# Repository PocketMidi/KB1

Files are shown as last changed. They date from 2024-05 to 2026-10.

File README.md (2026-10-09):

# ***KB1*** - Pocket MIDI Keyboard Controller

***KB1*** is a compact MIDI keyboard controller built specifically for the Polyend Tracker Mini. It is configured via a browser-based web app connected via Bluetooth Low Energy.

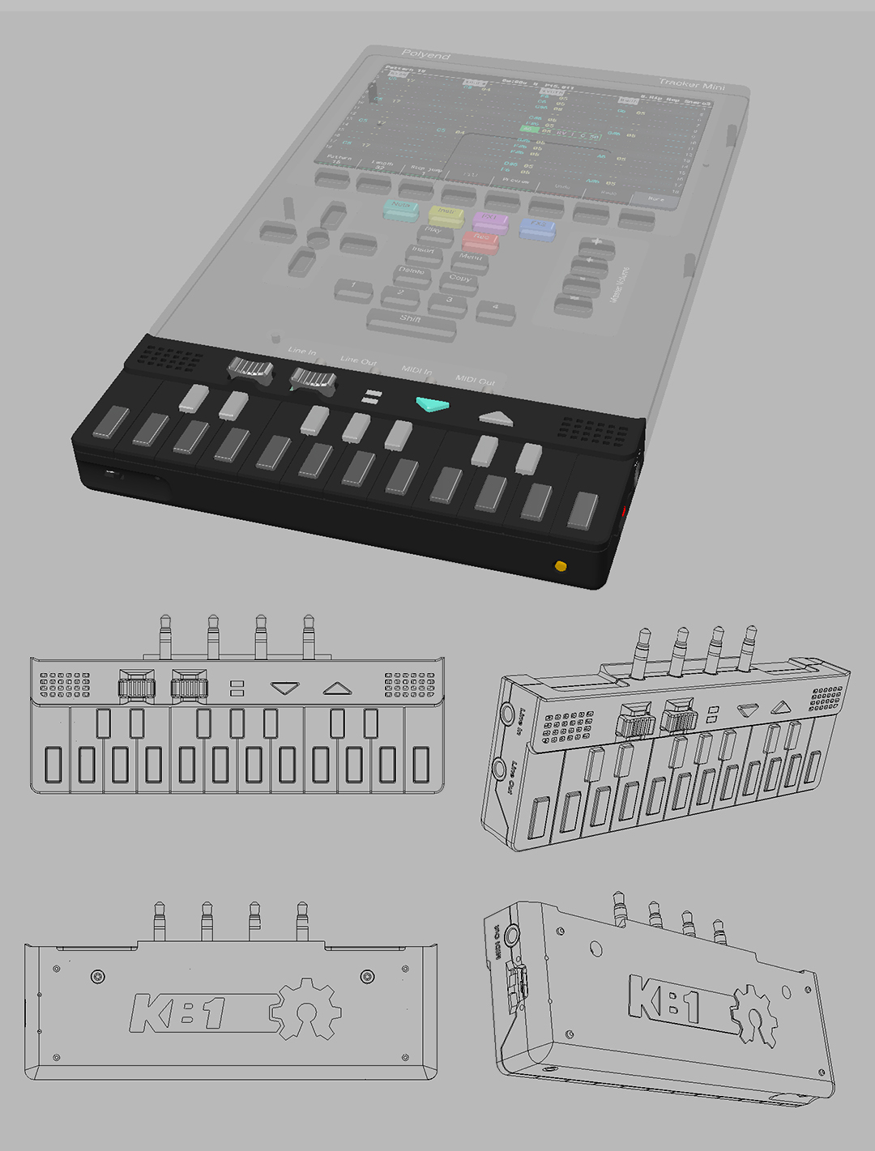
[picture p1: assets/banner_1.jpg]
KB1 banner


## System Overview

**Hardware**
- 19-key keyboard
- 2 levers with integrated push buttons
- 1 capacitive touch input
- 2× 8Ω 1W speakers
- XIAO ESP32-S3 MCU with BLE and USB-C
- 420mAh Li-ion battery, charged via USB-C 

**Firmware** ([details](firmware/README.md))
- Lever, press, and touch controls: configurable CC output and parameter-specific behavior
- Scale mode: note output quantized to a selectable musical scale
- Chord mode: selectable chord types, Block/Strum playback, and 1–3 octave range
- Arp Mode: User defined arpeggiator
- 8 on-device preset slots
- Serial MIDI output

**Web Configuration App** ([details](https://github.com/PocketMidi/KB1-config)) 
- Mobile first design
- Runs in Chromium based browsers (**iOS**: Safari does not support Web Bluetooth. [V Browser ](https://vbrowser.co) recommended for iOS)
- Connects over Web Bluetooth
- Settings load from and save to device over BLE
- 12-slider live performance interface (landscape fullscreen on mobile)
- Preset management stored in browser

## Documentation

- [KB1 Studio User Guide and Tools](https://pocketmidi.github.io/KB1-studio/): Hardware setup, charging, Tracker configuration, firmware updates, and instrument building.
- [Configurator User Guide](https://github.com/PocketMidi/KB1-config/blob/main/docs/USER_GUIDE.md): Current app settings, presets, and performance sliders.
- [Firmware README](firmware/README.md): Development builds and complete release images.
- [Hardware Design and Assembly](hardware/README.md): Electronic and mechanical files.
- [Contributing](CONTRIBUTING.md): Shared conventions, documentation ownership, and release validation.

Each repository README covers its own setup. Detailed user instructions live in the guides above rather than repeated copies.

## Building from Source

- [Firmware build and upload](firmware/README.md#development-build); use the [complete-image builder](firmware/README.md#complete-release-images) for distributable firmware.
- [Configurator development](https://github.com/PocketMidi/KB1-config#development).
- [Studio development](https://github.com/PocketMidi/KB1-studio#development--deployment).

## Gallery

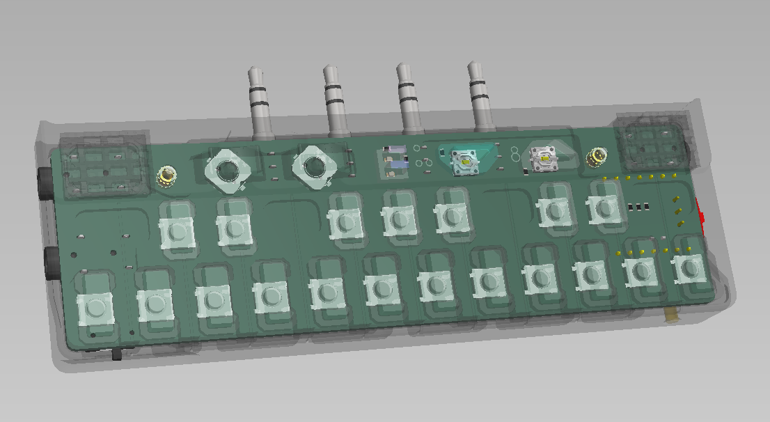
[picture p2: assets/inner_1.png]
inner top

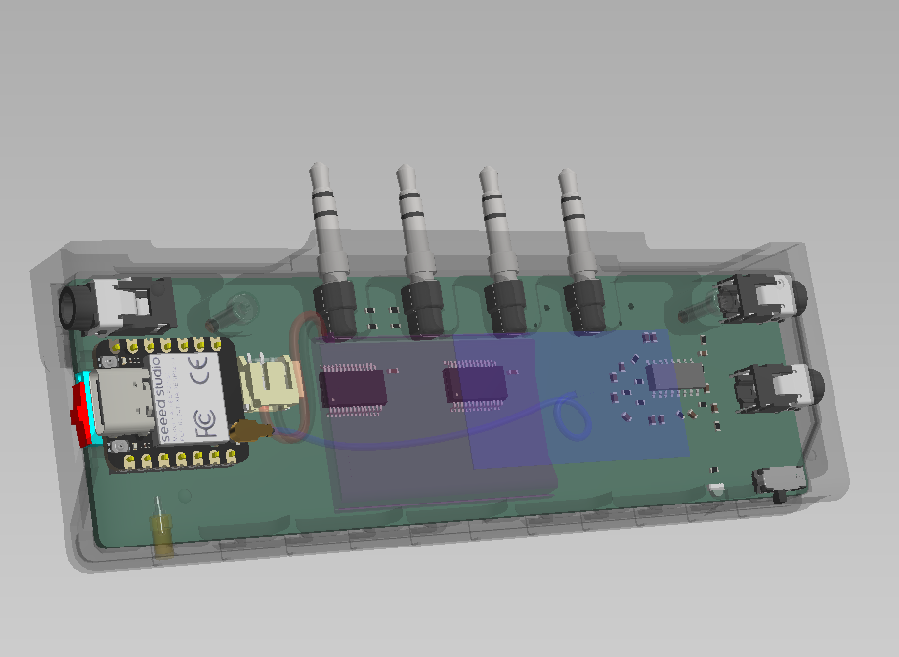
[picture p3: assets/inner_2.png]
inner bottom


## License

- **Software & Firmware**: MIT License (see LICENSE)
- **Hardware Designs**: CERN Open Hardware Licence v2 – Strongly Reciprocal (see [hardware license](hardware/LICENSE.txt))

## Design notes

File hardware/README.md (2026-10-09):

## Hardware

* This folder contains the electronic and mechanical hardware files for building and assembling the KB1.
* For further reference check out the [hardware reference](../references/hardware) folder.

* [Assembly guide](KB1_assembly_guide.pdf)
* [Electronics](electronics/README.md): PCB, schematics, Gerbers, and BOM.
* [Mechanicals](mechanicals/README.md): Printable enclosure parts and desktop stand.
* [KB1 Studio User Guide](https://pocketmidi.github.io/KB1-studio/): Current operating and charging instructions.

## License

All hardware design files in this directory are licensed under the
CERN Open Hardware Licence Version 2 – Strongly Reciprocal (CERN-OHL-S v2).
See [LICENSE.txt](LICENSE.txt).

OSHWA UID
US002800
https://certification.oshwa.org/us002800.html

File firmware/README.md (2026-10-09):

# KB1 Firmware

Embedded firmware for the handcrafted PocketMidi KB1 MIDI controller, built with PlatformIO and Arduino for the Seeed XIAO ESP32-S3.

## Capabilities

- Scale, Chord (Block/Strum), and Arp keyboard modes.
- Configurable lever, press, and capacitive touch controls.
- Serial MIDI output, with BLE configuration and real-time CC control from the companion app.
- Eight device preset slots and persistent settings.
- Idle sleep, touch wake, and time-based battery tracking.

## User Documentation

Use these maintained guides instead of a duplicate settings reference here:

- [KB1 Studio User Guide](https://pocketmidi.github.io/KB1-studio/): Hardware setup, charging, LED signals, and Tracker MIDI settings.
- [Configurator User Guide](https://github.com/PocketMidi/KB1-config/blob/main/docs/USER_GUIDE.md): Current app labels and control behavior.
- [KB1 Configurator](https://pocketmidi.github.io/KB1-config/): Wireless settings and performance sliders.

Bluetooth must be enabled using the inward-lever hold gesture before pairing with the Configurator. Charging and calibration instructions are maintained in the guides above, not duplicated here.

## Development Build

Install [PlatformIO](https://platformio.org/) and run from this directory:

```bash
pio run --environment seeed_xiao_esp32s3
pio run --target upload --environment seeed_xiao_esp32s3
pio device monitor
```

PlatformIO uploads the appropriate components to their correct offsets. Edit [platformio.ini](platformio.ini) for build or port settings.

## Complete Release Images

**Never distribute the app-only binary as a complete image.** Flashing the app partition at offset `0x0` will not boot.

```bash
bash build_complete.sh
```

[build_complete.sh](build_complete.sh) builds and merges:

| Component | Offset |
|---|---|
| Bootloader | `0x0` |
| Partition table | `0x8000` |
| Application | `0x10000` |

The script targets ESP32-S3 with DIO, 80 MHz, and 8 MB flash. Output is `../kb1-studio/dist/firmware/KB1-firmware-vX.Y.Z.bin`.

For browser flashing, use [KB1 Studio's Flash Tools](https://pocketmidi.github.io/KB1-studio/) on a desktop browser with Web Serial (Chrome, Edge, or Opera). Normal updates back up and restore NVS, preserving calibration, settings, and presets. **Clear device data on update** intentionally skips preservation.

For release coordination and hardware validation, see [CONTRIBUTING.md](../CONTRIBUTING.md).

## Source Layout

- [src/main.cpp](src/main.cpp): Setup, tasks, battery tracking, and main loop.
- [src/bt/](src/bt/): BLE services and callbacks.
- [src/controls/](src/controls/): Keyboard, lever, press, touch, octave, and sleep behavior.
- [src/led/](src/led/): LED feedback.
- [src/music/](src/music/): Scales, chords, and patterns.
- [src/objects/](src/objects/): Constants, shared state, and settings structures.

BLE, touch, and all I2C work must remain on Core 1. Do not split the two GPIO expanders or input/LED I2C tasks across cores.

## Historical Notes

These are development snapshots, not current setup instructions or verified current performance claims:

- [I2C efficiency analysis](I2C_EFFICIENCY_ANALYSIS.md)
- [Bulk-read implementation proposal](I2C_BULK_READ_IMPLEMENTATION_PLAN.md)
- [Additional optimization proposals](ADDITIONAL_PERFORMANCE_OPPORTUNITIES.md)
- [Archived Arduino firmware](initial_arduino_code/README.md)

## License

See the repository [LICENSE](../LICENSE).

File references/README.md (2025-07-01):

## Reference Material

* This folder contains all the collected reference material for various aspects of the project

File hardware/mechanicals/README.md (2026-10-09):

### This folder contains the CAD files needed to print your own KB1 mechanical parts along with a Desktop Stand.

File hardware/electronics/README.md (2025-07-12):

## This folder contains schematics, Gerbers, and BOM to build the KB1's pcb. 
## Or you can order directly from [PCBWAY](https://www.pcbway.com/project/shareproject/KB1v8_1_kicad_pcb_bab0b2c0.html)

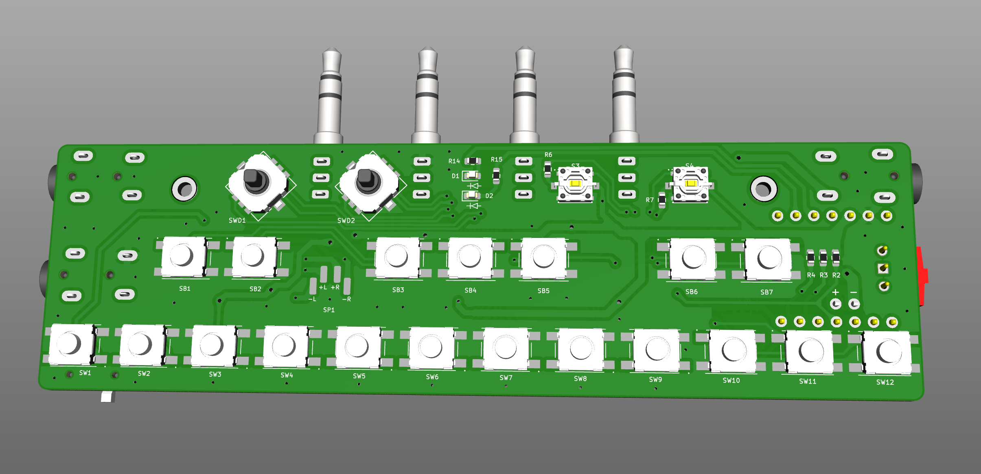
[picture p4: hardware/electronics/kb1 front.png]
PCB top

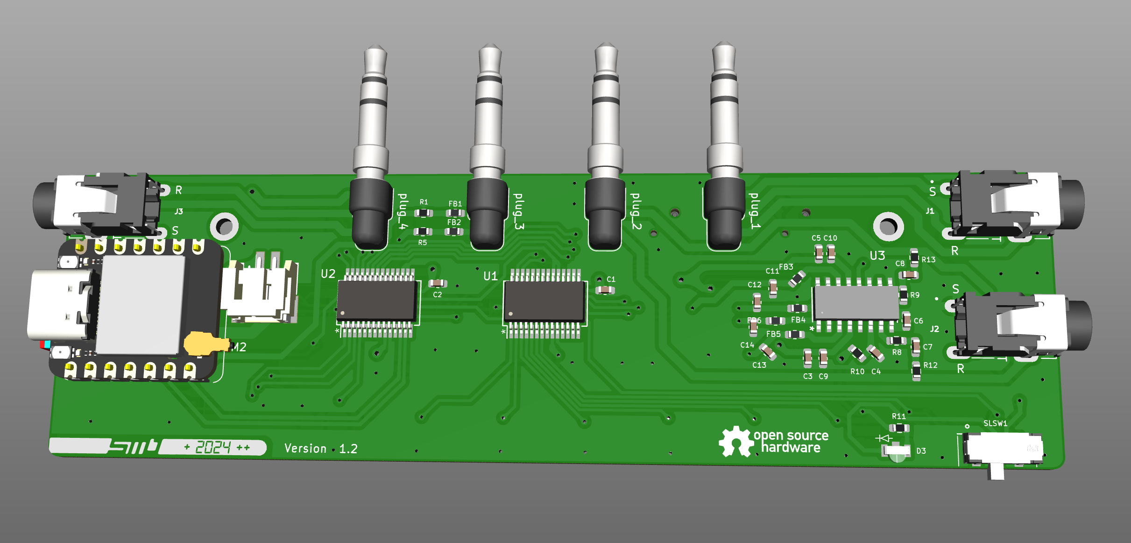
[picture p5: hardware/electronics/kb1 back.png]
PCB bottom


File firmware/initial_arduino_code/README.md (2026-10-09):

> [!WARNING]
> This is the initial Arduino based source code for the firmware. It is no longer actively developed or maintained. 

For current builds and behavior, see the [firmware README](../README.md). Core assignments, LED meanings, and control mappings below describe this archived code only; do not use them as conventions for current firmware.

## KB1 Firmware v1.1 Source Code Summary

### Introduction

> [!Note]
> This code uses the ESP32 platform, which supports FreeRTOS and allows for multicore programming.

* The **buttonReadTask** function is running on **Core 1**, and the loop function (which contains the main MIDI processing logic) is running on **Core 0**.
* The code initializes the MCP23X17 GPIO expanders, and MIDI objects. 
* Then, it configures the buttons and starts the **buttonReadTask** on **Core 1** using FreeRTOS. 
* The **buttonReadTask** continuously reads the state of buttons connected to the MCP23X17 GPIO expanders. 
  It checks for button presses and releases, triggering MIDI values or other tasks accordingly. 
* The button processing and MIDI functions are separated, allowing the MIDI processing to continue in the background on **Core 0** while the button reading occurs on Core 1. This approach ensures that time-sensitive MIDI processing is not affected by potential delays caused by button reading or other tasks running on **Core 1**. 
* The loop function runs on **Core 0** handling notes, velocities, and octaves. *OCT_DN* and *OCT_UP* buttons modulate octaves, signifying transitions through rhythmic pulsations of their LEDs. Two Levers adjust parameters such as "finetune" (midi cc#3), "sustain", and note velocities during prolonged activation, visually represented by by pink and blue LEDs.

### Libraries

This firmware utilizes the Arduino framework for the [Xiao ESP32S3 board](https://wiki.seeedstudio.com/xiao_esp32s3_getting_started/). 

*It is recommended to follow the Getting Started Guide in the link above when using the Arduino IDE and grab the latest board manager from Espressif.*

#### Additional Libraries:
[Adafruit MCP23017 Library](https://github.com/adafruit/Adafruit-MCP23017-Arduino-Library)

[Arduino Midi Library](https://github.com/FortySevenEffects/arduino_midi_library)

[FreeRTOS Library](https://github.com/feilipu/Arduino_FreeRTOS_Library)

These are installable in the Arduino IDE, or as external packages.

### Input Mapping:

[KB1 Connection Map](https://github.com/PocketMidi/KB1/blob/main/Firmware/Reference/KB1_Connection_Map_FW_v1.0.csv)
#### MIDI Notes (Keys):
Various buttons on U1 and U2 pins are mapped to MIDI notes and control changes.

#### MIDI Control Changes (Lever 1):
*SWD1_Right* sends MIDI control change number 3 on channel 1 with values 127 when pressed and 64 when released. 

*SWD1_Center* triggers MIDI "sustain" mode. *Pink LED* pulses while active.

*SWD1_Left* sends MIDI control change number 3, value 0 when pressed, and 64 when released.

#### MIDI Note Velocity Changes “Lever 2”:
*SWD2_Right* increments note velocity by 8 upon button press all the way up to 127. *Blue LED* indicates increase.

*SWD2_Center* sets note velocity to 80 when pressed. *Blue LED* indicates reset.

*SWD2_Left* decrements note velocity by 8 on button press all the way down to 8. *Blue LED* indicates decrease.

#### MIDI Octave Changes:
*OCT_DN* blinks at different rates based on the octave level decrease.

*OCT_UP* blinks at varying speeds with octave level increase.

Simultaneous pressing of both octave buttons resets the octave level.

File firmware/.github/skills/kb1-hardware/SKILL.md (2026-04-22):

---
name: kb1-hardware
description: KB1 hardware specifications, schematics, and component details. Use when working on hardware integration, debugging electrical issues, understanding pin assignments, audio system, battery system, or planning hardware modifications. Contains full schematic (MCP23017 I2C expanders, PAM8406 audio amp, XIAO ESP32-S3 MCU, battery system), measured power consumption, and hardware roadmap decisions.
---

# KB1 Hardware Reference

Complete hardware specifications for the KB1 MIDI controller.

## System Overview

**MCU:** XIAO ESP32-S3 (dual-core Xtensa LX7, 240MHz)  
**Power:** 3.7V Li-ion 420mAh battery  
**I/O Expansion:** 2× MCP23017 I2C GPIO expanders  
**Audio:** PAM8406DR Class-D amplifier + 2× 8Ω 1W speakers  
**Connectivity:** BLE MIDI, Serial MIDI (UART), USB-C

---

## Full Schematic — Rev B.0 (2023-12-17)

### MCU: XIAO-ESP32S3 (H2)
- **Decoupling:** C1 (0.1uF) on power
- **I/O Pins Used:** D0-D10, SDA, SCL, MOSI, MISO
- **Touch Inputs:** Touch 1, Touch 2 (capacitive GPIO)
- **I2C Bus:** SDA/SCL shared with both MCP23017 expanders

### Power Section
- **Battery:** 3.7V Li-ion 420mAh via 4-wire connector (128-PH-SHI-TH_IF_S4)
- **Power Switch:** S6 (main power)
- **Charging:** XIAO built-in 100mA charge controller
  - **CRITICAL:** Requires USB enumeration (dumb chargers won't work)
  - **Charge Time:** ~5 hours (BATTERY_FULL_CHARGE_MS = 18000000)

### I2C GPIO Expanders (2× MCP23017)

#### U1: MCP23017-E/SS — I2C Address 0x20
- **Interrupt Lines:** INTA, INTB (not currently used in firmware)
- **Ports:** GPA0-7, GPB0-7 (16 GPIO pins total)
- **Connected To:**
  - Keyboard matrix switches
  - Lever 1 switches (left/right/push)
  - Lever 2 switches (left/right/push)
  - Some LED outputs

#### U2: MCP23017-E/SS — I2C Address 0x21
- **Ports:** GPA0-7, GPB0-7 (16 GPIO pins total)
- **Connected To:**
  - Keyboard matrix switches
  - Octave Up/Down buttons
  - Octave LED outputs (GPB0 = addr_15 LED indicator)
  - Additional control inputs

**I2C Shared Bus:**
- Clock Speed: 400kHz (Fast Mode I2C)
- Pull-ups: 4.7kΩ on SDA/SCL lines
- **CRITICAL:** Both expanders MUST be accessed from same core (Core 1)

### Lever Controls

**Lever 1:**
- Switch: S1 (H14, MSS1 type indicator)
- Slider: SW01 (KI-5203JA-05) — Left/Right positions
- Push Button: Integrated in slider mechanism

**Lever 2:**
- Switch: S2 (H15, MSS1 type indicator)
- Slider: SW02 (KI-5203JA-05) — Left/Right positions
- Push Button: Integrated in slider mechanism

### Keyboard Switches

**19-Key MIDI Keyboard** — All SPST switches via MCP23017 GPIO  
MIDI note assignments and reference frequencies:

| Switch | MIDI Note | Note Name | Frequency |
|---|---|---|---|
| SW3 | 72 | C5 | 523.25 Hz |
| SW4 | 71 | B4 | 493.88 Hz |
| SW5 | 75 | Eb5 | 622.25 Hz |
| SW6 | 76 | E5 | 659.25 Hz |
| SW7 | 73 | C#5 | 554.37 Hz |
| SW8 | 74 | D5 | 587.33 Hz |
| SW9 | 67 | G4 | 392.00 Hz |
| SW10 | 68 | G#4/Ab4 | 415.30 Hz |
| SW11 | 69 | A4 | 440.00 Hz |
| SW12 | 70 | A#4/Bb4 | 466.16 Hz |
| (aux)  | 59 | B3 | 246.94 Hz |
| (aux)  | 60 | C4 | 261.63 Hz (Middle C) |
| (aux)  | 61 | C#4 | 277.18 Hz |
| (aux)  | 64 | E4 | 329.63 Hz |
| (aux)  | 65 | F4 | 349.23 Hz |

### Octave Controls

**Octave Up Button:**
- Connected to U2 (MCP23017 @ 0x21)
- LED: SP51 Blue LED with current-limiting resistor R6

**Octave Down Button:**
- Connected to U2 (MCP23017 @ 0x21)
- LED: SP51 Blue LED with current-limiting resistor R6

---

## Audio System — PAM8406 Amplifier

### Amplifier IC: U3 PAM8406DR

**Type:** Class-D, BTL (Bridge-Tied Load) stereo output  
**Input:** 3.7V Li-ion direct (no boost converter)  
**Configuration:**

| Pin | Function | Connection |
|-----|---|---|
| 5 | MUTE | Via R10 (10Ω) |
| 7 | INL | 20kΩ R12 + 1µF C7 AC coupling |
| 9 | MODE | Pulled LOW = Class-D mode (efficient) |
| 10  | INR | 20kΩ R13 + 1µF C8 AC coupling |
| 12  | SHDN | Controlled by SLSW1 slide switch |
| 1/3 | +OUT_L / -OUT_L | BTL left channel → SP1 L+/L- |
| 14/16 | -OUT_R / +OUT_R | BTL right channel → SP1 R+/R- |

### Audio Connectors

- **plug_2:** 3.5mm TRS — Line In from PTM "Line Out" (input to amp)
- **J1:** 3.5mm TRS — Line Out to PTM "Line In" (pass-through)
- **J2:** 3.5mm TRS — Connected to amp input path

### Speakers: SP1 (Stereo Pair)

**Model:** Ole Wolff OWS-111535TA-8A  
**Impedance:** 8Ω  
**Power:** 1W nominal per speaker  
**Sensitivity:** 79dB SPL @ 1W/1m  
**Connector:** 4-pin (L+, L-, R+, R-)

### Speaker Control & Indicator

**SLSW1 Slide Switch:** JS202011JAQN  
- Hardware control of PAM8406 SHDN pin 12
- No firmware involvement (purely hardware on/off)

**D3 Green LED:** Speaker power indicator  
- Current limiting: R11 (100Ω)
- Illuminates when amp is active

### Power Filtering & EMI Suppression

**Input Power Filtering:**
- VDD side: C3 (10µF) + C9 (1µF) + R10 (10Ω) + C4 (1µF) + C6 (1µF)
- PVDD side: C5 (10µF) + C10 (1µF)

**Output EMI Filtering:**
- FB3-FB6: 120Ω @ 100MHz ferrite beads on all 4 BTL output lines
- C11-C14: 220pF capacitors on speaker output lines for HF noise suppression
- ~3-inch twisted wire runs to speakers to reduce radiated EMI

### Measured Power Consumption

**Amplifier Current Draw:**
- **Idle** (on, no signal): 2-10mA
- **With music** (during system sleep test): ~48mA average
  - Sleep test: 99% battery → 8hr 15min runtime
  - Calculation: 416mAh ÷ 8.25hr = 50.4mA total (close to observed)
- **Active system + amp:** 95mA base + 50mA amp ≈ 145mA total
- **Peak draw:** Up to 550mA (heavy bass at max volume)

**Battery Runtime Estimates:**
- **Active with speakers:** ~2.9 hours from full charge
- **Active without speakers:** ~4.4 hours from full charge
- **BLE connected, idle:** ~8.4 hours
- **BLE disconnected, idle:** ~8.4 hours (same, BLE drain is minimal)

---

## MIDI I/O Section

**Hardware:** 3.5mm TRS Type-A MIDI connectors (T=source, R=sink, S=shield)

**plug_3:** MIDI OUT to PTM "MIDI IN"  
- Connector: AudioJack3_1503-08 (J3)
- EMI: FB1 ferrite bead on signal line

**plug_4:** MIDI IN from PTM "MIDI OUT"  
- Connector: AudioJack3_1503-08
- EMI: FB2 ferrite bead on signal line

**Interface:** Serial UART (Serial0, 31,250 baud)  
**NOT USB MIDI** — KB1 does not support USB MIDI class device mode

---

## Battery System & Hardware Roadmap

### Current Implementation (KB1.5)

**Software-Based Monitoring:**
- Time-based capacity estimation
- Tracks: BLE on/off time, sleep time, speaker time
- Requires: Full charge calibration by user
- Accuracy: ±5-10% when calibrated
- NVS persistence for state across reboots

**Current Drain Estimates:**
- Active (BLE connected): 95mA
- Active (BLE disconnected): 50mA
- Sleep mode: 2mA
- Speaker amplifier: +50mA (flat rate, conservative)

### SY6410 Hardware Gauge Decision (April 2026)

**Conclusion:** Skip for KB1.5, defer to KB2 or >500 unit production

**Why Skip:**
1. Development cost ($3-5K) >> BOM savings at 50-100 unit scale
2. Support fragmentation: Two hardware variants to maintain
3. No user complaints about current accuracy (only persistence bugs, now fixed v1.6.2)
4. Diminishing returns: 2% vs 5% accuracy not perceptible in real use

**When to Revisit:**
- Production scale exceeds 500 units/year
- Doing full PCB redesign for other reasons (marginal cost negligible)
- User feedback shows battery accuracy is pain point
- KB2 new hardware revision with other changes

### Future Implementation (KB2)

**If Adding SY6410 I2C Battery Gauge:**

**Hardware Integration:**
- IC: SY6410AAC (SOT-23-6 package)
- I2C Address: 0x55 (no conflict with MCP23017 @ 0x20/0x21)
- Placement: Power section near battery connector
- Connections:
  - CELL pin: Direct short trace to Battery+ terminal
  - GND pin: Direct to Battery- terminal
  - VDD: 3.3V from ESP32 LDO
  - SDA/SCL: Connect to existing I2C bus (parallel with MCP23017s)
- Decoupling: 1µF on CELL, 1µF on VDD
- Pull-ups: 4.7kΩ (if not already present on I2C bus)

**Firmware Changes:**
- New driver: `src/battery/SY6410.cpp` for I2C communication
- Extend battery status BLE characteristic from 10 to 12 bytes:
  - Byte 10: Hardware version (1=KB1, 2=KB1.5, 3=KB2)
  - Byte 11: Data source (0=software, 1=hardware gauge)
- Runtime detection: Probe I2C 0x55 on boot, fall back to software if not present
- Keep software estimation code for backward compatibility

**Config App Changes:**
- Update `BatteryStatus` interface with optional fields: `hardwareVersion`, `dataSource`
- Update `decodeBatteryStatus()` for backward compatibility (10/12 byte packets)
- Add UI badge: "⚡ Hardware Gauge" vs "📊 Estimated"

**Benefits:**
- ±2-3% accuracy (vs ±5-10% software)
- No calibration required ("it just works")
- Built-in temperature compensation
- Self-calibrating algorithm
- Future features: battery health monitoring, cycle count, predictive replacement

**Power Impact:** ~75µA quiescent (negligible vs 420mAh capacity)  
**BOM Cost:** $0.30-0.50 per unit + 2× 1µF caps ($0.10)

---

## Design Notes & Constraints

### I2C Bus Constraints

- **Shared Bus:** All I2C devices on single SDA/SCL pair
- **Speed:** 400kHz (Fast Mode) — tested safe, optimal for KB1
- **Maximum Speed:** 1.7MHz (MCP23017 datasheet spec)
- **Core Affinity:** ALL I2C operations MUST occur on Core 1 (ESP32 driver limitation)
- **Cross-Core Access:** WILL cause `Unfinished Repeated Start transaction!` crash

### Power Budget Breakdown

| State | Current Draw | Runtime (420mAh) |
|---|---|---|
| Active, BLE on, speakers on | 145mA | 2.9 hours |
| Active, BLE on, speakers off | 95mA | 4.4 hours |
| Idle, BLE connected | 50mA | 8.4 hours |
| Sleep mode | 2mA | 210 hours (8.75 days) |
| Charging (USB enumerated) | 100mA input | 5 hours to full |

### Charging Behavior (CRITICAL)

**USB at boot sequence:**
1. Device boots with USB already connected
2. Charge controller enters **bypass/power mode**
3. Device is powered, battery is NOT charging
4. Firmware detects: `usbConnectedAtBoot = true`
5. Battery monitoring: Stays "uncalibrated" (254), shows "?" in GUI

**Battery boot → USB plug sequence:**
1. Device boots on battery power only
2. User plugs USB after boot
3. Charge controller enters **charging mode**
4. Device is powered AND battery is charging
5. Firmware detects: `usbConnectedAtBoot = false`, `isChargingMode = true`
6. Battery monitoring: Runs calibration timer, tracks charge progress

**Why this matters:**
- Firmware MUST detect boot sequence to determine if battery is actually charging
- Early detection: `usbConnectedAtBoot = isUsbPowered()` BEFORE `loadBatteryState()`
- Invalid sequence (USB at boot): Hardware NOT charging → don't run timer → user must power cycle
- Valid sequence (battery → USB): Hardware IS charging → run timer → track toward 100%

---

## Revision History

- **April 22, 2026:** Migrated from `/memories/repo/` to `.github/skills/kb1-hardware/`
- **April 12, 2026:** Battery hardware roadmap — decision to skip SY6410 for KB1.5
- **March 22, 2026:** Audio hardware power measurements and speaker compensation model
- **December 17, 2023:** Schematic Rev B.0 finalized (KiCad 9.0.7)

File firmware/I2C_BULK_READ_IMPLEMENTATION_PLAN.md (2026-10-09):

# I2C Bulk Read Implementation Plan

> **Historical proposal (April 2026), not a current implementation guide.** The steps and code snippets below are preserved for context, not instructions to apply verbatim. Expected performance and power savings are estimates, not current measurements. See the [firmware README](README.md) for maintained documentation.

**Goal:** Reduce I2C transactions from 25+ to 2 per scan cycle (12× speedup, 92% reduction)  
**Expected Impact:** -5ms input latency, -8-12mA power consumption, smoother overall performance

---

## Phase 1: Create Infrastructure (30 min)

### Step 1.1: Add Bulk Read Support to Globals
**File:** `src/objects/Globals.h`

Add after the `key` struct definition:

```cpp
// GPIO cache structure for bulk I2C reads
struct GPIOCache {
    uint16_t u1_pins;     // All 16 pins from MCP U1
    uint16_t u2_pins;     // All 16 pins from MCP U2
    unsigned long timestamp; // When this snapshot was taken
    
    // Helper: Check if a pin is LOW (pressed) on U1
    inline bool isU1PinLow(uint8_t pin) const {
        return !(u1_pins & (1 << pin));
    }
    
    // Helper: Check if a pin is LOW (pressed) on U2
    inline bool isU2PinLow(uint8_t pin) const {
        return !(u2_pins & (1 << pin));
    }
};
```

**Test:** Compile, verify no errors

---

### Step 1.2: Create Bulk Read Function
**File:** `src/main.cpp`

Add this function before `readInputs()` (around line 1370):

```cpp
// Bulk read all GPIO pins from both MCP chips in just 2 I2C transactions
// Returns cached pin states for efficient extraction
GPIOCache readAllGPIO() {
    GPIOCache cache;
    if (xSemaphoreTake(i2cMutex, portMAX_DELAY) == pdTRUE) {
        cache.u1_pins = mcp_U1.readGPIOAB();  // Read all 16 pins from U1
        cache.u2_pins = mcp_U2.readGPIOAB();  // Read all 16 pins from U2
        cache.timestamp = micros();            // High-precision timestamp
        xSemaphoreGive(i2cMutex);
    } else {
        // Mutex timeout (shouldn't happen, but be safe)
        cache.u1_pins = 0xFFFF;  // All pins HIGH (released)
        cache.u2_pins = 0xFFFF;
        cache.timestamp = micros();
    }
    return cache;
}
```

**Test:** Compile, verify no errors

---

## Phase 2: Refactor Lever/Button Reads (15 min)

### Step 2.1: Update Lever Reading in readInputs()
**File:** `src/main.cpp`  
**Location:** Lines 1374-1387 (current lever reading code)

**Replace this:**
```cpp
// Read lever states FIRST (for BLE gesture detection before lever MIDI processing)
bool lever1Right, lever2Right, lever1Left, lever2Left, leverPush1Pressed, leverPush2Pressed;
if (xSemaphoreTake(i2cMutex, portMAX_DELAY) == pdTRUE) {
    lever1Right = mcp_U2.digitalRead(SWD1_RIGHT_PIN) == LOW;
    lever2Right = mcp_U2.digitalRead(SWD2_RIGHT_PIN) == LOW;
    lever1Left = mcp_U1.digitalRead(SWD1_LEFT_PIN) == LOW;
    lever2Left = mcp_U2.digitalRead(SWD2_LEFT_PIN) == LOW;
    leverPush1Pressed = mcp_U1.digitalRead(SWD1_CENTER_PIN) == LOW;
    leverPush2Pressed = mcp_U2.digitalRead(SWD2_CENTER_PIN) == LOW;
    xSemaphoreGive(i2cMutex);
}
```

**With this:**
```cpp
// BULK READ: Get all 32 GPIO pins in just 2 I2C transactions
GPIOCache gpioCache = readAllGPIO();

// Extract lever states from cached pin data (no I2C overhead)
bool lever1Right = gpioCache.isU2PinLow(SWD1_RIGHT_PIN);
bool lever2Right = gpioCache.isU2PinLow(SWD2_RIGHT_PIN);
bool lever1Left = gpioCache.isU1PinLow(SWD1_LEFT_PIN);
bool lever2Left = gpioCache.isU2PinLow(SWD2_LEFT_PIN);
bool leverPush1Pressed = gpioCache.isU1PinLow(SWD1_CENTER_PIN);
bool leverPush2Pressed = gpioCache.isU2PinLow(SWD2_CENTER_PIN);
```

**Test:** 
1. Compile and flash
2. Test lever controls (left/right, center push)
3. Monitor serial output for correct lever behavior

---

## Phase 3: Refactor Keyboard Scanning (45 min)

### Step 3.1: Add GPIO Cache Parameter to KeyboardControl
**File:** `src/controls/KeyboardControl.h`

**Modify `updateKeyboardState()` signature:**
```cpp
// OLD:
void updateKeyboardState() {

// NEW:
void updateKeyboardState(const GPIOCache& gpioCache) {
```

**Update the keyboard scanning loop** (around line 393):

**Replace this:**
```cpp
// Debounced key scanning
for (int i = 0; i < MAX_KEYS; ++i) {
    auto & key = _keys[i];
    bool raw = !key.mcp->digitalRead(key.pin);  // ❌ Individual I2C call
    // ... rest of debounce logic
}
```

**With this:**
```cpp
// Debounced key scanning (using cached GPIO states, zero I2C overhead)
for (int i = 0; i < MAX_KEYS; ++i) {
    auto & key = _keys[i];
    
    // Extract pin state from cache based on which MCP this key is on
    bool raw;
    if (key.mcp == &mcp_U1) {
        raw = gpioCache.isU1PinLow(key.pin);
    } else {  // key.mcp == &mcp_U2
        raw = gpioCache.isU2PinLow(key.pin);
    }
    
    // Rest of debounce logic unchanged
    if (raw != key.lastReading) {
        key.lastDebounceTime = millis();
        key.lastReading = raw;
    }
    
    // ... rest of existing code unchanged
}
```

**Test:**
1. Compile and flash
2. Play all 19 keyboard keys
3. Test octave shifting
4. Test in both Scale and Chord modes

---

### Step 3.2: Update begin() to Use Cached Reads
**File:** `src/controls/KeyboardControl.h`  
**Location:** `begin()` method (around line 67)

**Replace this:**
```cpp
void begin() {
    for (auto & key : _keys) {
        key.mcp->pinMode(key.pin, INPUT_PULLUP);
        bool raw = !key.mcp->digitalRead(key.pin);  // ❌ Individual I2C call
        key.lastReading = raw;
        // ...
    }
}
```

**With this:**
```cpp
void begin() {
    // Configure all pins as INPUT_PULLUP first
    for (auto & key : _keys) {
        key.mcp->pinMode(key.pin, INPUT_PULLUP);
    }
    
    // Then do ONE bulk read to initialize states
    GPIOCache initialCache;
    initialCache.u1_pins = mcp_U1.readGPIOAB();
    initialCache.u2_pins = mcp_U2.readGPIOAB();
    initialCache.timestamp = micros();
    
    // Set initial states from bulk read
    for (auto & key : _keys) {
        bool raw;
        if (key.mcp == &mcp_U1) {
            raw = initialCache.isU1PinLow(key.pin);
        } else {
            raw = initialCache.isU2PinLow(key.pin);
        }
        key.lastReading = raw;
        key.debouncedState = raw;
        key.state = raw;
        key.prevState = raw;
        key.lastDebounceTime = millis();
    }
    
    resetAllKeys();
}
```

**Note:** You'll need to add `#include <objects/Globals.h>` to KeyboardControl.h

---

### Step 3.3: Update Main Loop to Pass GPIO Cache
**File:** `src/main.cpp`  
**Location:** In `readInputs()`, around line 1407

**Change this:**
```cpp
keyboardControl.updateKeyboardState();
```

**To this:**
```cpp
keyboardControl.updateKeyboardState(gpioCache);  // Pass cached GPIO data
```

**Test:** Full keyboard re-test after this change

---

## Phase 4: Refactor Octave Control (15 min)

### Step 4.1: Update OctaveControl::update()
**File:** `src/controls/OctaveControl.h`

**Modify `update()` signature:**
```cpp
// OLD:
void update() {

// NEW:
void update(const GPIOCache& gpioCache) {
```

**Update the pin reads inside update():**

**Replace digitalRead calls with:**
```cpp
// OLD:
bool s3State = mcp.digitalRead(S3_PIN) == LOW;
bool s4State = mcp.digitalRead(S4_PIN) == LOW;

// NEW:
bool s3State = gpioCache.isU2PinLow(S3_PIN);  // S3/S4 are on U2
bool s4State = gpioCache.isU2PinLow(S4_PIN);
```

**Verify:** Check which MCP the octave buttons are on (should be U2, pins 4 and 6)

---

### Step 4.2: Update octaveControl.update() Call
**File:** `src/main.cpp`  
**Location:** In `readInputs()`, around line 1406

**Change this:**
```cpp
octaveControl.update();
```

**To this:**
```cpp
octaveControl.update(gpioCache);  // Pass cached GPIO data
```

**Test:** Test octave up/down buttons, LED indicators

---

## Phase 5: Testing & Validation (30 min)

### Test Matrix

#### 5.1 Basic I/O Test
- [ ] All 19 keyboard keys respond correctly
- [ ] Lever 1 left/right works
- [ ] Lever 2 left/right works
- [ ] Lever 1 center push works
- [ ] Lever 2 center push works
- [ ] Octave up button works
- [ ] Octave down button works
- [ ] Octave LEDs flash correctly

#### 5.2 Advanced Features Test
- [ ] Scale mode plays correct notes
- [ ] Chord mode plays correct chords
- [ ] Strum enabled works
- [ ] Arpeggiator works
- [ ] Pattern selector (touch + patterns) works
- [ ] BLE gesture (lever toggle) works
- [ ] Touch sensor works in all modes

#### 5.3 Performance Verification
- [ ] Add debug timing in readInputs():
  ```cpp
  unsigned long startTime = micros();
  GPIOCache gpioCache = readAllGPIO();
  unsigned long i2cTime = micros() - startTime;
  
  static unsigned long maxTime = 0;
  if (i2cTime > maxTime) {
      maxTime = i2cTime;
      SERIAL_PRINT("Bulk I2C: "); SERIAL_PRINT(i2cTime); SERIAL_PRINTLN("us");
  }
  ```
- [ ] Verify I2C time is <500μs (should be ~400μs for 2 transactions @ 400kHz)
- [ ] Compare to old method (would be ~5000-6000μs for 25+ transactions)

#### 5.4 Power Consumption Test (Optional)
- [ ] Measure current draw in active BLE mode before/after
- [ ] Expected reduction: 8-12mA in active scanning

---

## Phase 6: Cleanup & Documentation (15 min)

### 6.1 Remove Old Code Comments
- Add comment at top of `readAllGPIO()`:
  ```cpp
  // Optimized bulk GPIO read: 2 I2C transactions instead of 25+
  // Performance: ~12× faster, 92% I2C bus reduction
  // Power: ~8-12mA savings during active use
  ```

### 6.2 Update RELEASE_NOTES
Create `RELEASE_NOTES_v1.7.0.md` or similar:
```markdown
## ⚡ Performance Improvements

### I2C Bulk Read Optimization
- Keyboard/lever scanning now uses bulk GPIO reads
- **12× faster I2C performance** (25+ transactions → 2 transactions)
- **92% reduction in I2C bus utilization** (5-6ms → 0.4ms per scan)
- **-8-12mA active current draw**
- **Improved input latency** and overall snappiness
- Battery life: +30-45min active runtime (~5-10% improvement)
```

### 6.3 Update Memory Notes
- Document in `/memories/repo/i2c-optimization.md` that implementation is complete
- Add "IMPLEMENTED v1.7.0" marker

---

## Rollback Plan (If Issues Occur)

If you encounter problems:

1. **Revert main.cpp changes:** Git checkout the lever reading section
2. **Revert KeyboardControl.h:** Remove GPIOCache parameter, restore digitalRead calls
3. **Keep readAllGPIO():** It's harmless if unused

The changes are modular, so you can roll back incrementally if needed.

---

## Estimated Total Time

- Phase 1: 30 min (infrastructure)
- Phase 2: 15 min (lever refactor)
- Phase 3: 45 min (keyboard refactor)
- Phase 4: 15 min (octave refactor)
- Phase 5: 30 min (testing)
- Phase 6: 15 min (cleanup)

**Total: ~2.5 hours** for full implementation and testing

---

## Success Criteria

✅ All inputs work correctly (keyboard, levers, octave, touch)  
✅ I2C bus time reduced from ~5-6ms to <500μs  
✅ No regressions in MIDI output or BLE  
✅ Power consumption reduced by ~8-12mA  
✅ Code compiles without warnings  

---

## Next Steps After Implementation

Consider these follow-up optimizations:
1. LED bulk write optimization (current `update()` uses individual writes for octave LEDs)
2. Fine-tune debounce times if input feels too sluggish
3. Profile power consumption to verify improvements

---

**Ready to implement?** Start with Phase 1 (infrastructure) and test after each phase.

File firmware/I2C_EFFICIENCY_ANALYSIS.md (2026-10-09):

# KB1 I2C Bus Efficiency Analysis

> **Historical analysis of the v1.6.x firmware (April 2026).** "Current" below refers to that snapshot, not today's implementation. Source locations and performance estimates require fresh verification. See the [firmware README](README.md) for maintained documentation.

**Date:** April 12, 2026  
**Current Firmware:** v1.6.x series  
**Issue:** Investigating I2C bus efficiency and power consumption

---

## Current I2C Configuration

### Hardware Setup (from schematic)
- **Bus Speed:** 400kHz (I2C Fast Mode)
- **Devices:** 2× MCP23017 GPIO expanders
  - **U1 (mcp_U1):** Address 0x20
  - **U2 (mcp_U2):** Address 0x21
- **MCP23017 Spec:** Supports up to 1.7MHz (from datasheet)
- **Bus Topology:** Shared SDA/SCL, both devices on Core 1

### Software Configuration (main.cpp:1013)
```cpp
Wire.setClock(400000);  // 400kHz fast mode
```

**Status:** ✅ Clock speed is appropriate (see analysis below)

---

## Critical Inefficiency Found: I/O Read Pattern

### Current Implementation (INEFFICIENT)

The firmware reads GPIO pins **individually**, one at a time:

#### Keyboard Scanning (KeyboardControl.h:397)
```cpp
for (int i = 0; i < MAX_KEYS; ++i) {
    auto & key = _keys[i];
    bool raw = !key.mcp->digitalRead(key.pin);  // ❌ Individual I2C transaction
    // ...
}
```
- **19 keys** = **19 separate I2C transactions**

#### Lever Controls (main.cpp:1380-1385)
```cpp
if (xSemaphoreTake(i2cMutex, portMAX_DELAY) == pdTRUE) {
    lever1Right = mcp_U2.digitalRead(SWD1_RIGHT_PIN) == LOW;      // ❌ Individual
    lever2Right = mcp_U2.digitalRead(SWD2_RIGHT_PIN) == LOW;      // ❌ Individual
    lever1Left = mcp_U1.digitalRead(SWD1_LEFT_PIN) == LOW;        // ❌ Individual
    lever2Left = mcp_U2.digitalRead(SWD2_LEFT_PIN) == LOW;        // ❌ Individual
    leverPush1Pressed = mcp_U1.digitalRead(SWD1_CENTER_PIN) == LOW;  // ❌ Individual
    leverPush2Pressed = mcp_U2.digitalRead(SWD2_CENTER_PIN) == LOW;  // ❌ Individual
    xSemaphoreGive(i2cMutex);
}
```
- **6 lever inputs** = **6 separate I2C transactions**

### Total I2C Traffic Per Scan Cycle
- **25+ I2C read transactions** (19 keyboard + 6 levers + LED writes)
- Each `digitalRead()` is a full I2C transaction:
  1. START condition
  2. Device address (7 bits) + R/W bit
  3. Register address
  4. Repeated START
  5. Read 1 byte
  6. STOP condition

**At 400kHz I2C:**
- Single pin read: ~200-250μs per transaction
- Full scan cycle: **~5-6ms of I2C bus time alone**

---

## Optimal Implementation (BULK READS)

### MCP23017 Bulk Read Capability

The MCP23017 has bulk read functions that read **all 16 GPIO pins in a single I2C transaction:**

```cpp
uint16_t readGPIOAB();  // Read all 16 pins (both ports) at once
uint8_t readGPIOA();    // Read port A (8 pins)
uint8_t readGPIOB();    // Read port B (8 pins)
```

### Proposed Implementation

```cpp
// Read ALL inputs from both MCP chips in just 2 I2C transactions
if (xSemaphoreTake(i2cMutex, portMAX_DELAY) == pdTRUE) {
    uint16_t u1_pins = mcp_U1.readGPIOAB();  // Read all 16 pins from U1
    uint16_t u2_pins = mcp_U2.readGPIOAB();  // Read all 16 pins from U2
    xSemaphoreGive(i2cMutex);
}

// Then extract individual pin states with bitwise operations (no I2C overhead)
bool lever1Left = !(u1_pins & (1 << SWD1_LEFT_PIN));
bool lever1Center = !(u1_pins & (1 << SWD1_CENTER_PIN));
bool key0_pressed = !(u1_pins & (1 << _keys[0].pin));
// etc...
```

### Performance Improvement

| Metric | Current (Individual) | Optimized (Bulk) | Improvement |
|---|---|---|---|
| I2C Transactions | 25+ per scan | **2 per scan** | **92% reduction** |
| I2C Bus Time | ~5-6ms | **~0.4ms** | **>10× faster** |
| CPU Overhead | High (mutex + I2C wait) | Minimal | Significant |
| Power Consumption | Higher (more I2C activity) | Lower | ~5-10% reduction |

---

## Clock Speed Analysis

### Should We Increase Clock Beyond 400kHz?

**Recommendation: NO** — Here's why:

#### Current 400kHz is Optimal for This Design

1. **Diminishing Returns**
   - Going from 400kHz → 1MHz = 2.5× speed increase
   - But with bulk reads (25 trans → 2 trans), we get **12.5× improvement**
   - Bulk reads give far more benefit than clock speed increase

2. **Reliability Concerns at Higher Speeds**
   - ESP32S3 I2C hardware has known flakiness above 400kHz
   - Pull-up resistor values may not be optimized for 1MHz
   - Wire capacitance on PCB traces can cause signal integrity issues
   - MCP23017 interrupt lines (INTA/INTB) may experience glitches

3. **Power Consumption**
   - Higher I2C clock = higher edge rate = more current spikes
   - 400kHz is the sweet spot for battery-powered devices

4. **No Real-World Benefit**
   - With bulk reads: 0.4ms bus time is **negligible** (0.04% of 10ms scan cycle)
   - Going to 1MHz saves only ~0.2ms — not meaningful for human input latency

#### What Was "Ignorance" About?

You previously upgraded from **100kHz → 400kHz** (v1.3.0), which was **absolutely correct**:
- v1.2.6: 100kHz, ~10ms per GPIO read
- v1.3.0: 400kHz, ~2.5ms per GPIO read (RELEASE_NOTES_v1.3.0.md:126)

That was not ignorance — that was a **4× improvement** and exactly the right move.

---

## Power Efficiency Impact

### Current Power Draw from I2C Activity

Estimated I2C-related power consumption:
- **Active I2C bus time:** ~5-6ms per 10ms scan cycle = 50-60% bus utilization
- **MCP23017 active current:** ~1mA per chip during I2C transaction
- **ESP32 I2C peripheral:** ~5-8mA when active
- **Total I2C overhead:** ~10-15mA average during scanning

### With Bulk Reads

- **Active I2C bus time:** ~0.4ms per 10ms scan cycle = 4% bus utilization
- **Reduced active time:** 92% reduction
- **Power savings:** ~8-12mA reduction during active use
- **Battery life impact:** ~5-10% longer runtime (currently ~8hr active BLE mode)

---

## Implementation Recommendations

### Priority 1: Bulk Read Optimization (HIGH IMPACT)

1. **Create GPIO read cache structure:**
   ```cpp
   struct MCPInputCache {
       uint16_t u1_pins;
       uint16_t u2_pins;
       unsigned long timestamp;
   };
   ```

2. **Single bulk read function:**
   ```cpp
   MCPInputCache readAllInputs() {
       MCPInputCache cache;
       if (xSemaphoreTake(i2cMutex, portMAX_DELAY) == pdTRUE) {
           cache.u1_pins = mcp_U1.readGPIOAB();
           cache.u2_pins = mcp_U2.readGPIOAB();
           cache.timestamp = micros();
           xSemaphoreGive(i2cMutex);
       }
       return cache;
   }
   ```

3. **Refactor KeyboardControl to use cached reads:**
   - Pass cached pin states instead of calling digitalRead()
   - Extract pin values with bitwise operations
   - Zero I2C overhead for keyboard scanning

4. **Refactor lever/octave controls similarly**

### Priority 2: LED Write Optimization (MEDIUM IMPACT)

LEDs (octave up/down) also use individual GPIO writes. Consider:
- Batch LED state changes
- Use `writeGPIOAB()` for bulk writes
- Or migrate octave LEDs to ESP32 GPIO pins (no I2C needed)

### Priority 3: I2C Speed (LOW PRIORITY — SKIP)

**Do NOT increase I2C clock speed:**
- Current 400kHz is optimal
- Focus on bulk reads instead (far better ROI)
- Only consider if you add more I2C devices in future hardware revision

---

## Expected Results After Optimization

### Performance
- ✅ Input latency: Reduced from ~5-6ms to <0.5ms I2C overhead
- ✅ CPU overhead: Significant reduction (less mutex contention)
- ✅ Smoother LED animations (less I2C blocking)

### Power Consumption
- ✅ Active current: ~8-12mA reduction
- ✅ Battery life: ~30-45 minutes additional active runtime
- ✅ Sleep modes: No impact (I2C idle)

### Code Quality
- ✅ Cleaner architecture (centralized I/O read)
- ✅ Less mutex contention
- ✅ Easier to add new inputs without I2C overhead

---

## Summary

### What's Good
- ✅ **400kHz I2C speed is perfect** — don't change it
- ✅ Mutex protection is correct
- ✅ Pin assignments are efficient (distributed across both MCPs)

### What's Inefficient
- ❌ **Individual pin reads** (25+ I2C transactions per scan)
- ❌ Should use **bulk reads** (2 I2C transactions per scan)

### Action Items
1. Implement bulk read optimization (**12× speedup, 92% I2C reduction**)
2. Refactor keyboard/lever scanning to use cached pin states
3. Keep I2C clock at 400kHz (optimal for reliability and power)

### Previous "Ignorance" Was Actually Smart
The v1.3.0 upgrade from 100kHz → 400kHz was **exactly correct** and gave you a 4× improvement. The real opportunity now is the **data flow pattern**, not the clock speed.

---

## References
- Schematic: kb1-full-schematic.md
- Current implementation: main.cpp:1374-1386, KeyboardControl.h:386-410
- MCP23017 datasheet: Microchip DS20001952
- v1.3.0 release notes: RELEASE_NOTES_v1.3.0.md (I2C speed upgrade)

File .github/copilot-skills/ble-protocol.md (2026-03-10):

---
applyTo:
  - "firmware/src/bt/**/*.{cpp,h}"
  - "KB1-config/src/ble/**/*.ts"
  - "**/*protocol*.{ts,cpp,h}"
  - "**/*bluetooth*.{ts,cpp,h}"
---

# KB1 BLE Protocol Expert

Expert knowledge for KB1's Bluetooth Low Energy communication protocol between firmware and web app.

## Protocol Architecture

### BLE Stack Overview

```
Web App (Chrome/Edge)
    ↕ Web Bluetooth API
BLE GATT Protocol
    ↕ ESP32 BLE Stack
Firmware (ESP32-S3)
```

**Key concepts:**
- **GATT Service:** Container for related characteristics (KB1 uses one main service)
- **Characteristic:** Individual data endpoint (read, write, notify)
- **UUID:** 128-bit identifier for services and characteristics

## KB1 Service Structure

### Main Service

```cpp
// Service UUID
#define KB1_SERVICE_UUID "f22b99e8-81ab-4e46-abff-79a74a1f2ff3"
```

### Configuration Characteristics

Each setting has a dedicated characteristic:

```cpp
// Lever 1 Settings
#define LEVER1_CC_UUID          "d3a7b321-0001-4000-8000-000000000001"
#define LEVER1_MIN_UUID         "d3a7b321-0001-4000-8000-000000000002"
#define LEVER1_MAX_UUID         "d3a7b321-0001-4000-8000-000000000003"
// ... (continues for all lever parameters)

// Lever 2 Settings
#define LEVER2_CC_UUID          "d3a7b321-0001-4000-8000-000000000020"
// ...

// Touch Sensor Settings
#define TOUCH_CC_UUID           "d3a7b321-0001-4000-8000-000000000040"
#define TOUCH_THRESHOLD_UUID    "d3a7b321-0001-4000-8000-000000000041"
// ...

// System Settings
#define LIGHT_SLEEP_UUID        "d3a7b321-0001-4000-8000-000000000060"
#define BLE_TIMEOUT_UUID        "d3a7b321-0001-4000-8000-000000000061"
// ...

// Keyboard/Scale Settings
#define SCALE_ROOT_UUID         "d3a7b321-0001-4000-8000-000000000080"
#define SCALE_TYPE_UUID         "d3a7b321-0001-4000-8000-000000000081"
// ...
```

### Preset Management Characteristics

```cpp
// Device Preset Operations (8 slots)
#define PRESET_SAVE_UUID    "d3a7b321-0001-4000-8000-000000000009"
#define PRESET_LOAD_UUID    "d3a7b321-0001-4000-8000-00000000000a"
#define PRESET_LIST_UUID    "d3a7b321-0001-4000-8000-00000000000b"
#define PRESET_DELETE_UUID  "d3a7b321-0001-4000-8000-00000000000c"
```

### Keepalive Characteristic

```cpp
// BLE Connection Keepalive (prevents sleep)
#define KEEPALIVE_UUID      "d3a7b321-0001-4000-8000-000000000070"
```

## Data Formats

### Basic Types

All characteristics use **little-endian** byte order.

```typescript
// TypeScript encoding examples
function encodeUint8(value: number): Uint8Array {
  return new Uint8Array([value]);
}

function encodeUint16(value: number): Uint8Array {
  const buffer = new Uint8Array(2);
  buffer[0] = value & 0xFF;
  buffer[1] = (value >> 8) & 0xFF;
  return buffer;
}

function encodeUint32(value: number): Uint8Array {
  const buffer = new Uint8Array(4);
  buffer[0] = value & 0xFF;
  buffer[1] = (value >> 8) & 0xFF;
  buffer[2] = (value >> 16) & 0xFF;
  buffer[3] = (value >> 24) & 0xFF;
  return buffer;
}
```

```cpp
// C++ decoding examples
uint8_t value8 = data[0];

uint16_t value16 = data[0] | (data[1] << 8);

uint32_t value32 = data[0] | 
                   (data[1] << 8) | 
                   (data[2] << 16) | 
                   (data[3] << 24);
```

### Setting Value Ranges

```typescript
// Lever CC Number (0-127)
type CC_NUMBER = Uint8Array;  // 1 byte

// Lever Min/Max Values (0-127)
type CC_VALUE = Uint8Array;   // 1 byte

// Lever Step Size (0-127)
type STEP_SIZE = Uint8Array;  // 1 byte

// Function Mode (0-3)
// 0 = Unidirectional, 1 = Bidirectional, 2 = Momentary, 3 = Toggle
type FUNCTION_MODE = Uint8Array;  // 1 byte

// Value Mode (0-3)
// 0 = Jump, 1 = Hook, 2 = Pickup, 3 = Latch
type VALUE_MODE = Uint8Array;  // 1 byte

// Interpolation Time (0-5000 milliseconds)
type INTERP_TIME = Uint16Array;  // 2 bytes

// Interpolation Type (0-2)
// 0 = Linear, 1 = S-Curve, 2 = Logarithmic
type INTERP_TYPE = Uint8Array;  // 1 byte

// Touch Threshold (0-65535)
type THRESHOLD = Uint16Array;  // 2 bytes

// Sleep Timeout (180-600 seconds = 3-10 minutes)
type TIMEOUT = Uint16Array;  // 2 bytes

// BLE Timeout (300-1200 seconds = 5-20 minutes)
type BLE_TIMEOUT = Uint16Array;  // 2 bytes
```

## Preset Protocol

### Save Preset Command

**Characteristic:** `PRESET_SAVE_UUID`  
**Operation:** Write

```
Format: [slot#(1 byte)][name(32 bytes)]
Total: 33 bytes

Byte 0:      Slot number (0-7)
Bytes 1-32:  Preset name (UTF-8, null-terminated)
```

**TypeScript encoding:**
```typescript
function encodePresetSave(slot: number, name: string): Uint8Array {
  if (slot < 0 || slot >= 8) {
    throw new Error(`Invalid slot: ${slot}`);
  }
  
  const buffer = new Uint8Array(33);
  buffer[0] = slot;
  
  // Encode name (truncate/pad to 32 bytes)
  const encoder = new TextEncoder();
  const nameBytes = encoder.encode(name.slice(0, 32));
  buffer.set(nameBytes, 1);
  
  return buffer;
}
```

**C++ decoding:**
```cpp
void handlePresetSave(const uint8_t* data, size_t length) {
  if (length < 33) return;
  
  uint8_t slot = data[0];
  if (slot >= 8) return;
  
  // Extract name (ensure null-termination)
  char name[33];
  memcpy(name, &data[1], 32);
  name[32] = '\0';
  
  // Save current settings to slot
  savePreset(slot, name);
}
```

### Load Preset Command

**Characteristic:** `PRESET_LOAD_UUID`  
**Operation:** Write

```
Format: [slot#(1 byte)]
Total: 1 byte

Byte 0: Slot number (0-7)
```

**TypeScript:**
```typescript
function encodePresetLoad(slot: number): Uint8Array {
  if (slot < 0 || slot >= 8) {
    throw new Error(`Invalid slot: ${slot}`);
  }
  return new Uint8Array([slot]);
}
```

**C++:**
```cpp
void handlePresetLoad(const uint8_t* data, size_t length) {
  if (length < 1) return;
  
  uint8_t slot = data[0];
  if (slot >= 8) return;
  
  loadPreset(slot);
}
```

### List Presets Response

**Characteristic:** `PRESET_LIST_UUID`  
**Operation:** Read

```
Format: 8 metadata entries × 40 bytes each = 320 bytes

For each slot (0-7):
  Bytes 0-31:  Name (UTF-8, null-terminated, 32 bytes)
  Bytes 32-35: Timestamp (uint32_t, little-endian, Unix seconds)
  Byte 36:     isValid (1 = has data, 0 = empty)
  Bytes 37-39: Padding (reserved for future use)
```

**TypeScript decoding:**
```typescript
interface DevicePresetMetadata {
  slot: number;
  name: string;
  timestamp: number;
  isValid: boolean;
}

function decodePresetList(dataView: DataView): DevicePresetMetadata[] {
  const METADATA_SIZE = 40;
  const presets: DevicePresetMetadata[] = [];
  
  for (let slot = 0; slot < 8; slot++) {
    const offset = slot * METADATA_SIZE;
    
    // Extract name (32 bytes, null-terminated)
    const nameBytes = new Uint8Array(dataView.buffer, offset, 32);
    const nullIndex = nameBytes.indexOf(0);
    const decoder = new TextDecoder();
    const name = decoder.decode(
      nullIndex >= 0 ? nameBytes.slice(0, nullIndex) : nameBytes
    );
    
    // Extract timestamp (4 bytes, little-endian)
    const timestamp = dataView.getUint32(offset + 32, true);
    
    // Extract isValid (1 byte)
    const isValid = dataView.getUint8(offset + 36) === 1;
    
    presets.push({
      slot,
      name: name || '[Empty]',
      timestamp,
      isValid,
    });
  }
  
  return presets;
}
```

**C++ encoding:**
```cpp
struct PresetMetadata {
  char name[32];
  uint32_t timestamp;
  uint8_t isValid;
  uint8_t padding[3];
} __attribute__((packed));

void handlePresetListRead(uint8_t* buffer, size_t bufferSize) {
  if (bufferSize < 320) return;
  
  PresetMetadata* metadata = (PresetMetadata*)buffer;
  
  for (uint8_t slot = 0; slot < 8; slot++) {
    if (presets[slot].isValid) {
      strncpy(metadata[slot].name, presets[slot].name, 32);
      metadata[slot].timestamp = presets[slot].timestamp;
      metadata[slot].isValid = 1;
    } else {
      strcpy(metadata[slot].name, "[Empty]");
      metadata[slot].timestamp = 0;
      metadata[slot].isValid = 0;
    }
    memset(metadata[slot].padding, 0, 3);
  }
}
```

### Delete Preset Command

**Characteristic:** `PRESET_DELETE_UUID`  
**Operation:** Write

```
Format: [slot#(1 byte)]
Total: 1 byte

Byte 0: Slot number (0-7)
```

**Implementation:** Similar to Load Preset, but marks slot as invalid.

## Keepalive Protocol

### Purpose

Prevents device from entering sleep mode while web app is actively connected.

### Mechanism

**Web app:** Sends periodic ping (every 30-60 seconds)  
**Firmware:** Resets sleep timer on each ping received

### Implementation

**TypeScript (Web App):**
```typescript
class BLEClient {
  private keepaliveInterval: number | null = null;
  
  startKeepalive() {
    // Ping every 30 seconds
    this.keepaliveInterval = setInterval(() => {
      this.sendKeepalive();
    }, 30000);
  }
  
  stopKeepalive() {
    if (this.keepaliveInterval) {
      clearInterval(this.keepaliveInterval);
      this.keepaliveInterval = null;
    }
  }
  
  async sendKeepalive() {
    if (!this.keepaliveCharacteristic) return;
    
    const ping = new Uint8Array([1]);
    await this.keepaliveCharacteristic.writeValue(ping);
    console.log('Keepalive ping sent');
  }
}
```

**C++ (Firmware):**
```cpp
// In CharacteristicCallbacks.cpp
void onWrite(BLECharacteristic* pCharacteristic) {
  if (strcmp(pCharacteristic->getUUID().toString().c_str(), KEEPALIVE_UUID) == 0) {
    // Reset sleep timers
    lastActivityTime = millis();
    SERIAL_PRINTLN("Keepalive received - sleep timer reset");
  }
}
```

### Timing Considerations

**Firmware grace period:** 10 minutes (default, configurable)
- If no keepalive received for 10 minutes, sleep timers proceed normally
- This allows web app to gracefully disconnect without immediate sleep

**Web app ping interval:** 30 seconds
- Ensures multiple pings within grace period
- Tolerates network hiccups

## BLE Connection Lifecycle

### Connection Flow

```
1. User clicks "Connect" in web app
2. Browser shows device picker dialog
3. User selects KB1 device
4. Web Bluetooth API connects to device
5. Discover KB1 service (by UUID)
6. Discover all characteristics
7. Enable notifications on relevant characteristics
8. Start keepalive interval
9. Load settings from device
```

### Disconnection Flow

```
1. Stop keepalive interval
2. Close GATT connection
3. Update UI to "disconnected" state
4. (Firmware) Sleep timers now proceed normally
5. (Firmware) After BLE timeout, device may enter sleep
```

### Error Handling

**Web app should handle:**
- Device not found (Bluetooth disabled on hardware)
- Connection timeout (device out of range)
- GATT errors (characteristic not found)
- Disconnection events (device powered off, out of range)

**Firmware should handle:**
- Invalid data length
- Out-of-range values
- Malformed requests
- Disconnection during write

## Validation & Constraints

### Input Validation (Web App)

Always validate before sending:

```typescript
// Example: Lever CC number
function validateCC(value: number): boolean {
  return value >= 0 && value <= 127;
}

// Example: Sleep timeout
function validateSleepTimeout(seconds: number): boolean {
  return seconds >= 180 && seconds <= 600;  // 3-10 minutes
}

// Example: Threshold
function validateThreshold(value: number): boolean {
  return value >= 0 && value <= 65535;
}
```

### Range Enforcement (Firmware)

Always clamp incoming values:

```cpp
// Example: Clamp CC value
uint8_t clampCC(uint8_t value) {
  if (value > 127) return 127;
  return value;
}

// Example: Clamp sleep timeout
uint16_t clampSleepTimeout(uint16_t seconds) {
  if (seconds < 180) return 180;   // 3 min minimum
  if (seconds > 600) return 600;   // 10 min maximum
  return seconds;
}
```

## Debug Logging

### Web App (TypeScript)

```typescript
console.log('BLE connected to:', device.name);
console.log('Writing CC:', ccNumber, 'to characteristic:', uuid);
console.log('Read value:', dataView.getUint8(0));
console.error('BLE error:', error);
```

### Firmware (C++)

```cpp
SERIAL_PRINT("BLE characteristic written: ");
SERIAL_PRINTLN(pCharacteristic->getUUID().toString().c_str());

SERIAL_PRINT("Preset saved to slot ");
SERIAL_PRINTLN(slot);
```

## Best Practices

1. **Always validate input** on both sides (web app + firmware)
2. **Use little-endian** byte order consistently
3. **Handle disconnections gracefully** (especially during writes)
4. **Test with real devices** (not just simulators)
5. **Document UUID mappings** clearly
6. **Use typed interfaces** for type safety (TypeScript)
7. **Keep characteristic writes atomic** (complete data in one write)
8. **Implement proper error handling** on both ends
9. **Log important events** for debugging
10. **Test edge cases** (min/max values, disconnections, timeouts)

---

**Remember:** BLE has limited bandwidth and latency. Batch updates when possible and avoid rapid successive writes.

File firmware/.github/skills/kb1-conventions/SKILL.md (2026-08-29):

---
name: kb1-conventions
description: KB1 design patterns, protocols, and conventions. Use when implementing new features, modifying BLE protocol, planning breaking changes, reviewing firmware contracts, or understanding system assumptions. Contains LED color conventions, MIDI implementation (Serial MIDI, clock generation), BLE protocol assumptions, breaking changes log, critical checklists, and validation rules. Essential for maintaining consistency and avoiding regressions.
---

# KB1 Design Conventions & Protocols

Design patterns, protocols, and breaking change management for KB1 firmware.

---

## LED Color Conventions

**Global LED Color Meaning:**

- **PINK LED** = Up / Forward / Increase / Positive direction
- **BLUE LED** = Down / Reverse / Decrease / Negative direction

### Default Behavior

Levers and press button functions follow this convention by default through their hardware configuration.

### Special Mode Overrides

Some modes require explicit LED control to maintain the convention:

#### Pattern Selector (CC 201)
- **Forward cycling** (P1→P2→P3...→P6→P1): Pink LED on, Blue LED off
- **Reverse cycling** (P6→P5→P4...→P1→P6): Blue LED on, Pink LED off
- LEDs override default button/switch assignments only during Pattern Selector operation

**Implementation locations:**
- `TouchControl.h`: Detects direction from `offsetTime` setting
- `LeverPushControls.h`: Tracks pattern changes to detect direction

#### Octave Control
- **Octave Up:** Uses OCTAVE_UP LED (separate from Pink/Blue)
- **Octave Down:** Uses OCTAVE_DOWN LED (separate from Pink/Blue)

### Implementation Rule

When adding new control modes that have directional behavior, ensure LED feedback follows the **Pink=Up / Blue=Down** convention by explicitly setting LED states in the control logic.

---

## Battery Charging Convention

**#1 RULE: Power device ON (running on battery), THEN plug in USB**

### Why This Matters

The XIAO ESP32-S3's built-in charge controller has two modes determined **at boot time**:

1. **USB at boot** → Bypass/power mode → Device powered, battery NOT charging
2. **Battery boot → plug USB** → Charging mode → Device powered AND battery charging

Once in bypass mode, the charge controller cannot switch to charging mode without power cycling.

### User Instructions (MUST be documented)

**Correct charging sequence:**
1. Turn device ON (ensure it's running on battery)
2. Connect USB cable
3. Pink/blue LEDs pulse = charging active
4. Leave for 5+ hours total (partial sessions accumulate)

**If LEDs don't pulse after connecting USB:**
- Device was in bypass mode (USB connected during boot)
- **Fix:** Disconnect USB, wait 5 seconds, reconnect USB
- LEDs should now pulse

### Firmware Implementation

```cpp
// Early in setup(), BEFORE loadBatteryState()
bool usbConnectedAtBoot = isUsbPowered();

// Later in battery monitoring
if (!usbConnectedAtBoot && usbNowConnected) {
    // Valid charging sequence - start/resume calibration timer
    isChargingMode = true;
}
```

**See:** `.github/skills/kb1-hardware/` for complete charging behavior details

---

## MIDI Implementation

### Hardware Interface

**CRITICAL: KB1 uses SERIAL MIDI ONLY (UART)**

```cpp
MIDI_CREATE_INSTANCE(HardwareSerial, Serial0, MIDI)
```

- **Interface:** `Serial0` (Hardware UART on ESP32-S3)
- **Declaration:** `MIDI_NAMESPACE::MidiInterface<MIDI_NAMESPACE::SerialMIDI<HardwareSerial>>`
- **Baud Rate:** 31,250 (standard MIDI)
- **Physical:** 5-pin DIN or 3.5mm TRS MIDI connector
- **NOT USB MIDI:** KB1 does not support USB MIDI class device mode

### MIDI Clock Protocol

**CRITICAL: MIDI Clock requires continuous messages (cannot be "set and forget")**

**Messages:**
- **0xF8 (Clock)** — Must send **24 times per quarter note** at precise intervals
- **0xFA (Start)** — Sent once to begin playback
- **0xFC (Stop)** — Sent once to halt playback
- **0xFB (Continue)** — Resume from stopped position

**Timing Example (120 BPM):**
```
120 beats/min × 24 pulses/beat = 2,880 pulses/min
= 48 clock messages per second
= One 0xF8 message every ~20.8ms
```

**If clock messages stop, receiving device (e.g., Tracker Mini) halts immediately.**

### Tracker Mini MIDI Configuration

**Key Insight: Clock and Transport are SEPARATE settings**

#### Clock Settings
- **Clock In:** Internal / USB / MIDI In jack
- **Clock Out:** Off / USB / MIDI Out jack / USB+MIDI jack
- **Clock Sync Delay:** -50 to +50 (latency compensation, 1/250 pattern step units)

#### Transport Settings
- **Transport In:** Internal / USB / MIDI In jack
- **Transport Out:** Off / USB / MIDI Out jack / USB+MIDI jack

#### Other MIDI Settings
- **Notes In:** Off / USB / MIDI In jack / USB+MIDI jack
- **Notes Input Channel:** All channels or Ch 1-16
- **CC In:** Off / USB / MIDI In jack / USB+MIDI jack
- **CC In Channel:** All channels or Ch 1-16
- **MIDI Out:** Off / USB / MIDI Out jack / USB+MIDI jack
- **Middle C:** C-3, C-4, C-5, C-6 (calibrate note ranges)

### KB1 + Tracker Mini Workflow Options

#### Option 1: Clock Sync Only (Recommended)

**Tracker Settings:**
- Clock In = MIDI In jack (receives KB1's Serial MIDI timing)
- Transport In = Internal (manual play/pause on Tracker)

**KB1 Sends:**
- MIDI Clock (0xF8) continuously when enabled
- No Start/Stop/Continue

**Result:** KB1 provides timing reference, Tracker playback controlled manually. Arpeggiator and Tracker stay in perfect sync.

#### Option 2: Full Remote Control

**Tracker Settings:**
- Clock In = MIDI In jack
- Transport In = MIDI In jack

**KB1 Sends:**
- MIDI Clock (0xF8) continuously
- Start (0xFA) when arpeggiator engages
- Stop (0xFC) when arpeggiator disengages

**Result:** Arpeggiator controls Tracker playback automatically. More integrated but invasive.

### Clock Generation Implementation

```cpp
// At given BPM, calculate microseconds between clock pulses
unsigned long microsBetweenClocks = 2500000 / bpm; // 24 PPQN formula

// Send 0xF8 at precise intervals
if (micros() - lastClockMicros >= microsBetweenClocks) {
    MIDI.sendRealTime(midi::Clock);
    lastClockMicros = micros();
}
```

**Default Recommendation:**
- Clock: ON (always synced)
- Transport: OFF (user controls playback)
- BPM: 40-300 range (shared with arpeggiator)

---

## Chord Settings: Gate vs Swing

**CRITICAL: Gate and Swing are SEPARATE parameters for DIFFERENT play modes**

### Gate (gateValue)
- **Range:** 10-100%
- **Used in:** CHORD mode (playMode = 0 or 1)
- **Purpose:** Controls note duration as percentage of step time
- **Effect:** 
  - 100% = Legato (notes held until next note)
  - 50% = Note on for half the step, silence for half
  - 10% = Staccato (very short notes, mostly silence)
- **Implementation:** Strum cascade in `updateStrum()` schedules note-offs based on gateValue
- **UI Location:** CHORD mode section, visualized with pie chart

### Swing (strumSwing)
- **Range:** 0-50 (firmware), displayed as 50-100% in UI
- **Used in:** ARP mode (playMode = 2)
- **Purpose:** Controls timing variation for odd-indexed notes (shuffle/swing feel)
- **Effect:**
  - 0 (50% UI) = Straight timing (no swing)
  - 25 (75% UI) = Moderate swing
  - 50 (100% UI) = Maximum swing (every other note significantly delayed)
- **Implementation:** Arpeggiator in `updateArpeggiator()` adds swing delay to odd-indexed notes
- **UI Location:** ARP mode section, labeled as "SWING"

### Common Mistake to Avoid

**DO NOT:**
- Use gateValue in arpeggiator code
- Use strumSwing in chord strum code
- Confuse the two when implementing timing logic

**Remember:**
- CHORD mode = gate controls note duration
- ARP mode = swing controls timing variation
- These are orthogonal parameters that never interact

---

## Critical Assumptions

### BLE Protocol Assumptions

#### Assumption: Single 256-Byte Buffer
**What:** All device settings are sent as a single 256-byte buffer over BLE  
**Why:** Firmware expects atomic updates to prevent partial/inconsistent state  
**Violation:** Sending settings in multiple chunks would desync firmware state  
**Validation:** Check buffer size in `encodeSettings()` — must be exactly 256 bytes

#### Assumption: Firmware Validates on Receive, NOT on Encode
**What:** Web app encodes settings, firmware validates and may reject  
**Why:** Firmware is source of truth for what's valid (hardware constraints)  
**Violation:** Web app must not assume encoded settings will be accepted  
**Validation:** Always check device response after BLE write, handle rejections

#### Assumption: Invalid Settings Reject ENTIRE Update
**What:** If ANY field is invalid, firmware ignores the whole settings buffer  
**Why:** Prevents partial updates that would leave device in inconsistent state  
**Violation:** Assuming individual fields can fail independently  
**Validation:** Use `validateSettingsDetailed()` before sending to get clear errors

### Strum Speed Assumptions

#### Assumption: Signed 16-bit Value (-360 to +360)
**What:** Strum speed is ALWAYS stored as signed int, negative = reverse  
**Why:** Firmware uses sign bit to determine strum direction  
**Violation:** Storing as unsigned or separate direction field breaks firmware contract  
**Validation:** Type is `number` in TS, but range check in validation

#### Assumption: Steps of 5ms Only
**What:** Strum speed must be multiple of 5 (e.g., 5, 10, 15, not 7 or 13)  
**Why:** Firmware timer resolution is 5ms, other values round unpredictably  
**Violation:** Sending non-multiples causes inconsistent timing  
**Validation:** `speed % 5 === 0` in `firmware-contract.ts`

#### Assumption: Forbidden Range -4 to +4
**What:** Values in range -4 to +4 are NOT allowed (firmware rejects them)  
**Why:** Too fast to be physically usable, firmware enforces minimum 5ms  
**Violation:** Sending values in this range causes BLE update to fail  
**Validation:** Check `abs(speed) >= 5` in validation

#### Assumption: CC 200 is BIPOLAR, All Others are UNIPOLAR
**What:** Only CC 200 uses bipolar mapping (0-63=negative, 65-127=positive)  
**Why:** Allows single lever to control forward AND reverse smoothly  
**Violation:** Treating CC 200 like other CCs breaks lever sync  
**Validation:** Use `isBipolarCC()` from `firmware-contract.ts`

### Root Note Assumptions

#### Assumption: Chromatic Mode Ignores Root Note
**What:** When `scaleType=0` (Chromatic), firmware ignores the `rootNote` value  
**Why:** Chromatic scale includes all 12 notes regardless of root  
**Violation:** Assuming rootNote matters in Chromatic causes confusion  
**Validation:** UI can allow `rootNote=0` for Chromatic, displays as C for clarity

#### Assumption: Non-Chromatic Requires 60-71 Range
**What:** For all scales except Chromatic, `rootNote` must be 60-71 (C to B)  
**Why:** Firmware uses rootNote as base for interval calculation  
**Violation:** Values outside this range cause firmware to reject settings  
**Validation:** Check `isValidRootNote(note, isChromatic)` in `firmware-contract.ts`

#### Assumption: UI Defaults to C (60) for Invalid Values
**What:** If loaded rootNote is outside 60-71, UI displays/uses 60 (C)  
**Why:** Prevents broken UI when legacy presets have invalid values  
**Violation:** Displaying invalid value confuses users, may break picker controls  
**Validation:** `rootNoteValue` computed in `KeyboardSettings.vue`

### Voicing Range Assumption

#### Assumption: 1 to 3 Only (Inclusive)
**What:** Voicing must be exactly 1, 2, or 3 (number of octaves to stack)  
**Why:** Firmware has fixed array size for chord note stacking  
**Violation:** 0 or 4+ causes buffer overflow or silent failure  
**Validation:** Use `isValidVoicing()` from `firmware-contract.ts`

### Performance Assumptions

#### Assumption: Drag Handlers Only Emit on Value Change
**What:** `updateValueFromPosition()` checks if value changed before emitting  
**Why:** Prevents 100+ redundant model updates during single drag gesture  
**Violation:** Assuming updates happen on every pixel breaks performance  
**Validation:** Always check `if (newValue !== currentValue)` before emit

#### Assumption: Validation Happens BEFORE Send, NOT During Drag
**What:** Expensive validation (`validateSettingsDetailed`) only runs on BLE send  
**Why:** Keeps drag interactions smooth (60fps), validation when it matters  
**Violation:** Calling validation in drag handlers kills performance  
**Validation:** NO validation calls in `updateValueFromPosition()`

---

## Breaking Changes Log

Track all breaking changes to prevent accidental regressions.

### v1.7 (April 2026)

#### Scale Validation - rootNote=0 Now Valid for Chromatic
**What Changed:**
- BLE protocol validation now allows `rootNote: 0` when `scaleType: 0` (Chromatic mode)
- Previously rejected rootNote < 60, now skips validation for Chromatic

**Why:**
- Firmware ignores rootNote in Chromatic mode (all 12 notes active regardless)
- Old validation was overly strict, causing false rejections

**Impact:**
- **Firmware:** Old firmware (v1.6 and earlier) may reject settings with rootNote=0
- **Web App:** Old web app (v1.6 and earlier) won't send rootNote=0
- **Presets:** Existing presets likely have rootNote=60, no migration needed

**Migration:**
- Update both firmware AND web app together for v1.7
- If rootNote=0 causes issues, set to 60 (C) — firmware ignores it anyway

**Code Locations:**
- `KB1-config/src/ble/kb1Protocol.ts` — `validateScale()`
- `KB1-config/src/components/KeyboardSettings.vue` — `rootNoteValue` computed

#### Strum Speed - Bipolar CC 200 Mapping
**What Changed:**
- CC 200 now uses BIPOLAR mapping: MIDI 0-63 = reverse, 65-127 = forward
- Previously used unipolar mapping (exact behavior varied by firmware version)
- Lever controls now sync correctly with negative strum speeds

**Why:**
- Allows single physical lever to control both forward AND reverse strum smoothly
- Eliminates need to toggle direction separately when using lever
- Matches user expectation: full left = full reverse, full right = full forward

**Impact:**
- **Firmware:** Lever behavior completely changed — MUST update firmware
- **Web App:** Lever assignments to CC 200 will behave differently
- **Presets:** Stored strum speeds are unchanged (still -360 to +360)

**Migration:**
- CRITICAL: Update firmware before using lever for strum speed
- Old firmware with new web app: Lever will send wrong values
- Re-test lever assignments after firmware update

**Code Locations:**
- `firmware/src/controls/LeverControls.h` — Constructor and `syncValue()`
- `firmware/src/controls/LeverPushControls.h` — Send conversion

#### UI Model - Strum Speed Now Unipolar Display
**What Changed:**
- UI now displays strum speed as positive value (5-360) with separate FWD/REV toggle
- Previously displayed bipolar value (-360 to +360)
- Model still stores signed value for firmware compatibility

**Why:**
- Cleaner UX: speed and direction are independent concepts
- Matches user mental model: "how fast" vs "which direction"
- Eliminates confusing negative numbers

**Impact:**
- **Breaking:** Custom code reading `chord.strumSpeed` directly may need updates
- **Non-Breaking:** BLE protocol unchanged, presets unchanged
- **UI Only:** Pure display change, no data model changes

**Code Locations:**
- `KB1-config/src/components/KeyboardSettings.vue` — `smartSliderValue` computed

#### Performance - Drag Update Optimization
**What Changed:**
- Drag handlers now only emit updates when value actually changes
- Previously emitted on every pixel movement (~100 updates per drag)
- Now emits only on value changes (~7 updates per drag for strum speed)

**Why:**
- Eliminates unnecessary re-renders and model cloning during drag
- Dramatically improves drag responsiveness
- Reduces CPU/battery usage on mobile devices

**Impact:**
- **Non-Breaking:** Pure performance optimization
- **Behavior:** Drag feels more responsive, no functional change
- **Warning:** Do NOT add code that expects updates on every pixel

**Code Locations:**
- `KB1-config/src/components/KeyboardSettings.vue` — `updateValueFromPosition()`

### v1.6 (Previous Release)

#### Battery Persistence
**What Changed:**
- Battery % now persists correctly after reboot
- Fixed: Manual battery set now calculates equivalent consumed time

**Impact:**
- Requires firmware update to take effect
- Old firmware: Battery resets to 100% after reboot

---

## Critical Checklist

**⚠️ READ BEFORE ANY ARCHITECTURE CHANGES ⚠️**

### Before Modifying Task Core Assignments, I2C, BLE, or Touch Sensor Code:

#### MANDATORY: Check These First
1. **`/memories/repo/esp32-architecture.md`** (now `.github/skills/kb1-hardware/`) — Core constraints, I2C limitations
2. **`/memories/repo/led-conventions.md`** (now here) — LED color meanings (Pink=Up, Blue=Down)
3. **`/memories/repo/serial-output-format.md`** (now `.github/skills/kb1-optimization/`) — Compact logging formats
4. **`/memories/repo/touch-sensor-optimizations.md`** (now `.github/skills/kb1-optimization/`) — Touch sensor behavior

### Hard Constraints (DO NOT VIOLATE)

**❌ NEVER Move These Off Core 1:**
- **BLE Stack** → ESP-IDF hardware limitation, causes disconnects
- **Touch Sensor** → Hardware peripheral affinity, returns garbage on Core 0
- **ALL I2C Tasks** → `readInputs` + `ledTask` MUST be same core
  - MCP23X17 GPIO expanders (buttons, levers, LEDs)
  - Cross-core I2C causes: `Unfinished Repeated Start transaction!` crashes

**❌ NEVER Split I2C Devices Across Cores:**
- `mcp_U1` and `mcp_U2` both require Core 1
- All keyboard, lever, octave button, and LED updates use I2C
- ESP32 I2C driver mutex cannot handle cross-core coordination

### Safe Optimizations (Always Allowed)

**✅ Serial Output Changes:**
- Compact format (already optimized ~80% reduction)
- Auto-detection (USB CDC connection detection)
- Throttling/rate limiting

**✅ I2C Speed:**
- Current: 400kHz (safe, tested)
- Maximum: 1.7MHz (MCP23X17 spec limit)
- Heat: Negligible at any supported speed

**✅ Task Priorities:**
- Adjust priority within same core (readInputs can be priority 2, ledTask priority 1)
- Does NOT move tasks between cores

**✅ Logic Changes:**
- LED patterns, control algorithms, MIDI mapping
- Anything that doesn't touch core assignment or hardware peripherals

### Battery/Charging Hardware Constraints

**⚡ CRITICAL: Charge Controller Boot Sequence Requirement**

**Hardware behavior:**
- **USB at boot** (boot with USB already connected) → **Bypass/power mode** → Device powered but **NOT charging battery**
- **Boot on battery → THEN plug USB** → **Charging mode** → Device powered AND **charging battery**

**Firmware tracking:**
- Detect boot sequence: `usbConnectedAtBoot = isUsbPowered()` captured EARLY in setup(), BEFORE `loadBatteryState()`
- Valid sequence (boot on battery → plug USB): `isChargingMode = true` → Run calibration timer, track charge
- Invalid sequence (USB at boot): `isChargingMode = false` → Stay uncalibrated (254), show ? in GUI
- Partial charges DO NOT accumulate (all-or-nothing: 5hrs continuous required)

**⚠️ BOOT SEQUENCE BUG PATTERN (Fixed April 2026 - DO NOT REINTRODUCE)**

**The trap:** `setup()` has a fresh-boot block that runs AFTER `loadBatteryState()` to handle sleep/wake:
```cpp
if (resetReason != ESP_RST_DEEPSLEEP) {
    usbConnectedAtBoot = false;       // ← WRONG: throws away early hardware detection
    batteryState.lastUsbState = false; // ← WRONG: causes fake "USB just plugged" event
}
```

**Why it causes charging LEDs on bypass boot:**
1. `usbConnectedAtBoot = isUsbPowered()` correctly detects USB at line ~956
2. `loadBatteryState()` overwrites it with stale NVS at line ~997
3. Fresh-boot block then sets it to `false` → `usbConnectedAtBoot` is now wrong
4. `lastUsbState = false` but USB IS connected → `usbJustPlugged = true`
5. `usbConnectedAtBoot == false` → takes charging path → LEDs pulse

**The fix (MUST keep):** Capture early detection BEFORE loadBatteryState, restore in fresh-boot block:
```cpp
bool usbAtBootEarlyDetection = isUsbPowered();  // Before loadBatteryState()
// ... after loadBatteryState() ...
if (resetReason != ESP_RST_DEEPSLEEP) {
    usbConnectedAtBoot = usbAtBootEarlyDetection;      // Restore hardware detection
    batteryState.lastUsbState = usbAtBootEarlyDetection; // Match actual state (no fake event)
}
```

### When Proposing Performance Improvements:

1. **Check memory files FIRST** before suggesting
2. **Verify against esp32-architecture.md** constraints
3. **State assumptions explicitly** (e.g., "Assuming I2C can be split..." → WRONG)
4. **If uncertain, ask user** rather than implementing

---

## Firmware Release Process (v1.6.2+)

### ⚠️ NEVER copy `.pio/build/firmware.bin` directly as a release binary

`.pio/build/seeed_xiao_esp32s3/firmware.bin` is the **app partition only** (must be flashed at offset `0x10000`).

Flashing it at offset `0x0` causes immediate boot loop: `Checksum failure. Calculated 0x57 stored 0xf3`

### ✅ Always use `build_complete.sh` to produce the release binary

```bash
cd firmware
bash build_complete.sh
```

This runs `esptool.py merge_bin` to combine:
- `bootloader.bin` @ `0x0`
- `partitions.bin` @ `0x8000`
- `firmware.bin`   @ `0x10000`

**Output:** `kb1-studio/dist/firmware/KB1-firmware-vX.Y.Z.bin` — merged, flashes at offset `0x0` (stored directly in `kb1-studio/dist/firmware`, no redundant binary files stored in `firmware/`).

### Release Checklist (All Three Repos)

1. Bump `FIRMWARE_VERSION` in `src/objects/Constants.h`
2. Update `FIRMWARE_VERSION` in `build_complete.sh`
3. Run `bash build_complete.sh` → outputs `KB1-firmware-vX.Y.Z.bin` directly in `kb1-studio/dist/firmware/`
4. Add entry to `kb1-studio/public/firmware/releases.json` (or `dist/firmware/releases.json`) (use `wc -c` for exact byte size)
5. Bump `APP_VERSION` in `KB1-config/src/constants.ts`
6. Commit + push all three repos; tag firmware repo with `vX.Y.Z`

---

## KB1-Config Web App Architecture Notes (post-v1.6.2)

### Connect Sequence — Order is Critical

All sequential in `useDeviceState.connect()`:
1. BLE connect + characteristic discovery (each char individually — DELETE failure doesn't block SAVE/LOAD/LIST)
2. `refreshDevicePresets()` — preset list read
3. `handleLoad()` — reads all 8 settings characteristics → triggers `lastDeviceLoadTime` → MobileScales resets `hasChanges = false`
4. `useBatteryStatus().initBatteryStatus()` — battery read LAST (BLE stack free)

### Battery Icon (`isAvailable` flag)
- Starts `false`, must be set `true` for icon to render
- Set by: `initBatteryStatus()` or `updateBatteryFromKeepAlive()` (whichever fires first)
- `MobileHeader` no longer owns battery init — `useDeviceState.connect()` owns it

### Upload Button Dirty State
- `lastDeviceLoadTime` ref in `useDeviceState` — updated after every successful `handleLoad()`
- `MobileScales` watches it → resets `localSettings` + `hasChanges = false`
- Prevents upload button activating on connect auto-load

### Keep-Alive State Sync (active — firmware v1.6.2+)
- `onKeepAliveState` callback in `bleClient` updates `deviceSettings.chord.strumPattern`, `scale.scaleType`, `scale.rootNote` every 60s
- Firmware v1.6.2 binary (rebuilt Apr 11) populates bytes 2-5 from live `_chordSettings` and `_scaleSettings` refs

---

## Guidelines for Future Changes

### When is Something "Breaking"?
1. **Breaking:** Changes BLE protocol format or validation
2. **Breaking:** Changes firmware behavior that affects saved presets
3. **Breaking:** Changes data model in ways that old code can't handle
4. **Non-Breaking:** Pure UI changes with no data model impact
5. **Non-Breaking:** Performance optimizations that don't change behavior

### How to Minimize Breaking Changes
1. Add new fields as optional, keep old fields working
2. Version the BLE protocol and check version on connect
3. Use feature flags to test new behavior alongside old
4. Document ANY change to validation rules
5. Test with old presets before releasing

### When Breaking Changes are Necessary
1. Fixing critical bugs (like scale validation being too strict)
2. Adding features that fundamentally change how hardware works
3. Performance improvements that require behavioral changes
4. Aligning with user expectations (like bipolar lever mapping)

**Always document WHY the break was necessary!**

---

## Revision History

- **April 22, 2026:** Migrated from `/memories/repo/` to `.github/skills/kb1-conventions/`
- **April 11, 2026:** v1.6.2 release — Battery set%, keep-alive notifications, 88% eval mode stuck bug fixes
- **March-April 2026:** v1.7 development — Scale validation, strum speed bipolar mapping, drag optimization

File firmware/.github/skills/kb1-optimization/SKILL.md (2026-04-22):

---
name: kb1-optimization
description: Performance optimization strategies for KB1 firmware. Use when optimizing code, improving responsiveness, reducing latency, debugging performance issues, or planning efficiency improvements. Contains I2C bulk read strategy (12× speedup), serial output optimization (80% reduction), touch sensor debouncing, and performance profiling data. Includes implementation plans and measured results.
---

# KB1 Performance Optimization

Proven strategies and implementation plans for optimizing KB1 firmware performance.

---

## I2C Bus Optimization Strategy

**Current Status:** Analysis complete, implementation ready, **NOT yet deployed**  
**Expected Benefit:** 12× speedup in input scanning (5-6ms → 0.4ms per cycle)  
**Files:** `I2C_EFFICIENCY_ANALYSIS.md`, `I2C_BULK_READ_IMPLEMENTATION_PLAN.md`

### Critical Finding: Bulk Read Opportunity

**Current Implementation (Inefficient):**
- **25+ individual I2C transactions per scan cycle**
  - 19 keyboard keys (`KeyboardControl.h:397`)
  - 6 lever/push inputs (`main.cpp:1380-1385`)
- **I2C bus time:** ~5-6ms per scan (50-60% utilization)
- **Power overhead:** ~10-15mA from I2C activity
- **Each transaction:** Mutex lock → START → address → register → data → STOP → unlock

**Optimal Implementation (Not Yet Applied):**
- **2 bulk reads:** Use `mcp.readGPIOAB()` to read all 16 pins at once
- **Only 2 I2C transactions total:** One per MCP23017 chip
- **I2C bus time:** ~0.4ms per scan (**92% reduction**)
- **Power savings:** ~8-12mA reduction
- **Method:** Single I2C transaction reads both GPIO ports (GPIOA + GPIOB = 16 bits)

### Implementation Pattern

```cpp
// Centralized bulk read function
struct MCPInputCache {
    uint16_t u1_pins;  // All 16 pins from MCP @ 0x20
    uint16_t u2_pins;  // All 16 pins from MCP @ 0x21
};

MCPInputCache readAllInputs() {
    MCPInputCache cache;
    if (xSemaphoreTake(i2cMutex, portMAX_DELAY) == pdTRUE) {
        cache.u1_pins = mcp_U1.readGPIOAB();  // 1 I2C transaction
        cache.u2_pins = mcp_U2.readGPIOAB();  // 1 I2C transaction
        xSemaphoreGive(i2cMutex);
    }
    return cache;
}

// Extract individual pin states with bitwise operations (no I2C overhead)
bool lever1Left = !(cache.u1_pins & (1 << SWD1_LEFT_PIN));
bool lever1Right = !(cache.u1_pins & (1 << SWD1_RIGHT_PIN));
// ... etc for all 32 pins
```

**Key Insight:** Bitwise operations on cached data are ~1000× faster than I2C reads.

### Expected Benefits

**Performance:**
- Input latency: **-5ms I2C overhead** (more responsive controls)
- CPU efficiency: Less mutex blocking, smoother LED animations
- LED update contention: Reduced (less I2C bus congestion)

**Power:**
- Active current: **-8-12mA reduction**
- Battery life: **+30-45min active runtime** (~5-10% improvement)
- Heat: Negligible improvement (I2C was never a heat source)

**Code Quality:**
- Centralized I/O reading (single source of truth)
- Less mutex contention between tasks
- Easier to add new inputs (just add bitwise mask)

### I2C Clock Speed: Keep at 400kHz

**Current Setting:** 400kHz (Fast Mode I2C) — **DO NOT CHANGE**

**Why not increase to 1.7MHz?**
1. **Bulk reads give 12× improvement** vs only 2.5× from clock speed increase
2. **ESP32-S3 I2C reliability issues above 400kHz** (known driver limitations)
3. **Current 0.4ms bus time (with bulk reads) is negligible** — not worth risk
4. **400kHz is optimal for:** Signal integrity, battery life, reliability

**History:**  
- v1.0-v1.2: 100kHz (slow, conservative)
- v1.3.0: Upgraded to 400kHz (4× improvement, correct move)
- Future: Keep at 400kHz, implement bulk reads instead

### Implementation Priority

| Priority | Optimization | Speedup | Risk |
|---|---|---|---|
| **HIGH** | Bulk I2C reads | 12× | Low |
| **MEDIUM** | LED bulk writes | 3-5× | Low |
| **LOW/SKIP** | Clock speed increase | 2.5× | Medium-High |

### Implementation Status

**Ready to implement:** See `I2C_BULK_READ_IMPLEMENTATION_PLAN.md` for step-by-step guide (~2.5 hours)

**Conservative approach:**
1. Implement bulk I2C reads (12× speedup, low risk)
2. Test thoroughly before considering other changes
3. Monitor power consumption to validate savings

**Aggressive approach (optional):**
- Reduce scan rate: 2ms → 5ms (less frequent polling, still responsive)
- Reduce touch debounce: 200ms → 50ms in Toggle mode only
- LED bulk writes (parallel to I2C optimization)

---

## Serial Output Optimization

**Status:** Deployed in v1.2.6+  
**Impact:** 80% reduction in serial overhead, 6-8× faster during rapid playing  
**Philosophy:** Serial printing is **blocking I/O** (~5-10ms per call) — minimize aggressively

### Compact Serial Format

All debug output uses **ultra-compact single-character prefixes** to minimize CPU overhead.

#### Notes (KeyboardControl.h)
```cpp
// Before (v1.0-v1.2): 3 lines per note
Note On: 65 (velocity 85)
Key: F4
Note Off: 65

// After (v1.2.6+): 1 compact line
N65v85    // Note 65 on, velocity 85
N65-      // Note 65 off
C60-      // Chord note 60 off
```

#### Levers (LeverControls.h)
```cpp
// Before: "INCREMENTAL: 85 -> 91 (stepSize: 6)"
// After:
L91>      // Lever incremented to 91
L73<      // Lever decremented to 73
V91       // Velocity set to 91
C3=127    // CC 3, value 127
```

#### Lever Push (LeverPushControls.h)
```cpp
C24=58    // CC 24, value 58
P3=76     // Pattern 3 selected (MIDI value 76)
```

#### Touch Sensor (TouchControl.h)
```cpp
Touch CC1=72    // Continuous mode (throttled to 500ms max)
KB1 Expression: Shape set to 3    // Pattern Selector (150ms rate limit)
```

#### Arpeggiator / Pattern System (KeyboardControl.h)
```cpp
Arp:R60P3       // Arpeggiator started: Root=60, Pattern=3
ArpRoot:60@2    // Root changed to 60, continuing at index 2
S0:N60v127      // Strum note index 0: Note 60, Velocity 127
Arp0:N72v85     // Arp note index 0: Note 72, Velocity 85
Arp-72          // Arp note 72 off
Arp:Loop        // Arpeggiator loop restarted
Arp:Stop76      // Arpeggiator stopped, note 76 off
```

#### Octave Control (OctaveControl.h)
```cpp
O-1       // Octave down by 1
O+1       // Octave up by 1
```

#### BLE Connection (ServerCallbacks.cpp, BLEGestureControl.h)
```cpp
BLE+          // Client connected
BLE-          // Client disconnected
BLE:Cross     // Cross-lever gesture detected
BLE:On        // Gesture activation threshold reached
BLE:Abort     // Gesture released before activation
BLE:Ready     // Bluetooth ready, advertising
```

#### Battery Monitoring (v1.4.0+)
```cpp
Chg: 476/19800s           // Charging progress (current/total seconds)
Saved                     // Battery state saved to NVS
CHARGE_60S | USB:1 | Chg:1 | Slp:1   // Event markers (every 60s)
```

### Performance Impact

**Measured Results:**
- **Before optimization:** ~70-80% serial overhead during rapid playing
- **After optimization:** ~10-15% serial overhead
- **Speed improvement:** 6-8× faster
- **Side effect:** No more garbled output during fast keyboard/lever movements

**Why it matters:**
- Serial printing **blocks the CPU** for 5-10ms per call
- High-frequency loops (keyboard polling, touch sensing) call serial output frequently
- Queue backup during rapid input → lag → unresponsive controls

### Optimization Strategies Applied

**1. Rate Limiting:**
```cpp
static unsigned long lastPatternChange = 0;
unsigned long now = millis();
if (now - lastPatternChange < 150) {
    return;  // Skip serial output if too soon
}
lastPatternChange = now;
```

**Use for:** Pattern Selector (150ms), Touch continuous mode (500ms), CC interpolation (300ms)

**2. Condensing Multiple Prints:**
```cpp
// Before: 6 serial calls (30-60ms blocked)
SERIAL_PRINT("KB1 Expression: Pattern Selector set to pattern ");
SERIAL_PRINTLN(patternIndex);
SERIAL_PRINT("  Strum Pattern: ");
SERIAL_PRINTLN(_chordSettings.strumPattern);
SERIAL_PRINT("  MIDI CC ");
SERIAL_PRINT(_ccNumber);

// After: 1 serial call (5-10ms blocked)
char buf[32];
snprintf(buf, sizeof(buf), "KB1 Expression: Shape set to %d", patternIndex);
SERIAL_PRINTLN(buf);
```

**3. Throttling CC Changes:**
```cpp
// Only print CC changes every 300ms (reduces interpolation spam)
static unsigned long lastCCPrint = 0;
if (millis() - lastCCPrint >= 300) {
    SERIAL_PRINT("C"); SERIAL_PRINT(ccNum);
    SERIAL_PRINT("="); SERIAL_PRINTLN(value);
    lastCCPrint = millis();
}
```

**4. Auto-Detection:**
```cpp
// Only output when USB terminal is connected (CDC detection)
// End users see zero overhead when serial not in use
if ((bool)Serial) {
    SERIAL_PRINTLN("...");
}
```

### Production Release Philosophy (v1.4.0+)

**CRITICAL RULE:** All serial output in production must be compact and efficient.

**Design Principles:**
1. **Efficiency First:** Every serial print blocks 5-10ms — minimize aggressively
2. **Essential Info Only:** Print only what's needed to verify operation
3. **Compact Format:** Use shortest possible representation
4. **No Redundancy:** Don't repeat information already shown

**Example — Battery Monitoring:**

Before (verbose):
```
Charging: 476s / 19800s (19323s remaining)
Battery state saved: Uncalibrated
```

After (compact):
```
Chg: 476/19800s
Saved
```

**Impact:** ~40ms saved per update (every 30s) = negligible overhead  
**Benefit:** Cleaner logs, faster serial throughput, consistent with format philosophy

### Debug Tips

When troubleshooting, grep for these patterns:
```bash
grep "^N[0-9]" serial.log    # Notes
grep "^L[0-9]" serial.log    # Levers
grep "^C[0-9]" serial.log    # CC messages
grep "Touch" serial.log      # Touch sensor
grep "Arp:" serial.log       # Arpeggiator
grep "BLE" serial.log        # BLE events
```

---

## Touch Sensor Optimization

**Status:** Deployed in v1.2.6+  
**Impact:** Fixed Pattern Selector lag issue ("stalls after 2-3 taps")

### Pattern Selector Lag Fix

**Original Problem:**
- After 2-3 rapid taps, Pattern Selector becomes unresponsive
- User must wait several hundred milliseconds before next tap registers

**Root Cause:**
Serial printing was blocking I/O. Each Pattern Selector tap triggered **6× `SERIAL_PRINT()` calls**:

```cpp
SERIAL_PRINT("KB1 Expression: Pattern Selector set to pattern ");
SERIAL_PRINTLN(patternIndex);
SERIAL_PRINT("  Strum Pattern: ");
SERIAL_PRINTLN(_chordSettings.strumPattern);
SERIAL_PRINT("  MIDI CC ");
SERIAL_PRINT(_ccNumber);
SERIAL_PRINT(": ");
SERIAL_PRINTLN(PATTERN_VALUES[patternIndex]);
```

**Each serial call blocks for ~5-10ms** = **30-60ms total delay per tap**

After 2-3 rapid taps, serial queue backs up → perceivable lag → feels "stuck"

### Solution Applied

**File:** `src/controls/TouchControl.h` (~line 160)

**1. Reduced serial output from 6 lines to 1:**
```cpp
SERIAL_PRINT("KB1 Expression: Shape set to ");
SERIAL_PRINTLN(patternIndex);
```

**2. Added rate limiting (150ms minimum between changes):**
```cpp
static unsigned long lastPatternChange = 0;
unsigned long now = millis();
if (now - lastPatternChange < 150) {
    _wasPressed = isPressed;  // Update state to prevent re-trigger
    break;
}
lastPatternChange = now;
```

**Result:**
- ✅ No more lag after rapid taps
- ✅ Smooth, responsive Pattern Selector cycling
- ✅ 150ms feels natural (prevents accidental double-taps while allowing intentional rapid changes)

### Touch Sensor Core Affinity

**CRITICAL:** Touch sensor MUST run on Core 1

**Why:**
- Uses ESP32 capacitive touch peripheral (hardware tied to Core 1)
- When `touchRead()` called from Core 0 → returns garbage (3755997 instead of 24000-64000)

**Symptom of wrong core:**
- Flashing LEDs continuously
- No MIDI output from touch sensor
- Serial shows maxed touch values (out of range)

**Solution:** Keep all inputs including touch on Core 1 (already correct in current architecture)

### Continuous Mode Throttling

Touch in continuous mode (CC sweep) sends MIDI constantly → serial spam

**Optimization** (`src/controls/TouchControl.h` ~line 218):

```cpp
// Throttled serial output for continuous mode (print every 500ms max)
static unsigned long lastContinuousPrint = 0;
unsigned long now = millis();
if (now - lastContinuousPrint >= 500) {
    SERIAL_PRINT("Touch CC"); SERIAL_PRINT(_ccNumber);
    SERIAL_PRINT("="); SERIAL_PRINTLN(sendVal);
    lastContinuousPrint = now;
}
```

**Result:** Serial output reduced from 30+ lines/sec to ~2 lines/sec  
(Still see activity without flooding logs)

---

## Key Takeaways

### Performance Optimization Hierarchy

1. **Architecture changes** (e.g., bulk I2C reads): 10-100× improvements possible
2. **Algorithm changes** (e.g., rate limiting, debouncing): 2-10× improvements
3. **Micro-optimizations** (e.g., clock speed tuning): <2× improvements, higher risk

### Serial Printing is NOT FREE

**Cost:** 5-10ms blocking I/O per call  
**Impact:** One of the most expensive operations in embedded systems

**Always:**
1. Minimize print calls in high-frequency loops
2. Use throttling for continuous/rapid events
3. Condense multi-line messages to single compact lines
4. Consider disabling non-critical debug output in production builds

### Touch Sensor Behavior

- Hardware peripheral with Core 1 affinity
- Requires debouncing and rate limiting for responsive UX
- Serial output can cause perceivable lag if not throttled

### I2C Bus Strategy

- Bulk reads >> clock speed increases (12× vs 2.5× improvement)
- ESP32-S3 I2C driver has known reliability issues above 400kHz
- Power savings from bulk reads: ~8-12mA (significant for battery life)

---

## Implementation Plans

**Ready to Deploy:**
- `firmware/I2C_BULK_READ_IMPLEMENTATION_PLAN.md` — Step-by-step guide (~2.5hr)
- `firmware/I2C_EFFICIENCY_ANALYSIS.md` — Technical deep-dive
- `firmware/ADDITIONAL_PERFORMANCE_OPPORTUNITIES.md` — Other optimizations

**Already Deployed:**
- Serial output optimization (v1.2.6+)
- Touch sensor rate limiting (v1.2.6+)
- Pattern Selector lag fix (v1.2.6+)

**Conservative Next Step:**
1. Implement bulk I2C reads (Phase 1-4 from implementation plan)
2. Test after each phase
3. Validate power savings and latency improvements
4. Monitor for regressions

**Aggressive Next Step (if conservative succeeds):**
- Reduce scan rate to 5ms (from 2ms)
- Reduce touch debounce to 50ms in Toggle mode
- LED bulk writes (parallel optimization)

---

## Revision History

- **April 22, 2026:** Migrated from `/memories/repo/` to `.github/skills/kb1-optimization/`
- **April 12, 2026:** I2C bulk read analysis complete, implementation plan ready
- **March 15, 2026:** Touch sensor optimization (v1.2.6) — Pattern Selector lag fix
- **February 28, 2026:** Serial output optimization (v1.2.6) — 80% reduction in overhead

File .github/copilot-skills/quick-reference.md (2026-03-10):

---
description: Quick reference for common KB1 development tasks and workflows
---

# KB1 Quick Reference & Common Tasks

Fast lookup guide for frequent KB1 development operations.

## Quick Commands

### Firmware (PlatformIO)

```bash
# Build complete image for distribution
./build_complete.sh

# Development build (fast iteration)
pio run -e seeed_xiao_esp32s3

# Upload to device
pio run -t upload -e seeed_xiao_esp32s3

# Serial monitor
pio device monitor

# Clean build
pio run -t clean -e seeed_xiao_esp32s3

# Full clean (re-download dependencies)
pio run -t fullclean -e seeed_xiao_esp32s3

# Check binary size
pio run -t size -e seeed_xiao_esp32s3
```

### Web App (npm)

```bash
# Development server
npm run dev

# Build for production
npm run build

# Preview production build
npm run preview

# Lint code
npm run lint

# Type check
npm run type-check

# Install dependencies
npm install
```

## Common File Locations

### Firmware

```
firmware/src/objects/Constants.h    # Version, UUIDs, config macros
firmware/src/main.cpp               # Main loop, init, sleep logic
firmware/src/bt/BluetoothController.cpp  # BLE stack
firmware/build_complete.sh          # Release build script
firmware/platformio.ini             # Build configuration
firmware/RELEASE_NOTES_v*.md        # Version history
```

### Web App

```
KB1-config/src/ble/kb1Protocol.ts          # BLE protocol logic
KB1-config/src/ble/bleClient.ts            # BLE connection
KB1-config/src/styles/themes/kb1.css       # Theme variables
KB1-config/src/assets/ui/                  # Visual assets
KB1-config/src/composables/useDeviceState.ts  # Global state
KB1-config/package.json                    # App version
```

### Documentation

```
CONTRIBUTING.md                           # Project conventions
firmware/BUILD_INSTRUCTIONS.md            # Build guide
KB1-config/DESIGNER_WORKFLOW.md          # Theme workflow
KB1-config/DEVICE_PRESET_IMPLEMENTATION.md  # Preset system
KB1-config/FIRMWARE_PRESET_UUIDS.md      # BLE UUIDs
```

## Version Bump Workflow

**Scenario:** Bumping from v1.2.5 → v1.2.6

1. Update firmware version:
```cpp
// firmware/src/objects/Constants.h
#define FIRMWARE_VERSION_MAJOR 1
#define FIRMWARE_VERSION_MINOR 2
#define FIRMWARE_VERSION_PATCH 6
```

2. Update build script:
```bash
# firmware/build_complete.sh (line ~10)
FIRMWARE_VERSION="v1.2.6"
```

3. Update README:
```markdown
# firmware/README.md (line ~5)
**Latest Release:** v1.2.6
```

4. Update web app:
```json
// KB1-config/package.json
{ "version": "1.2.6" }
```

5. Create release notes:
```bash
touch firmware/RELEASE_NOTES_v1.2.6.md
```

6. Build and test:
```bash
cd firmware && ./build_complete.sh
# Flash to device and verify!
```

## Adding a New BLE Characteristic

**Scenario:** Adding a new setting that needs BLE communication

### 1. Define UUID (Firmware)

```cpp
// firmware/src/objects/Constants.h
#define NEW_SETTING_UUID "d3a7b321-0001-4000-8000-000000000099"
```

### 2. Add Characteristic (Firmware)

```cpp
// firmware/src/bt/BluetoothController.cpp
pCharacteristic = pService->createCharacteristic(
  NEW_SETTING_UUID,
  BLECharacteristic::PROPERTY_READ | BLECharacteristic::PROPERTY_WRITE
);
pCharacteristic->setCallbacks(new CharacteristicCallbacks());
```

### 3. Handle Read/Write (Firmware)

```cpp
// firmware/src/bt/CharacteristicCallbacks.cpp
void onWrite(BLECharacteristic* pCharacteristic) {
  if (strcmp(pCharacteristic->getUUID().toString().c_str(), NEW_SETTING_UUID) == 0) {
    std::string value = pCharacteristic->getValue();
    uint8_t newValue = static_cast<uint8_t>(value[0]);
    // Update setting...
    globalSettings.newSetting = newValue;
  }
}
```

### 4. Add to Protocol (Web App)

```typescript
// KB1-config/src/ble/kb1Protocol.ts
export const NEW_SETTING_UUID = 'd3a7b321-0001-4000-8000-000000000099';

export interface DeviceSettings {
  // ... existing settings
  newSetting: number;
}

export const DEFAULT_SETTINGS: DeviceSettings = {
  // ... existing defaults
  newSetting: 50,  // default value
};

export function validateNewSetting(value: number): boolean {
  return value >= 0 && value <= 100;
}
```

### 5. Add to BLE Client (Web App)

```typescript
// KB1-config/src/ble/bleClient.ts
private newSettingCharacteristic: BluetoothRemoteGATTCharacteristic | null = null;

// In connect():
this.newSettingCharacteristic = await service.getCharacteristic(NEW_SETTING_UUID);

// Read method:
async readNewSetting(): Promise<number> {
  if (!this.newSettingCharacteristic) throw new Error('Not connected');
  const dataView = await this.newSettingCharacteristic.readValue();
  return dataView.getUint8(0);
}

// Write method:
async writeNewSetting(value: number): Promise<void> {
  if (!this.newSettingCharacteristic) throw new Error('Not connected');
  const data = new Uint8Array([value]);
  await this.newSettingCharacteristic.writeValue(data);
}
```

### 6. Add UI Component (Web App)

```vue
<!-- KB1-config/src/components/NewSettingControl.vue -->
<template>
  <div class="setting-control">
    <label>New Setting</label>
    <input 
      type="range" 
      v-model.number="value"
      min="0" 
      max="100"
      @change="handleChange"
    />
    <span>{{ value }}</span>
  </div>
</template>

<script setup lang="ts">
import { ref } from 'vue';
import { useDeviceState } from '@/composables/useDeviceState';

const value = ref(50);
const { sendNewSetting } = useDeviceState();

async function handleChange() {
  await sendNewSetting(value.value);
}
</script>
```

## Adding a New Component

**Scenario:** Creating a new settings panel component

### 1. Create Component File

```bash
touch KB1-config/src/components/NewSettings.vue
```

### 2. Component Template

```vue
<template>
  <div class="new-settings">
    <h2>New Settings</h2>
    <div class="settings-grid">
      <div class="setting-item">
        <label>Setting 1</label>
        <input v-model="settings.setting1" type="number" />
      </div>
      <!-- More settings... -->
    </div>
    
    <div class="actions">
      <button @click="handleApply" class="btn-primary">Apply</button>
      <button @click="handleReset" class="btn-secondary">Reset</button>
    </div>
  </div>
</template>

<script setup lang="ts">
import { ref } from 'vue';
import { useDeviceState } from '@/composables/useDeviceState';

interface Settings {
  setting1: number;
  setting2: number;
}

const settings = ref<Settings>({
  setting1: 0,
  setting2: 0,
});

const { sendSettings } = useDeviceState();

async function handleApply() {
  await sendSettings(settings.value);
}

function handleReset() {
  settings.value = {
    setting1: 0,
    setting2: 0,
  };
}
</script>

<style scoped>
.new-settings {
  background: var(--kb1-bg-secondary);
  padding: var(--kb1-spacing-lg);
  border-radius: var(--kb1-border-radius);
}

.settings-grid {
  display: grid;
  grid-template-columns: repeat(auto-fit, minmax(200px, 1fr));
  gap: var(--kb1-spacing-md);
}

.btn-primary {
  background: var(--btn-primary-bg);
  color: var(--btn-primary-color);
}
</style>
```

### 3. Add to Router (if needed)

```typescript
// KB1-config/src/router/index.ts
import NewSettings from '@/components/NewSettings.vue';

const routes = [
  // ... existing routes
  {
    path: '/new-settings',
    component: NewSettings,
  },
];
```

## Debugging Workflows

### Firmware Serial Debugging

```cpp
// Enable in Constants.h
#define SERIAL_PRINT_ENABLED true

// Use macros in code
SERIAL_PRINT("Value: ");
SERIAL_PRINTLN(myValue);
SERIAL_PRINTF("CC: %d, Value: %d\n", ccNumber, ccValue);
```

```bash
# Monitor output
pio device monitor

# Or with baud rate
pio device monitor -b 115200
```

### Web App Console Debugging

```typescript
// BLE debugging
console.log('Connected:', device.name);
console.log('Characteristic:', uuid);
console.log('Data:', Array.from(new Uint8Array(dataView.buffer)));

// State debugging
console.log('Settings:', JSON.stringify(settings, null, 2));

// Error handling
try {
  await bleClient.connect();
} catch (error) {
  console.error('Connection failed:', error);
}
```

### Browser DevTools

1. **Network Tab:** Monitor BLE traffic (limited visibility)
2. **Console Tab:** View logs and errors
3. **Application Tab:** Inspect localStorage presets
4. **Elements Tab:** Inspect computed CSS variables

## Testing Workflows

### Firmware Testing

```bash
# Build and flash
./build_complete.sh
pio run -t upload -e seeed_xiao_esp32s3

# Monitor serial output
pio device monitor

# Test checklist:
# - Device boots successfully
# - BLE advertises
# - Settings read/write work
# - Sleep timers behave correctly
# - Levers/buttons respond
# - MIDI output correct
```

### Web App Testing

```bash
# Run dev server
npm run dev

# Open in Chrome/Edge (Web Bluetooth required)
# Test checklist:
# - BLE connection works
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

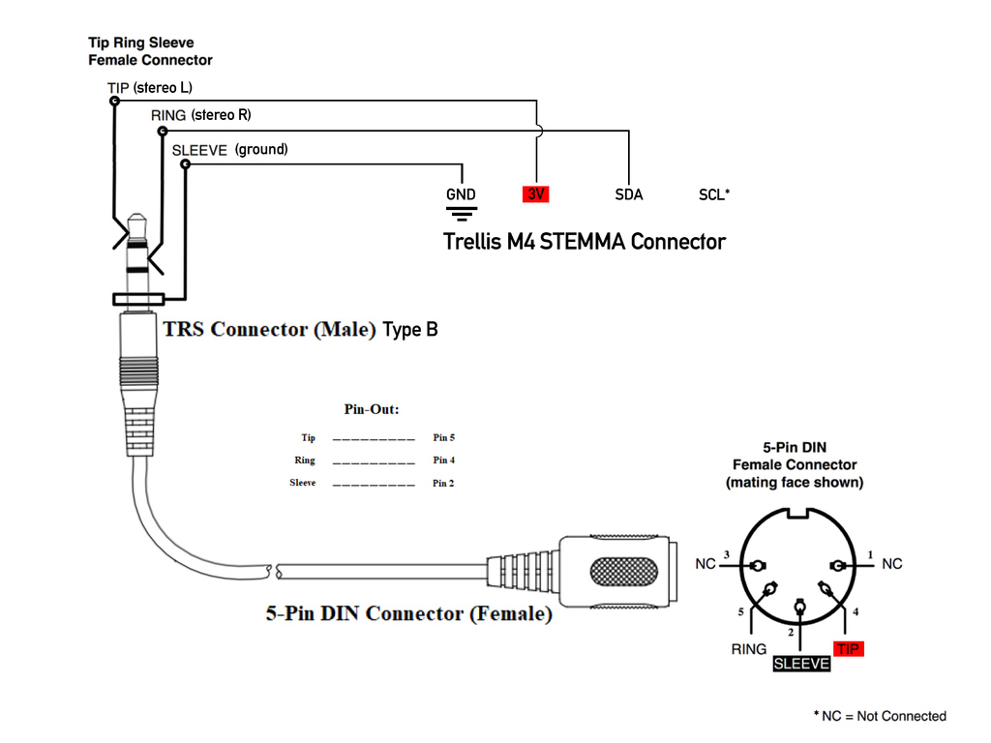
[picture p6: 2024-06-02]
references/hardware/IO/Midi/trs midi B.jpg

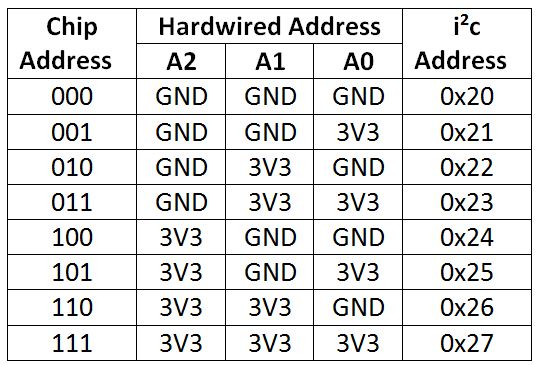
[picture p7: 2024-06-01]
references/hardware/IO/IO Expander/MCP23017-addresspins1.jpg

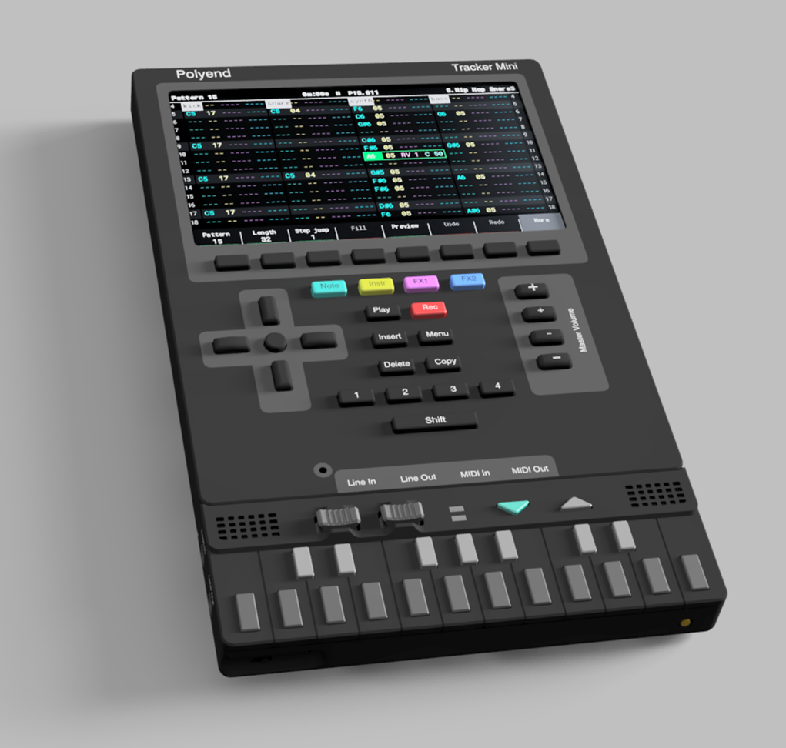
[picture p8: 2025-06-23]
assets/hero_1.png

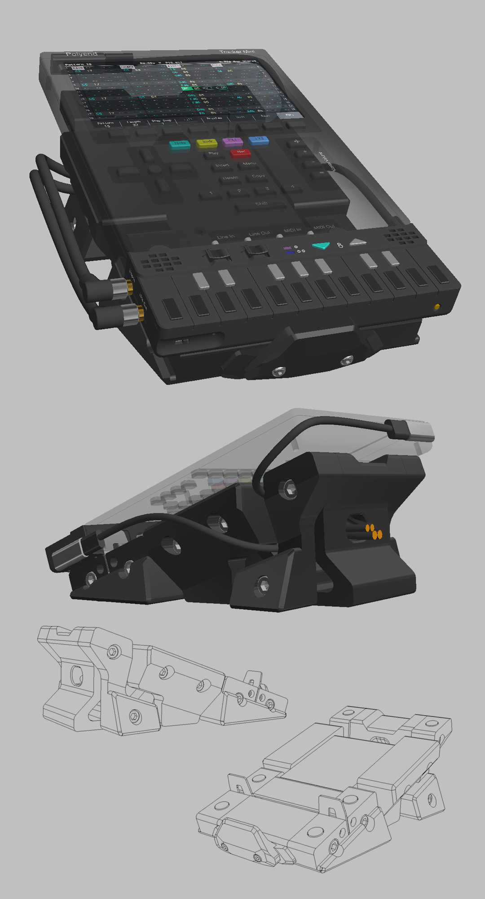
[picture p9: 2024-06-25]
assets/desktop.jpg

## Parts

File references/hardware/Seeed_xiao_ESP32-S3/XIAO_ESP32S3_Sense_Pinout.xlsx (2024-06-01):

Name | No. | Type | Power Domain | Function
LNA_IN | 1 | I/O | — | RF input and output
VDD3P3 | 2 | PA | — | Analog Power
VDD3P3 | 3 | PA | — | Analog Power
CHIP_PU | 4 | I | VDD3P3_RTC | High level: chip enable; Low: chip off; Note that the CHIP_PU pin cannot be left floating.
GPIO0 | 5 | I/O/T | VDD3P3_RTC | RTC_GPIO0 | GPIO0 |  |  |  |  |  | BOOT
GPIO1 | 6 | I/O/T | VDD3P3_RTC | RTC_GPIO1 | GPIO1 | TOUCH1 | ADC1_CH0 |  |  |  | D0 | A0 | GPIO1 | TOUCH1
GPIO2 | 7 | I/O/T | VDD3P3_RTC | RTC_GPIO2 | GPIO2 | TOUCH2 | ADC1_CH1 |  |  |  | D1 | A1 | GPIO2 | TOUCH2
GPIO3 | 8 | I/O/T | VDD3P3_RTC | RTC_GPIO3 | GPIO3 | TOUCH3 | ADC1_CH2 |  |  |  | D2 | A2 | GPIO3 | TOUCH3
GPIO4 | 9 | I/O/T | VDD3P3_RTC | RTC_GPIO4 | GPIO4 | TOUCH4 | ADC1_CH3 |  |  |  | D3 | A3 | GPIO4 | TOUCH4
GPIO5 | 10 | I/O/T | VDD3P3_RTC | RTC_GPIO5 | GPIO5 | TOUCH5 | ADC1_CH4 |  |  |  | D4 | A4 | GPIO5 | TOUCH5 | SDA
GPIO6 | 11 | I/O/T | VDD3P3_RTC | RTC_GPIO6 | GPIO6 | TOUCH6 | ADC1_CH5 |  |  |  | D5 | A5 | GPIO6 | TOUCH6 | SCL
GPIO7 | 12 | I/O/T | VDD3P3_RTC | RTC_GPIO7 | GPIO7 | TOUCH7 | ADC1_CH6 |  |  |  | D8 | A8 | GPIO7 | TOUCH7 | SCK
GPIO8 | 13 | I/O/T | VDD3P3_RTC | RTC_GPIO8 | GPIO8 | TOUCH8 | ADC1_CH7 | SUBSPICS1 |  |  | D9 | A9 | GPIO8 | TOUCH8 | MISO
GPIO9 | 14 | I/O/T | VDD3P3_RTC | RTC_GPIO9 | GPIO9 | TOUCH9 | ADC1_CH8 | SUBSPIHD | FSPIHD |  | D10 | A10 | GPIO9 | TOUCH9 | MOSI
GPIO10 | 15 | I/O/T | VDD3P3_RTC | RTC_GPIO10 | GPIO10 | TOUCH10 | ADC1_CH9 | FSPIIO4 | SUBSPICS0 | FSPICS0 | XMCLK |  | GPIO10
GPIO11 | 16 | I/O/T | VDD3P3_RTC | RTC_GPIO11 | GPIO11 | TOUCH11 | ADC2_CH0 | FSPIIO5 | SUBSPID | FSPID | Y8 |  | GPIO11
GPIO12 | 17 | I/O/T | VDD3P3_RTC | RTC_GPIO12 | GPIO12 | TOUCH12 | ADC2_CH1 | FSPIIO6 | SUBSPICLK | FSPICLK | Y7 |  | GPIO12
GPIO13 | 18 | I/O/T | VDD3P3_RTC | RTC_GPIO13 | GPIO13 | TOUCH13 | ADC2_CH2 | FSPIIO7 | SUBSPIQ | FSPIQ | PCLK |  | GPIO13
GPIO14 | 19 | I/O/T | VDD3P3_RTC | RTC_GPIO14 | GPIO14 | TOUCH14 | ADC2_CH3 | FSPIDQS | SUBSPIWP | FSPIWP | Y6 |  | GPIO14
VDD3P3_RTC | 20 | PA | — | Analog Power
XTAL_32K_P | 21 | I/O/T | VDD3P3_RTC | RTC_GPIO15 | GPIO15 | U0RTS | ADC2_CH4 | XTAL_32K_P |  |  | Y2 |  | GPIO15
XTAL_32K_N | 22 | I/O/T | VDD3P3_RTC | RTC_GPIO16 | GPIO16 | U0CTS | ADC2_CH5 | XTAL_32K_N |  |  | Y5 |  | GPIO16
GPIO17 | 23 | I/O/T | VDD3P3_RTC | RTC_GPIO17 | GPIO17 | U1TXD | ADC2_CH6 |  |  |  | Y3 |  | GPIO17
GPIO18 | 24 | I/O/T | VDD3P3_RTC | RTC_GPIO18 | GPIO18 | U1RXD | ADC2_CH7 | CLK_OUT3 |  |  | Y4 |  | GPIO18
GPIO19 | 25 | I/O/T | VDD3P3_RTC | RTC_GPIO19 | GPIO19 | U1RTS | ADC2_CH8 | CLK_OUT2 | USB_D- |  | D-
GPIO20 | 26 | I/O/T | VDD3P3_RTC | RTC_GPIO20 | GPIO20 | U1CTS | ADC2_CH9 | CLK_OUT1 | USB_D+ |  | D+
GPIO21 | 27 | I/O/T | VDD3P3_RTC | RTC_GPIO21 | GPIO21 |  |  |  |  |  | User_LED |  | GPIO21
SPICS1 | 28 | I/O/T | VDD_SPI | SPICS1 | GPIO26
VDD_SPI | 29 | PD | — | 1.8 V or VDD3P3_RTC power output
SPIHD | 30 | I/O/T | VDD_SPI | SPIHD | GPIO27
SPIWP | 31 | I/O/T | VDD_SPI | SPIWP | GPIO28
SPICS0 | 32 | I/O/T | VDD_SPI | SPICS0 | GPIO29
SPICLK | 33 | I/O/T | VDD_SPI | SPICLK | GPIO30
SPIQ | 34 | I/O/T | VDD_SPI | SPIQ | GPIO31
SPID | 35 | I/O/T | VDD_SPI | SPID | GPIO32
SPICLK_N | 36 | I/O/T | VDD_SPI | SPICLK_N_DIFF | GPIO48 | SUBSPICLK_N_DIFF |  |  |  |  | Y9 |  | GPIO48
SPICLK_P | 37 | I/O/T | VDD_SPI | SPICLK_P_DIFF | GPIO47 | SUBSPICLK_P_DIFF |  |  |  |  | HREF |  | GPIO47
GPIO33 | 38 | I/O/T | VDD3P3_CPU / VDD_SPI | SPIIO4 | GPIO33 | FSPIHD | SUBSPIHD
GPIO34 | 39 | I/O/T | VDD3P3_CPU / VDD_SPI | SPIIO5 | GPIO34 | FSPICS0 | SUBSPICS0
GPIO35 | 40 | I/O/T | VDD3P3_CPU / VDD_SPI | SPIIO6 | GPIO35 | FSPID | SUBSPID
GPIO36 | 41 | I/O/T | VDD3P3_CPU / VDD_SPI | SPIIO7 | GPIO36 | FSPICLK | SUBSPICLK
GPIO37 | 42 | I/O/T | VDD3P3_CPU / VDD_SPI | SPIDQS | GPIO37 | FSPIQ | SUBSPIQ
GPIO38 | 43 | I/O/T | VDD3P3_CPU | GPIO38 | FSPIWP | SUBSPIWP |  |  |  |  | VSYNC |  | GPIO38
MTCK | 44 | I/O/T | VDD3P3_CPU | MTCK | GPIO39 | CLK_OUT3 | SUBSPICS1 |  |  |  | Cam_SCL |  | GPIO39 | MTCK
MTDO | 45 | I/O/T | VDD3P3_CPU | MTDO | GPIO40 | CLK_OUT2 |  |  |  |  | Cam_SDA |  | GPIO40 | MTDO
VDD3P3_CPU | 46 | PD | — | CPU IO power input
MTDI | 47 | I/O/T | VDD3P3_CPU | MTDI | GPIO41 | CLK_OUT1 |  |  |  |  | D12 | PDM_DATA | GPIO41 | MTDI
MTMS | 48 | I/O/T | VDD3P3_CPU | MTMS | GPIO42 |  |  |  |  |  | D11 | PDM_CLK | GPIO42 | MTMS
U0TXD | 49 | I/O/T | VDD3P3_CPU | U0TXD | GPIO43 | CLK_OUT1 |  |  |  |  | D6 | TX | GPIO43
U0RXD | 50 | I/O/T | VDD3P3_CPU | U0RXD | GPIO44 | CLK_OUT2 |  |  |  |  | D7 | RX | GPIO44
GPIO45 | 51 | I/O/T | VDD3P3_CPU | GPIO45
GPIO46 | 52 | I/O/T | VDD3P3_CPU | GPIO46
XTAL_N | 53 | — | — | External master crystal output
XTAL_P | 54 | — | — | External master crystal input
VDDA1 | 55 | PA | — | Analog Power
VDDA2 | 56 | PA | — | Analog Power
GND | 57 | G | — | GND
 |  |  |  |  |  |  |  |  |  | BOOT
 |  |  |  |  |  |  |  |  |  | JTAG
 |  |  |  |  |  |  |  |  |  | Camera
 |  |  |  |  |  |  |  |  |  | TOUCH
 |  |  |  |  |  |  |  |  |  | SPI
 |  |  |  |  |  |  |  |  |  | ALL PWM
 |  |  |  |  |  |  |  |  |  | USB
 |  |  |  |  |  |  |  |  |  | Analog
 |  |  |  |  |  |  |  |  |  | IIC
 |  |  |  |  |  |  |  |  |  | Digital
 |  |  |  |  |  |  |  |  |  | GPIO
 |  |  |  |  |  |  |  |  |  | MIC
 |  |  |  |  |  |  |  |  |  | UART
 |  |  |  |  | BPI-PicoW-S3 外设GPIO管脚分配
 |  |  |  |  | 外设接口 | 信号 | 管脚
 |  |  |  |  | ADC | ADC1_CH0~9 | GPIO 1~10
 |  |  |  |  |  | ADC2_CH0~9 | GPIO 11~20
 |  |  |  |  | 触摸传感器 | TOUCH1~14 | GPIO 1~14
 |  |  |  |  | JTAG | MTCK | GPIO 39
 |  |  |  |  |  | MTDO | GPIO 40
 |  |  |  |  |  | MTDI | GPIO 41
 |  |  |  |  |  | MTMS | GPIO 42
 |  |  |  |  | UART | 默认分配管脚，可重定义为任意GPIO
 |  |  |  |  |  | U0RXD_in | GPIO 44
 |  |  |  |  |  | U0CTS_in | GPIO 16
 |  |  |  |  |  | U0DSR_in | 任意GPIO
 |  |  |  |  |  | U0TXD_out | GPIO43
 |  |  |  |  |  | U0RTS_out | GPIO 15
 |  |  |  |  |  | U0DTR_out | 任意GPIO
 |  |  |  |  |  | U1RXD_in | GPIO 18
 |  |  |  |  |  | U1CTS_in | GPIO 20
 |  |  |  |  |  | U1DSR_in | 任意GPIO
 |  |  |  |  |  | U1TXD_out | GPIO 17
 |  |  |  |  |  | U1RTS_out | GPIO 19
 |  |  |  |  |  | U1DTR_out | 任意GPIO
 |  |  |  |  |  | U2 | 任意GPIO
 |  |  |  |  | I2C | 任意GPIO
 |  |  |  |  | PWM | 任意GPIO
 |  |  |  |  | I2S | 任意GPIO
 |  |  |  |  | LCD | 任意GPIO
 |  |  |  |  | CAMERA | 任意GPIO
 |  |  |  |  | RMT | 任意GPIO
 |  |  |  |  | SPI0/1 | 已用于FLASH与PSRAM
 |  |  |  |  | SPI2/3 | 任意GPIO
 |  |  |  |  | 脉冲计数器 | 任意GPIO
 |  |  |  |  | USB OTG | D- | GPIO 19（内部 PHY）
 |  |  |  |  |  | D+ | GPIO 20（内部 PHY）
 |  |  |  |  |  | VP | GPIO 42（外部 PHY）
 |  |  |  |  |  | VM | GPIO 41（外部 PHY）
 |  |  |  |  |  | RCV | GPIO21（外部 PHY）
 |  |  |  |  |  | OEN | GPIO 40（外部 PHY）
 |  |  |  |  |  | VPO | GPIO 39（外部 PHY）
 |  |  |  |  |  | VMO | GPIO38（外部 PHY）
 |  |  |  |  | USB Serial/JTAG | D- | GPIO 19（内部 PHY）
 |  |  |  |  |  | D+ | GPIO 20（内部 PHY）
 |  |  |  |  |  | VP | GPIO 42（外部 PHY）
 |  |  |  |  |  | VM | GPIO 41（外部 PHY）
 |  |  |  |  |  | OEN | GPIO 40（外部 PHY）
 |  |  |  |  |  | VPO | GPIO 39（外部 PHY）
 |  |  |  |  |  | VMO | GPIO38（外部 PHY）
 |  |  |  |  | SD/MMC | 任意GPIO
 |  |  |  |  | MCPWM | 任意GPIO
 |  |  |  |  | TWAI | 任意GPIO
 |  |  |  |  | 彩色LED | GPIO 48
 |  |  |  |  | 单色LED | GPIO 46

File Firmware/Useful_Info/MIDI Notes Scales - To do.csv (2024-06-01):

Button | MIDI | Chromatic Scale | MIDI | C Minor Scale | MIDI | C Blues Scale
 | Value | Note - Frequency | Value | Note | Value | Note
SW1 | MIDI 59 | B3 - 246.94hz | MIDI 58 | A3♯/B♭3 - 233.08hz | MIDI 58 | A3♯/B♭3 - 233.08hz
SW2 | MIDI 60 | C4 - 261.63hz | MIDI 60 | C4 - 261.63hz | MIDI 60 | C4 - 261.63hz
SB1 | MIDI 61 | C4♯/D♭4 - 277.18hz | MIDI 60 | C4 - 261.63hz | MIDI 60 | C4 - 261.63hz
SW3 | MIDI 62 | D4 - 293.67hz | MIDI 62 | D4 - 293.67hz | MIDI 60 | C4 - 261.63hz
SB2 | MIDI 63 | D4♯/E♭4 - 311.13hz | MIDI 63 | D4♯/E♭4 - 311.13hz | MIDI 63 | D4♯/E♭4 - 311.13hz
SW4 | MIDI 64 | E4 - 329.63hz | MIDI 63 | D4♯/E♭4 - 311.13hz | MIDI 63 | D4♯/E♭4 - 311.13hz
SW5 | MIDI 65 | F4 - 349.23hz | MIDI 65 | F4 - 349.23hz | MIDI 65 | F4 - 349.23hz
SB3 | MIDI 66 | F4♯/G♭4 - 369.99 | MIDI 65 | F4 - 349.23hz | MIDI 66 | F4♯/G♭4 - 369.99
SW6 | MIDI 67 | G4 - 392hz | MIDI 67 | G4 - 392hz | MIDI 67 | G4 - 392hz
SB4 | MIDI 68 | G4♯/A♭4 - 415.3hz | MIDI 68 | G4♯/A♭4 - 415.3hz | MIDI 67 | G4 - 392hz
SW7 | MIDI 69 | A4 - 440hz Concert Pitch | MIDI 68 | G4♯/A♭4 - 415.3hz | MIDI 67 | G4 - 392hz
SB5 | MIDI 70 | A4♯/B♭4 - 466.16hz | MIDI 70 | A4♯/B♭4 - 466.16hz | MIDI 70 | A4♯/B♭4 - 466.16hz
SW8 | MIDI 71 | B4 - 493.88hz | MIDI 70 | A4♯/B♭4 - 466.16hz | MIDI 70 | A4♯/B♭4 - 466.16hz
SW9 | MIDI 72 | C5 - 523.25hz | MIDI 72 | C5 - 523.25hz | MIDI 72 | C5 - 523.25hz
SB6 | MIDI 73 | C5♯/D♭5 - 554.37hz | MIDI 72 | C5 - 523.25hz | MIDI 72 | C5 - 523.25hz
SW10 | MIDI 74 | D5 - 587.33hz | MIDI 74 | D5 - 587.33hz | MIDI 72 | C5 - 523.25hz
SB7 | MIDI 75 | D5♯/E♭5 - 622.25hz | MIDI 75 | D5♯/E♭5 - 622.25hz | MIDI 75 | D5♯/E♭5 - 622.25hz
SW11 | MIDI 76 | E5 - 659.26hz | MIDI 75 | D5♯/E♭5 - 622.25hz | MIDI 75 | D5♯/E♭5 - 622.25hz
SW12 | MIDI 77 | F5 - 689.46hz | MIDI 77 | F5 - 689.46hz | MIDI 77 | F5 - 689.46hz

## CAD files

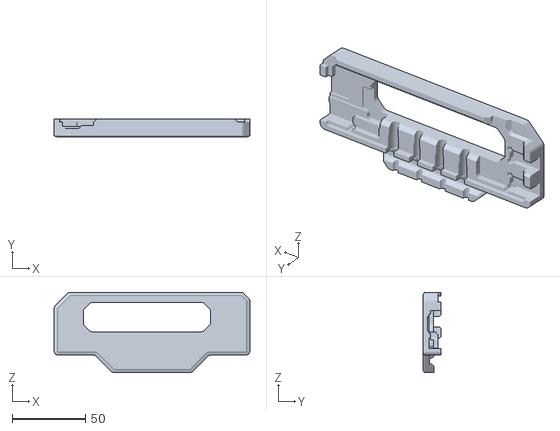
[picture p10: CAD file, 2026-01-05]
hardware/mechanicals/STLs/KB1_Assembly_jig 1.stl
134.0 x 12.6 x 55.0

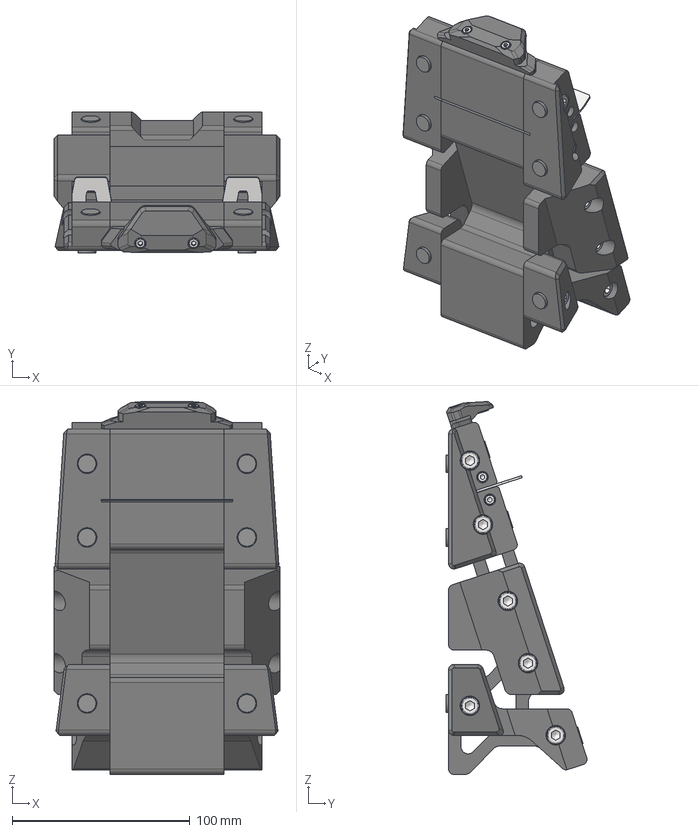
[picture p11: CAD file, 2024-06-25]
hardware/mechanicals/STEPs/Stand_1.stp
127.0 x 79.4 x 210.0 mm
Pry Plate KB1
Wedge
Wedge R1
Wedge R1_MIR
ANSI B18.3.1M - M6x1 x 30, BSHCSM x 10
ANSI B18.3.1M - M6x1 x 30, BSHCSM_1 x 2
Heatset-M6-12 x 12
ANSI B18.3.1M - M3x0.5 x 20, BSHCSM x 6
Heatset-M3-10 x 2
10 mm pad x 14
Wedge Keeper

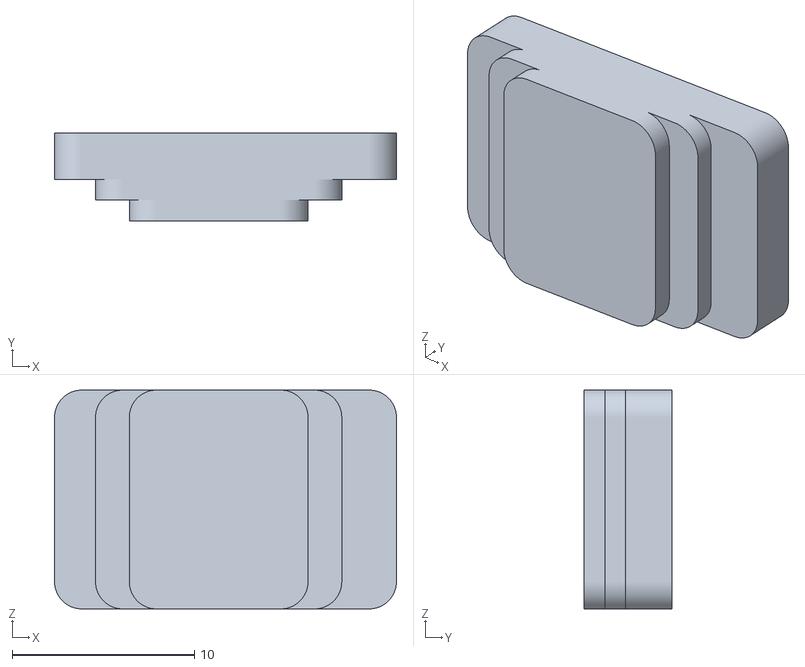
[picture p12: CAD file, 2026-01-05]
hardware/mechanicals/STLs/jig insert.stl
18.8 x 4.80 x 12.0

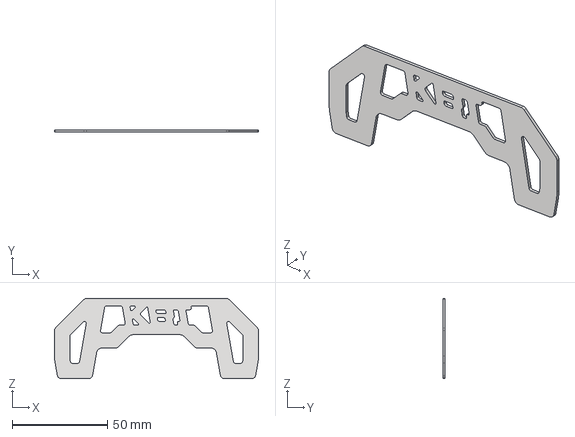
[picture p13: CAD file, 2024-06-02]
hardware/mechanicals/STEPs/Pry Plate KB1.stp
107.0 x 1.22 x 42.0 mm

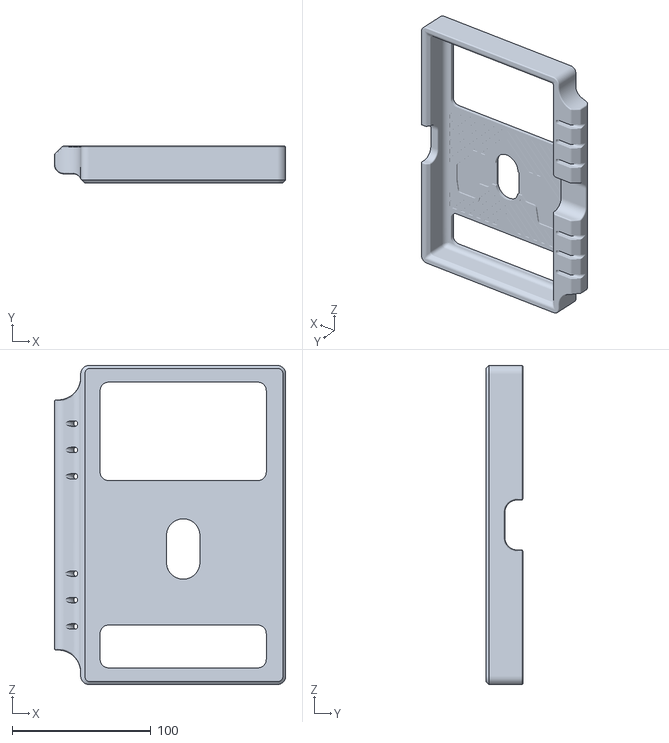
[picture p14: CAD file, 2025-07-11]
hardware/mechanicals/STLs/A5 frame.stl
166.5 x 26.5 x 229.5

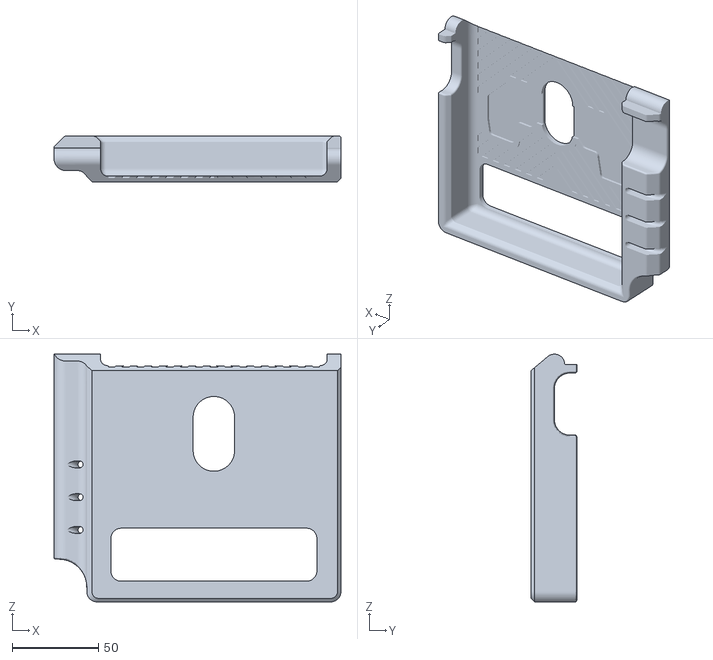
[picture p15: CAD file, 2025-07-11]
hardware/mechanicals/STLs/A5 frame 1a.stl
166.5 x 26.5 x 143.8

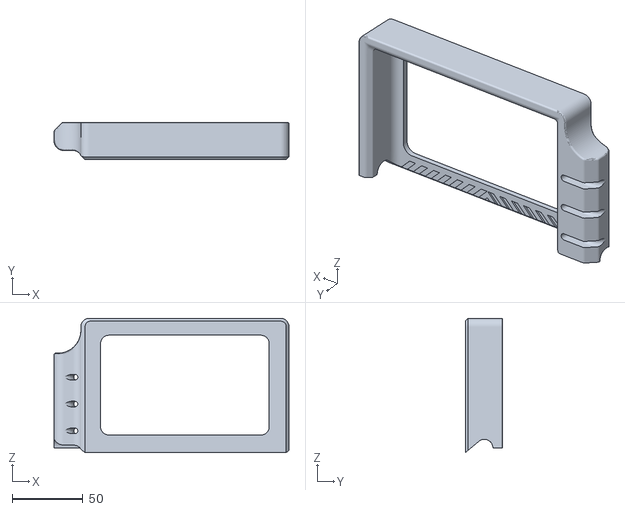
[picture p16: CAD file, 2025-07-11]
hardware/mechanicals/STLs/A5 frame 1b.stl
166.5 x 26.5 x 95.2

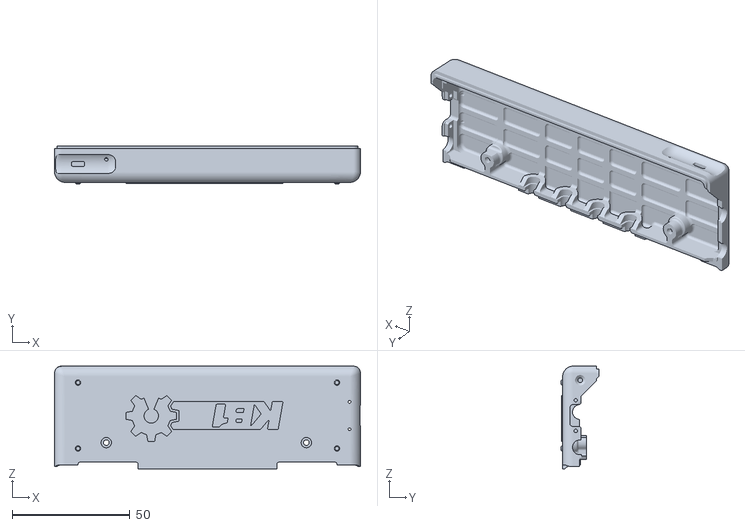
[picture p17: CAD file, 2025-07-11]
hardware/mechanicals/STLs/PTM KB case lower.stl
130.0 x 16.0 x 43.7

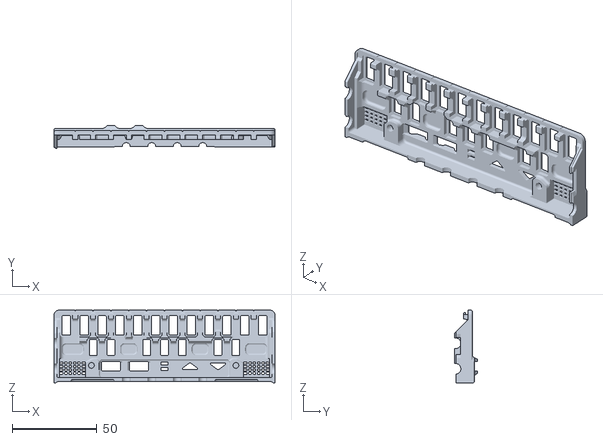
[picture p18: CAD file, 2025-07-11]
hardware/mechanicals/STLs/PTM KB case upper.stl
130.0 x 13.4 x 42.8

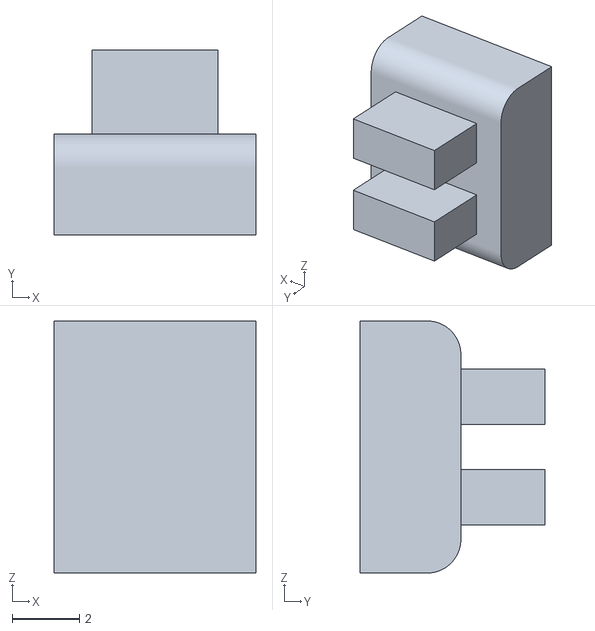
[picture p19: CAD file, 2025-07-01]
hardware/mechanicals/STLs/LED Indicator 1.stl
6.00 x 5.50 x 7.50

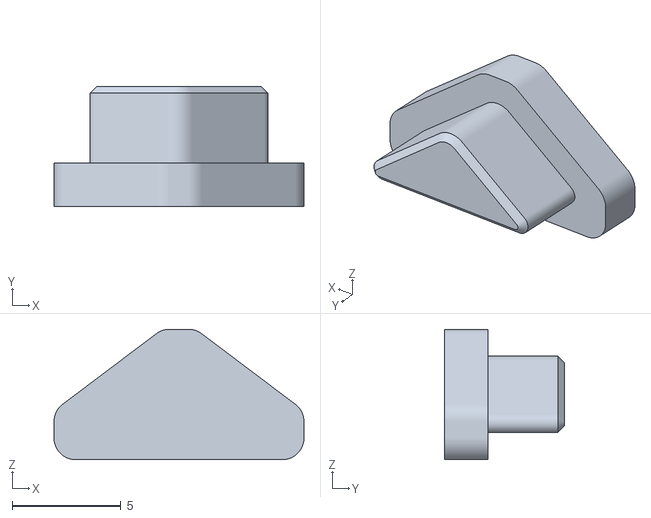
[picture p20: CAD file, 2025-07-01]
hardware/mechanicals/STLs/LED Arrow Button.stl
11.5 x 5.50 x 6.00

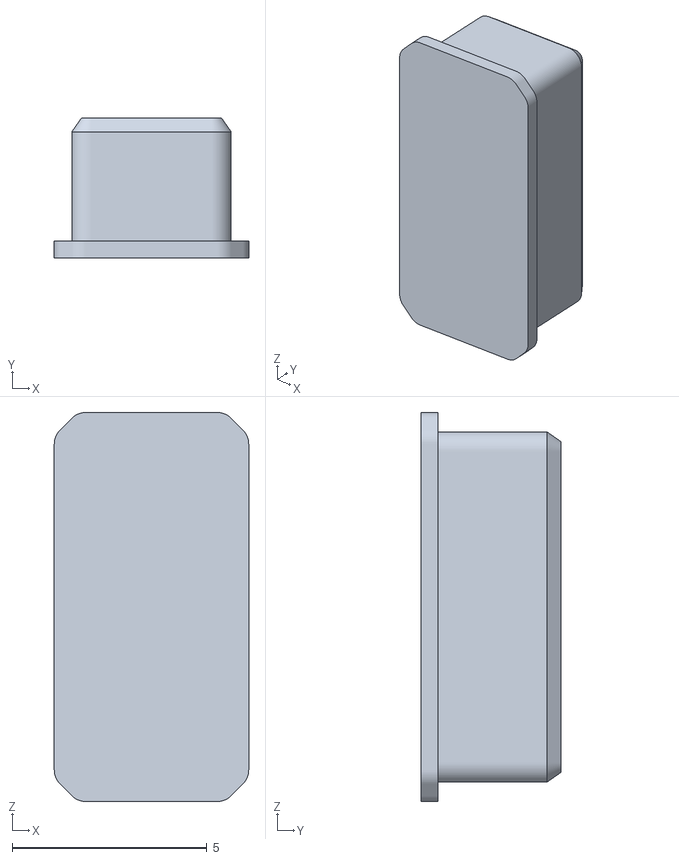
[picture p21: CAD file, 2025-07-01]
hardware/mechanicals/STLs/S&F_01.stl
5.00 x 3.60 x 10.0

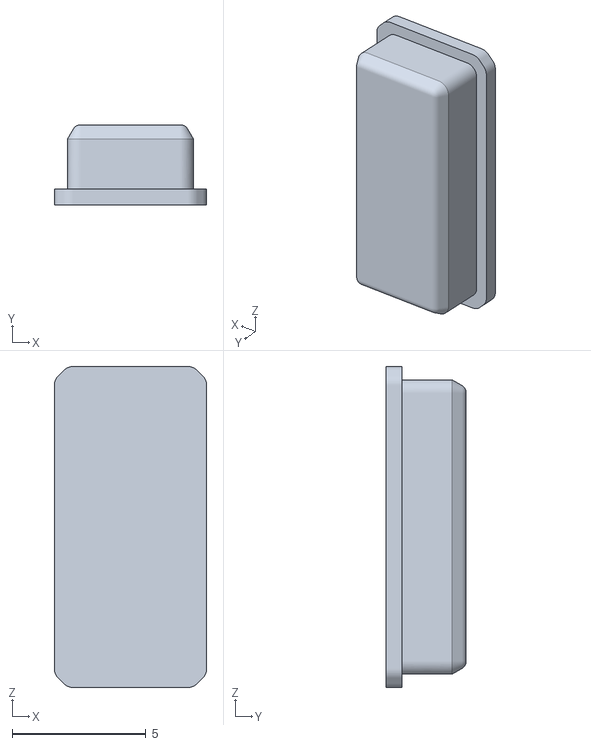
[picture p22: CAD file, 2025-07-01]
hardware/mechanicals/STLs/Nat_01.stl
5.70 x 3.00 x 12.0

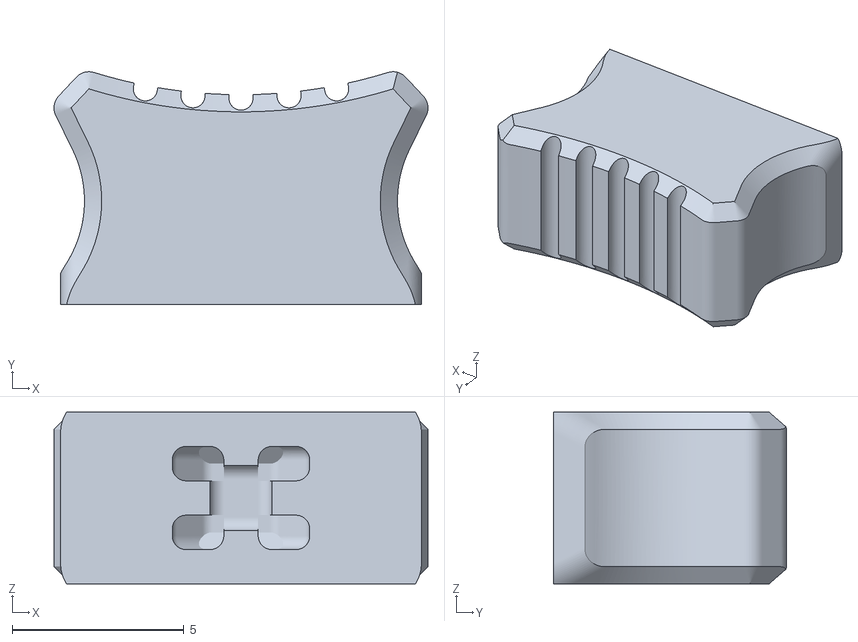
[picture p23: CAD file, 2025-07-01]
hardware/mechanicals/STLs/Lever 01.stl
10.9 x 6.77 x 5.00

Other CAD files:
hardware/mechanicals/STLs/Wedge R1.stl
hardware/mechanicals/STLs/Wedge Keeper.stl
hardware/mechanicals/STLs/Wedge_center.stl
hardware/mechanicals/STLs/Wedge R1_MIR.stl
hardware/mechanicals/STLs/Pry Plate KB1.stl

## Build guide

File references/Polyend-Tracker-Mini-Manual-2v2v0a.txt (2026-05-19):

Polyend
Tracker Mini
Manual
An Official Reference for The Polyend Tracker Mini
The Tracker Mini Notebook : Reference & Guide
I
II Polyend Tracker Mini Mini Manual
Contents
1 Overview .............................................................................11
1.1 How to use this Notebook ...........................................12
1.2 Hardware Overview .....................................................13
1.3 Start Up .......................................................................15
1.4 Generic Button & Control Functions ............................16
1.5 Generic Parameter Editing ..........................................17
1.6 Functions Buttons. .......................................................18
1.7 First Steps with Factory Projects. ................................19
1.8 Introduction to Tracks ..................................................22
1.9 QWERTY Keyboard. ...................................................23
1.10 Page Layout. .............................................................24
1.11 Example Workflow. ....................................................25
1.12 Quick Reference Commands ....................................26
2 Architecture ........................................................................ 29
2.1 Glossary of Terms ........................................................30
2.2 Tracker Mini Audio Structure .......................................32
2.3 Structure of microSD Card ..........................................33
2.4 Manual Help & Tips. ....................................................35
2.5 Menu Page Map ..........................................................36
3 Projects .............................................................................. 39
3.1 Project Overview .........................................................40
3.2 Opening & Saving a Project ........................................41
3.3 Deleting a Project. .......................................................43
Polyend Tracker Mini Mini Manual
III
3.4 Project Tempo ..............................................................44
3.5 Metronome ..................................................................46
3.6 Project Pool & Instrument List .....................................48
3.7 Summary of Configuration Options .............................52
4 Pattern Format ....................................................................57
4.1 What’s a Pattern? ........................................................58
4.2 Process of Creating a Pattern .....................................59
4.3 Configuring a Pattern. .................................................60
4.4 Copying and Pasting a Pattern. ...................................64
4.5 Inverting a Selection of Steps. .....................................65
4.6 Pattern Mode Page Layout Options ............................66
4.7 Quick Start Step Creation ............................................74
5 Sequencing Steps ...............................................................77
5.1 Dedicated Step Parameter Buttons .............................78
5.2 Process of Creating a Step .........................................79
5.3 Recording Mode ..........................................................80
5.4 Manual Recording Steps .............................................81
5.5 Step Jump Recording Multiple Steps .........................85
5.6 Fill Recording Multiple Steps ......................................87
5.7 Live Recording Steps with an External Controller ......97
5.8 Note Steps .................................................................100
5.9 Instrument Step Parameters .....................................106
5.10 FX Step Parameters ................................................108
IV Polyend Tracker Mini Mini Manual
6 Instruments ........................................................................113
6.1 Instrument Overview .................................................114
6.2 Instrument Parameter Pages ....................................115
6.3 General Instrument Parameters - Page 1 .................116
6.4 Instrument Effect Parameters - Page 1 .....................119
6.5 Instrument Automation Parameters - Page 2 ............121
6.6 Sample Playback Overview .......................................127
6.7 1-Shot Play Mode ......................................................128
6.8 Loop Play Modes .......................................................130
6.9 Slice Play Modes .......................................................132
6.10 Wavetable Play Modes ............................................136
6.11 Granular Play Modes ...............................................141
6.12 Sharing Instruments ................................................144
6.13 Synthesizer Options ................................................146
6.14 Synthesizer Patch Editor Basics .............................150
6.15 Editing a Synthesizer Patch ....................................152
6.16 PERC Synthesizer Notes ........................................171
6.17 Synthesizer Macros .................................................173
7 FX Steps ............................................................................175
7.1 Step FX Descriptions .................................................176
7.2 Step FX Reference ....................................................177
7.3 None ..........................................................................178
7.4 Off ..............................................................................179
7.5 Volume ......................................................................180
Polyend Tracker Mini Mini Manual
V
7.6 Panning .....................................................................181
7.7 Micro-Tune ................................................................182
7.8 Glide ..........................................................................183
7.9 Tempo ........................................................................184
7.10 Swing .......................................................................185
7.11 Micro Move ..............................................................186
7.12 Gate Length .............................................................187
7.13 Chance ....................................................................188
7.14 Roll ..........................................................................189
7.15 Arpeggiator ..............................................................190
7.16 Random Note ..........................................................192
7.17 Random Instrument .................................................193
7.18 Random FX .............................................................194
7.19 Random Volume ......................................................195
7.20 Reverse Sample ......................................................196
7.21 Position ....................................................................197
7.22 Slice .........................................................................198
7.23 Volume LFO ............................................................199
7.24 Panning LFO ...........................................................200
7.25 Filter LFO ................................................................201
7.26 Position LFO ............................................................202
7.27 Finetune LFO ..........................................................203
7.28 Overdrive .................................................................204
7.29 Low Pass Cutoff ......................................................205
7.30 Band Pass Cutoff .....................................................206
VI Polyend Tracker Mini Mini Manual
7.31 High Pass Cutoff ......................................................207
7.32 Delay .......................................................................208
7.33 Reverb .....................................................................209
7.34 Bit Depth ..................................................................210
7.35 Tune ........................................................................211
7.36 Slide Up ...................................................................212
7.37 Slide Down ..............................................................213
7.38 MIDI Messages and Synth Macros .........................214
7.39 MIDI Chords ............................................................215
8 Audio .................................................................................217
8.1 Master Pages - Audio Control ...................................218
8.2 Audio Sources ...........................................................221
8.3 Audio Inputs ...............................................................222
8.4 Sample Formats ........................................................225
8.5 Recording Audio Workflow ........................................226
8.6 Sampling ...................................................................227
8.7 Rendering and Exporting Internal Audio ....................230
8.8 Advanced Audio Editing .............................................237
8.9 Sample Editor Effects ................................................239
8.10 Audio Output Over USB ..........................................250
9 Song Mode ........................................................................255
9.1 Tempo ........................................................................256
9.2 Arrangement Overview ..............................................257
9.3 Song Mode Interface .................................................259
9.4 Song v Pattern Relationship ......................................260
Polyend Tracker Mini Mini Manual
VII
9.5 Creating and Editing a Song .....................................261
9.6 Playing Songs and Patterns ......................................264
9.7 Link between Song and Performance Mode .............267
10 Master Effects ..................................................................269
10.1 Effects Overview ......................................................270
10.2 Master Pages ..........................................................271
10.3 Master Delay ...........................................................272
10.4 Master Reverb .........................................................274
10.5 Limiter ......................................................................276
10.6 Saturation, Space & Bass Boost .............................278
10.7 EQ ...........................................................................279
10.8 Effect Config Options ...............................................281
11 MIDI .................................................................................283
11.1 MIDI Definitions .......................................................284
11.2 MIDI Configuration ...................................................285
11.3 Typical MIDI Configurations .....................................287
11.4 MIDI Instrument Overview .......................................290
11.5 Handling MIDI Velocity .............................................292
11.6 MIDI CC Out ............................................................293
11.7 MIDI CC In ...............................................................296
11.8 Program Change .....................................................297
11.9 MIDI Synthesizer .....................................................298
12 Performance Mode ..........................................................303
12.1 Performance Mode Overview ..................................304
VIII Polyend Tracker Mini Mini Manual
12.2 Perform - Quick Start ...............................................305
12.3 Selecting Tracks ......................................................306
12.4 Perform Effect Values ..............................................307
12.5 Configuring Effects ..................................................308
12.6 Perform Effects List .................................................310
12.7 Remixing .................................................................311
12.8 Controlling Performances with MIDI ........................313
12.9 Advanced Pattern Playback ....................................314
13 System ........................................................................... 317
13.1 Device Registration .................................................318
13.2 Generic Firmware Update .......................................319
13.3 Emergency Firmware Update ..................................320
13.4 Resetting the Configuration .....................................321
13.5 User Interface Style .................................................322
13.6 Assignable Function Buttons ...................................323
13.7 Screen Capturing ....................................................324
13.8 Games .....................................................................325
13.9 Card Compatibility & Backing Up ............................326
13.10 USB Storage .........................................................328
13.11 Hexadecimal Option ..............................................330
13.12 Official Specifications ............................................331
13.13 Changelog .............................................................332
14 Index ............................................................................... 335
Polyend Tracker Mini Mini Manual
IX
X Polyend Tracker Mini Manual
Overview
Polyend Tracker Mini is a handheld version of
the desktop Polyend Tracker. This is a modern
hardware implementation of a classic software
music application that emerged in the late 80s
as music-making tools, mainly on gaming
machines and later on personal computers. A
Tracker is a utility that assembles a linear
series of notes that typically triggers samples
and associated parameters. Unlike standard
digital audio workstations (DAW), Trackers
generally run top to bottom when playing
tracks. Trackers usually had a niche community
of followers and never reached the same height
of popularity as other DAWs. Polyend Tracker
Mini reignites the interest and presents the
composition features of a Tracker in a portable
and immediate format. Don't be fooled by this
quirky programming style of music making,
which may appear unusual but does provide a
compelling and creative approach to
production. Polyend Tracker Mini presents this
vintage application in a modern and stylish
Polyend Tracker Mini Manual
1
handheld box with sixteen sequenced tracks and
various effects, MIDI and Audio In / Out, and
multiple workflow environments. With a small
form factor and rechargeable battery, the Tracker
Mini is an ideal portable 'all in one' workstation.
The feature set is broad and has some
interestingly creative functions. Tracker Mini isn't
a complicated instrument to use, but the unusual
and less familiar core concept and workflow may
mean that getting started is a little confusing and
the learning curve is drawn out. This may be a
different twist on music production, but hey, that's
what makes it fun. This guide aims to help speed
up learning and get the very best from the
device. As always, the Synthdawg notebook
style allows for your notes to be added and
makes the guidebook personal for you. The
Tracker Mini journey is unusual yet fun, and at
the same time, it is a powerful music-making unit
that gives some rewarding results. Enjoy.
11
1
Overview
1.1 How to use this Notebook
Sections are laid out to cover the full workflow with walkthroughs, step by
step guides and tips. Some pages carry a wide margin and some are
intentionally blank enabling you to make your own notes.
Control conventions.
(Enter)
D-Pad for navigation options are shown with rounded parentheses. These
represent the 5 physical direction buttons. These include, (Up), (Down),
(Right), (Left) as well as the central (Enter) button.
[+] / [-]
The master [+] & [-] buttons navigate and for some parameters adjust it’s
values. The outer buttons make changes in larger increments. Also used to
adjust the master volume level.
[Function]
Square parentheses contain general functions that are selectable by one of
the other 15 physically dedicated buttons - either as a primary or secondary
function. Examples are [Rec], [Play], [Shift]. .
When using the [Menu] button, the pop-up menu will open while the button
is held. Highlight the specific menu option by navigating with the D-Pad
navigation buttons while holding [Menu]. Options with multiple pages are
shown by the dots underneath the option text. The currently highlighted
option is selected when the [Menu] button is released.
NOTES
Your Notes Can be written here Here
[Function] + [Option]
Functions which require multiple button selections simultaneously are
shown with a + symbol between each required button. An example is the
[Shift] + [Copy] command.
[Dynamic Screen Key]
The 8 dynamic screen buttons located directly under the display will be
Did you know?
written using italic text. The actual function that each button serves will
change depending on the current context. The function it serves will be
Music Trackers emerged
in labelled on the screen label above each button on the device. Currently
the late 1980’s on gaming computers?
unavailable options will show on the screen as dimmed text. Dynamic
screen key examples include [Create Project], [Up] or [Down] options.
12 Polyend Tracker Mini Manual
Overview1
1.2 Hardware Overview
USB Power charge input
USB-C to USB-A cable supplied
microSD card slot.
Pins facing to the front panel.
16GB microSD card & adapter supplied
On / Off button
20 mm
130 mm
170 mm
+
+
-
-
Master Volume
Line In Line Out MIDI In MIDI Out
3.5mm male stereo TRS jack to
2 x 6.3mm TR mono female.
Adapter supplied.
3.5mm jack to 5 Pin MIDI.
Adapter (Type B) supplied
Stereo audio output also
serves as headphone out.
Polyend Tracker Mini Manual
13
1
Overview
1
2
5
6
7
8
Note Instr FX1 FX2
16
+
3
9
Play Rec
10
+
11
Insert Menu
12 17
-
Master Volume
Master Volume
13
Delete Copy
14
-
16
2
1 3 4
15
Shift
4
18
Line In MIDI In
Line Out MIDI Out
1
LCD Display
5 Inch, LCD TFT 800 x 480 Display.
2
3
D-Pad Navigator Buttons
Four navigation pad buttons (Up), (Down), (Left), (Right)
and one (Enter). Manoeuvre through the grid and options.
4
5
Dedicated Note Button
Selection of the [Note] element of a step.
6
7
Dedicated FX1 Button
Effect selection for [FX1] of a step.
8
9 10
Play Button
Plays when pressing [Play] the pattern or song. Pressing
again stops playback. Play again restarts.
Insert / Home Button
11 12
Pressing [Insert] will insert. Pressing [Shift] + [Insert] will
return ‘home’, to the top of the pattern.
Delete Button
13 14
Pressing [Delete] will reset or step back.
[Shift] + [Delete] will backspace delete the selected item.
Function Buttons
15 16
Assignable function buttons. Default: 1 - Pattern,
2 - Inst Automation, 3 - Sample Playback, 4 - Master.
17
Master [+] / [-] Buttons - Fine
Increases the master volume +/- in fine increments.
Also navigates and adjusts values within certain menus.
18
Screen Buttons
Dynamic [Screen buttons] are dependant on the
function displayed above each button.
Shift Button
Pressing [Shift] + Another button will select its
secondary function.
Dedicated Instrument Button
Selection of the [Instrument] for a step.
Dedicated FX2 Button
Effect selection for [FX2] of a step.
Rec Button
Pressing [Rec] will toggle the record mode on or off for
editing patterns and perform settings.
Menu Button
Hold to open the menu. Navigate to highlight a selection
from the available options. Release to select.
Copy Button
Pressing [Copy] will copy the selected item.
Use [Shift] + [Copy] to paste any copied item.
Master [+] / [-] Buttons - Course
Adjusts the master volume +/- in large increments. Also
navigates and adjusts values within certain menus.
Microphone
Internal microphone.
14 Polyend Tracker Mini Manual
Overview1
NOTES 1.3 Start Up
Tracker Mini is powered from the an internal rechargeable battery which is
charged using the supplied USB cable and charger. When restarting
Tracker Mini the previously open project will be be re-opened.
▌ POWERING ON / OFF TRACKER MINI
To recharge Tracker Mini, connect the supplied USB-C Mains cable
between Tracker Mini and the supplied USB plug to charge the unit. Once
charged Tracker Mini will operate without the USB power supply being
connected.
1. 2. 3. 4. Ensure the microSD card is installed correctly for Tracker Mini to
operate. Pins should face up towards the front panel.
To power up, hold the small power on/off button located on the top right
(looking from the front) for 1 second. Start up will open the previously
opened project.
To power off, press and hold the small power button located on the top
right (looking from the top) until the timer bar ends. Tracker Mini will
then power off.
To check battery power charge when the unit is off, press quickly the
power button. The battery indicator will display for a short period to
indicate the charging state. The battery state is also displayed if the
power cable is connected while powered off.
The charging supply is 5V, 2A from the supplied mains to USB adapter.
Press the On/Off button to power up.
Hold the On/Off button to power down.
!
Warning: Under-powering the Tracker from a hub or computer can result in performance issues or
microSD card failure. It is recommended that you only use the supplied cable and power supply to charge
Tracker Mini. Any other device used to charge Tracker Mini must adhere to the 5V, 2A maximum power
rating. Applying other chargers and power banks is entirely at the user's risk.
Polyend Tracker Mini Manual
15
1
Overview
1.4 Generic Button & Control Functions
There are a number of button commands that operate generically
throughout Tracker Mini. These are applied in a variety of situations.
Main menu browsing
Typically the [Menu] button is held while navigating the main menu. The
navigation can be performed by various button combinations.
Menu page
Hold
Menu
NOTES
Pattern
Instrument
Parameters
Sample
Playback
Song
Perform
Sample
Loader
Sample
Editor
File
Sample
Recorder
Master
Config
Games
Hold [Menu] button throughout the navigation process.
D-Pad menu navigation
(Up)
Up button scrolls one row up the order.
Left button scrolls one column left.
(Left) (Right)
Right button scrolls one column right.
(Down)
Down button scrolls one row down the order.
Master +/- buttons
+
+
-
-
+ Scrolls multiple steps in the menu.
+ Scrolls one item up the order.
- Scrolls one item down the order.
- Scrolls multiple items down the order.
Release
Menu
The menu item is selected when [Menu] button is released.
16 Polyend Tracker Mini Manual
Overview1
NOTES 1.5 Generic Parameter Editing
Pages may contain parameters and functions which once selected can be
adjusted in value. These are applied in a variety of situations.
Parameter editing
A page will need to be selected which contains the parameters to edit. For
example the ‘Master’ page contains a series of adjustable settings. The
highlighted and selected parameter will be indicated with a red bounding
box. It is this parameter that will be changed when using the D-Pad
navigator and +/- buttons.
D-Pad navigation
(Up)
Up button increases parameter value.
Left button navigates parameter selection.
(Left) (Right)
Right button navigates parameter selection.
(Down)
Down button decreases parameter value.
The central navigation button typically acts as a ‘select’ or ‘enter’ button
Master +/- buttons
+
[+] Increases value in larger increments.
+
[+] Increases value, same as (Up) button*.
-
[-] Decreases value, same as (Down) button*.
[-] Decreases value in larger increments.
-
Within fixed page menu options, the D-Pad navigation buttons and +/-
master buttons will scroll through the available options. The option is also
automatically selected when it is highlighted. The respective screen button
may also cycle through menu options when pressed repeatedly in pages.
* Inner +/- and D-Pad up / down may operate in similar fashion in some menu and value setting options.
Polyend Tracker Mini Manual
17
1
Overview
1.6 Functions Buttons.
There are 4 dedicated function buttons which allow quick access to 8 pre-
defined pages. These are numbered 1 - 4 for the first 4 functions and also
have an additional set of 4 functions by using [Shift]. These function buttons
are assignable and can be reconfigured to a range of page options but it is
recommended to start with the defaults in order to build your workflow.
NOTES
Using the assignable function buttons
Tap one of the function buttons or use [Shift] + tap, to immediately access
the defined page. The default pages that are assigned are illustrated below.
Press [1] - [4] to select a defined function page
Pattern
Instrument
Parameters
Sample
Playback
Master
2
1 3 4
Shift
Song
Sample
Loader
File
Config
Hold [Shift] + [1] - [4] to select a defined function page
The main page is selected when pressing the function buttons. If multiple pages exist,
continue to tap the respective function button to cycle through the available pages.
There are 12 available functions which can be assigned to the function
buttons with up to 8 slots available, 2 for each button. Other than those
assigned by default, the ‘Sample Recorder’, ‘Sample Editor’, ‘Perform’ and
‘Games’ functions can also be assigned in place of the default settings. The
process of binding a page to a button is explained in the configuration
settings section.
The processes described in this manual will assume the default function
button assignments as stated here. The [Menu] options are an alternate
method of selecting a specific function page.
18 Polyend Tracker Mini Manual
NOTES Overview1
1.7 First Steps with Factory Projects.
At first glance, operation of Tracker Mini appears unusual. However the
workflow is quite simple once a few fundamentals are clearly understood.
The quick start button commands shown here can be applied with the
factory projects to get familiar with the essential processes to help speed
up the learning curve. Ensure the microSD Card is installed.
▌ OPENING A PROJECT
1. 2. 3. 4. 5. 6. 7. 8. When powering on, the previous project will be restored. Projects can
be changed or new ones created. Tracker Mini will only be able to view
up to 100 projects per folder although user folders can be created.
Hold [Shift] + function [3] to perform a quick selection of the ‘file’
function page. This assumes the default ‘File’ assignment for button 3.
Alternatively use the menu navigation to access the file menu.
• Hold [Menu] + press (Up), (Down), (Left) or (Right) to scroll to
highlight the ‘File’ option. The red bounding box will indicate the
highlighted item.
• Release the [Menu] button. Releasing the button will select and
open the highlighted ‘File’ option.
Press [Open] screen button from the left. The list of available projects
will be displayed on the screen.
Press (Up) or (Down) to navigate the list of project options. Alternatively
press [Up] or [Down] screen buttons to scroll the list selection. The
highlighted option will show with a bounding box.
With the desired project highlighted, Press [Open] screen button to
open the project.
If the currently active project has been edited a prompt, ‘Do you want to
save the changes to xxxx’ will be presented. Press [Save] screen button
to save or [Don’t Save] screen button to proceed without saving. The
option to cancel is also presented.
Although not essential, it is usually good practice to select and display
the pattern page at this stage. If required, Function key [1] is assigned
by default to display the pattern page or navigate within the [Menu].
Polyend Tracker Mini Manual
19
1
Overview
NOTES
The master volume may be set loud when initially starting up. Care should
be taken when playing songs and especially if listening with headphones. It
is advised to firstly set the master volume lower before listening into a song
▌ QUICK ADJUSTMENT OF THE MASTER VOLUME.
1. Hold [Shift] + [+] / [-] buttons. The upper and lower +/- buttons change in
larger increments and the central +/- in fine increments.
▌ GENERAL ADJUSTMENT OF THE MASTER VOLUME.
1. 2. 3. 4. 5. 6. Hold function [4] + Press [-] to reduce the master volume. Use the outer
buttons for larger increments in volume. This assumes the default
assignment of button [4] to the master function pages.
To reduce in smaller increments:-
• Hold [4] + press [-] inner button.
or
• Hold [4] + press (Down).
Hold function [4] + press [+] to increase the master volume. Use the
outer [+] button for larger increments in volume. This assumes the
default assignment of button [4] to the master function pages.
To increase in smaller increments:-
• Hold [4] + press [+] inner button.
or
• Hold [4] + press (Up).
The master page can also be selected from the menu options. Hold
[Menu] and use the (Left), (Right), (Up) and (Down) D-Pad buttons.
The master volume, as displayed on the left side bar indicator and can
be adjusted between -51.5dB to +12dB.
20 Polyend Tracker Mini Manual
NOTES
Overview1
▌ PLAYING A PATTERN FROM THE PATTERN OR ANY GENERIC PAGE.
1. 2. 3. 4. Ensure a project with patterns is loaded.
Although not essential, it is usually good practice to display the pattern
page at this stage. If required, Press function [1] to display the pattern
page, this button is assigned as default. Pattern page can also be
selected in the [Menu] options.
Press [Play] to play the currently active pattern. Note that this process
will only play and loop the currently selected pattern and not the entire
song, unless the Song page is on display when pressing [Play].
Press [Play] to stop playback on the current step.
• Pressing [Play] again restarts from the pattern beginning.
• Pressing [Shift] + [Play] will restart playback from the current
paused position. If a group of steps is selected, [Shift] + [Play] will
play the selection on loop.
• Press [Shift] + [Insert] when play is stopped to reset the playhead to
the start position without commencing play.
▌ PLAYING A SONG FROM SONG PAGE.
1. 2. 3. Select song mode, Hold [Shift] + [1] where this is the default function
button assigned. This will be applicable only when a song structure has
previously been created. Songs are typically setup in factory projects.
Press [Play] to play from the currently active song row. Playback in the
Song page is different to the generic pattern play from within other page
views. Each row will represent a series of patterns across all the tracks
and will play the rows top to bottom.
Press [Play] to stop playback on the current row.
• Pressing [Play] again restarts playback starting from the beginning
of the current row.
• Pressing [Shift] + [Play] will toggle loop playback for the current row
on or off. If playback is in a stopped state, playback will start at the
beginning of the current row.
• Press [Shift] + [Insert] when play is stopped to reset the playhead to
the start of the song without commencing play.
Polyend Tracker Mini Manual
21
1
Overview
1.8 Introduction to Tracks
Tracker Mini has 16 tracks. The first 8 can operate with sample
instruments, synths and MIDI and tracks 9-16 are used for MIDI and synths
Tracks are structural elements and the track mixer is found in the master
section. Some specific track commands are also available in the pattern
pages, for example muting tracks. By default 4 tracks are displayed for
patterns and the pattern page is assigned to function button [1].
▌NAVIGATING TRACKS IN THE PATTERN PAGE
1. 2. Press function [1] to open the pattern page. 4 tracks are displayed by
default. The pattern page can also be selected in the [Menu].
Press (Left) or (Right) to navigate across all tracks. The green or red
highlighted step will anchor the navigation point on the track columns.
▌MUTING TRACKS IN PATTERN PAGE
1. 2. 3. Press [1] to ensure pattern page is selected. 4 tracks are displayed by
default. The pattern page can also be selected in the [Menu].
To mute / unmute, Press [Shift] + [Screen] button for the respective
track. Sample tracks are presented by the screen buttons when holding
the shift button. Muted tracks are displayed with the screen keys
dimmed.
Muting will be applied immediately the screen button is pressed. This is
different behaviour than in the track mixer, where muting is applied
when the mute button is released.
▌CHANGING TRACK VIEW FOR THE PATTERN PAGE
• 8 Tracks with only note parameter: Press [1] + [Note].
• 8 Tracks with instrument parameter: Press [1] + [Instrument].
• 8 Tracks with only FX1 parameter: Press [1] + [FX1].
• 8 Tracks with only FX2 parameter: Press [1] + [FX2].
• 8 Tracks with 2 selected parameters: Press [1] + [P1] + [P2], where
‘P1’ and ‘P2’ are 2 from; [Note], [Instrument], [FX1], FX2].
• Revert to 4 track mode, Press [1].
NOTES
22 Polyend Tracker Mini Manual
Overview1
NOTES 1.9 QWERTY Keyboard.
Some pages will require text editing for naming tracks or projects etc. The
same functionality applies whenever the alpha numeric pop-up editor is
used. The screen will display the QWERTY keys and the text to edit. The
screen buttons are used to enter, cancel or save while the D-Pad navigator
buttons perform the editing. Auto naming is also an option.
The screen will display the keys laid out in a QWERTY formation.
1
2
3
4
5
6
7
8
9
0
Backspace
q
w
e
r
t
y
u
i
o
p - +
a
s
d
f
g
h
j
k
l
@
Caps Lock
z
x
c
v
b
n
m
Space
Enter Auto Name Cancel
Save
The characters and the title can be selected by using (Up), (Down), (Left) or
(Right) to navigate and press the centre D-Pad navigator button or press [Insert]
or press [Enter] screen button to select and add the selected character.
Option to [Cancel] screen button is also possible.
Save when complete using [Save] screen button to save the name.
(Up)
Note Instr FX1 FX2
Play Rec
(Left) (Enter)
(Right)
(Down)
Insert Delete Menu
Copy
2
1 3 4
The Tracker Mini buttons operate in the naming editor screen when presented:-
• D-Pad (Up), (Down), (Left), (Right) will navigate the selection across the
keyboard. Will also navigate left / right in the text of the name when the
name is highlighted.
• D-Pad navigator (Centre) button or [Insert] will insert the currently
highlighted character into the name at the cursor position. Also a screen
button option.
• [Delete] to delete characters and use with [Shift] to backspace in the name
from the text cursor position.
Polyend Tracker Mini Manual
23
1
Overview
1.10 Page Layout.
Each page will display the information and control options for the selected
function. While this may be unique to the context there are some common
features and navigation principles that apply across all (or most) of the
generic pages of Tracker Mini.
Function or page currently
selected and represented on the
page. Where multiple pages exist
this will also be shown i.e. 2/3
Time position in minutes &
seconds of the current playhead.
This is total play time not time in
a pattern or song
Transport status
Selected instrument displayed,
although not shown on all pages.
This shows current project when in
the ‘File’ menu page.
Current pattern and
step position
Pattern 1 0m:00s P1.008 1.Analog 3 18p
Track 1
Track 2 Track 3 1 1
C5 40 ---- P-25 C5 40 ---- H-25 C5 40 ---- P-20 Track 4
C5 40 ---- P-25
Pattern 1 0m:00s P1.008 1.Analog 3 18p
Track 1
1 1
C5 40 ---- P-25
Track 2 C5 40 ---- H-25 Track 3 C5 40 ---- P-20
Track 4
-- --- ---- ----
2 C5 40 ---- P-25
C5 02 ---- P-20
C4 12 ---- A 4
-- --- ---- ----
2
3 3
-- --- ---- ---- -- --- ---- ---- -- --- ---- ---- -- --- ---- ----
4 4
-- --- ---- ----
C3 04 ---- P-20
C4 12 ---- A 4
-- --- ---- ----
5 5
C5 40 ----
P 25 -- --- ---- ---- -- --- ---- ----
-- --- ---- ----
Central area contains specific
6 6
-- --- ---- ---- -- --- ---- ---- -- --- ---- ---- -- --- ---- ----
information for the selected function
7 7
-- --- ---- ---- -- --- ---- ---- -- --- ---- ---- -- --- ---- ----
and settings.
8 8
-- --- ---- ---- D3 04 ---- P-10
-- --- ---- ---- -- --- ---- ----
9 9
-- --- ---- ---- -- --- ---- ---- -- --- ---- ---- -- --- ---- ----
10 -- --- ---- ---- D3 04 ---- P-10
-- --- ---- ---- -- --- ---- ----
10
11 -- --- ---- ---- -- --- ---- ---- -- --- ---- ---- -- --- ---- ----
11
12 -- --- ---- ---- D3 04 ---- P-10
-- --- ---- ---- -- --- ---- ----
12
13 -- --- ---- ---- -- --- ---- ---- -- --- ---- ---- -- --- ---- ----
13
14 -- --- ---- ---- -- --- ---- ---- -- --- ---- ---- -- --- ---- ----
14
15 -- --- ---- ---- -- --- ---- ---- -- --- ---- ---- -- --- ---- ----
15
Pattern
1
Length
32
Step Jump
0 Fill Preview Undo Redo More
15 15
-- --- ---- ---- -- --- ---- ---- -- --- ---- ---- -- --- ---- ----
Pattern
1
Length
32
Step Jump
0 Fill Preview Undo Redo More
Up to 8 selectable context based
options. These can be menu options,
navigation commands or blank.
Select page
Physical screen buttons represent
the command displayed on the
screen directly above.
Options are dimmed when not currently
available. For example, these may need
an item i.e Rec, to be selected first.
The button underscore colours represent the mode in which the command is available. Options
underscored in red are available only in [Rec] mode. Green options are available generically.
NOTES
24 Polyend Tracker Mini Manual
Overview1
1.11 Example Workflow.
The workflow adopted with Tracker Mini will of course develop to fit your personal approach. To get
started a typical journey is described below.
PROCESS
Project
Global settings usually setup or
performed once before or at the
start of a new project.
Instruments
Instruments are created by
configuring samples with
additional settings and features.
S
1
2
3
4
5
6
ACTION COMMENTS
Create & Save New Project
Set Project Tempo
Load Samples to microSD Card
Sample Audio into Tracker Mini
Select Audio Sample for Project
Create Instruments
The microSD card must be installed to start a new
project and use Tracker Mini. Projects are stored
on the microSD Card. Create a new project.
Project Tempo 40-800 BPM. FX can apply
variations as the patterns develop.
Option to manually load uncompressed 44.1KHz,
16bit WAV samples to the microSD card from PC
or Mac and accessible to Tracker Mini projects.
Also audio can be recorded as monophonic files
and stored in the audio pool.
Samples can be stored on the microSD card and
then loaded into the project audio pool. Up to 48
instruments can be created in a project.
Instruments are created using a sample as the
source. Editing of parameters are applied.
Example instruments include WTFM, VAP, ACD,
FAT, PERC Synths plus a wavetable or granular
synth or a sample of sliced beats.
Pattern
Steps are assembled to create
beats and melodies in a
number of patterns.
Song
Patterns arranged into a song.
7
8
9
10
Create Pattern
An empty pattern can be created by setting the
tracks, length etc. A project can holds up to 255
patterns. Multiple patterns can be created.
Add Steps and Develop Pattern
An empty pattern is populated with steps. A step
contains a note, instrument and has 2 FX slots.
Assemble steps by track into beats, bass-lines,
leads, pads etc.
Arrange Patterns into a Song
Add Master Effects
A song is the arrangement of patterns into a
single track. This is the arrangement of a
complete song where patterns are played in a
defined order.
Master & Mix
Master effects can be adjusted
as can a mix of all tracks to
finalise the complete song
production.
While effects can be added to instruments, a
master effect section handles the combined
audio at the output stage. Effects include a
limiter, space, bass boost and EQ
11
12
Mix the Tracks
Mix and balance the tracks.
Perform
Performance settings can be
applied, ideal for a live set.
Configure Performance Options
Perform mode allows configuration and live
performances with defined control over specific
elements. Adds variety and improvised creativity.
Output
The project can be saved (is in
fact auto saved) and audio
rendered if required by bouncing
to audio stems.
13
Render Audio Out
Render out audio stems to mix and master further
in DAWs or to share with others maybe to create
remixes.
14
15
E
Save Project
Although projects are auto-saved, it is always
good practice to manually save a finished
production. Maybe rename with ‘Save As’.
Housekeeping
Yeah yeah…. The boring bit. But it will help as
projects develop to keep things tidy. Maybe delete
old projects or backup the microSD card.
Polyend Tracker Mini Manual
25
1
Overview
1.12 Quick Reference Commands
Assumes default assignment of function buttons [1] to [4]. D-Pad navigation referenced in rounded () parenthesis. Dynamic screen keys in italic.
Function Action Master Master Volume Tracker Mini Buttons Hold [Shift] + [+] or [-] General General Navigation (Up), (Down), (Right), (Left) General Copy [Copy] General Delete [Delete] Pattern Pattern Mode Page [1] Pattern Play Pattern [Play] Pattern Continue or Loop [Shift] + [Play] Pattern 8 Track Note View [1] + [Note] Pattern 8 Track Inst View [1] + [Instrument] Pattern 8 Track FX View [1] + [FX1] or [FX2] Pattern 4 Track View [1] Pattern Note input mode [Shift] + [Note] Pattern Pattern Pattern Pattern Pattern Pattern Select Pattern Sequential change Sequential change Immediate change Immediate change Multiple Step Select [1] + (Up), (Down) or [+] / [-] [1] + (Left) or (Right) [Pattern] + (Left) or (Right) [1] + (Up) (Down) or [+] / [-] [Pattern] + (Up) (Down) or [+] / [-] [Shift] + (Up) (Down) (Left) (Right) Pattern Select Top Row [Shift] + [Insert] Description
Adjusts the master output. The +/- offer fine and course
adjustment options. Also use (Up) or (Down).
D-Pad, generally navigate, scroll menu selections and options.
Depending on the context, will copy and paste between
functions ie copy patterns. Use [Shift] + [Copy] to paste.
Depending on the context, will delete. Will reset any selected
parameter to its default state. Also use with shift to backspace.
Selects the pattern mode page. Button 1 is by default assigned
to pattern page in the configurable page settings.
Plays the pattern from the start. Stops or pauses the pattern if
it is already playing. Restarts play if paused mid pattern.
Restarts play of the pattern from the currently paused position.
If a group of steps are selected, plays the loop.
Display all 8 tracks with only notes instead of default 4 tracks.
2 elements can be displayed i.e. + [FX1], [FX2], [Instrument].
Display 8 tracks with only instrument instead of 4 tracks.
2 elements can be displayed i.e. + [FX1], [FX2], [Note].
Display all 8 tracks with only FX instead of default 4 tracks.
2 elements can be displayed i.e. + [Note], [Instrument].
Restores default 4 tracks when viewing 8 tracks.
Sets note mode and lays screen keys out with individual notes.
Hold [Note] + D-Pad to change the set of notes assigned.
Select pattern by number.
When playing, selects a new pattern to cue playback to start
when the current pattern ends. Pattern blinks red.
When playing, selects a new pattern to cue playback to start
when the current pattern ends. Pattern blinks red.
When playing, selects a new pattern to trigger and starts
playback in sync, immediately.
When playing, selects a new pattern to trigger a start
playback, in sync, immediately.
Will select a range of multiple steps for editing collectively or to
playback on loop.
When stopped, resets the playhead to the top row start.
Pattern Multiple Step Select [Shift] + (Up) When on the first step Will select all steps for the currently selected track.
Pattern Pattern Pattern Pattern Multiple Step Select Mute Tracks Parameter Selection Arm / Disarm [Shift] + (Up) (Up) When on the first step [Shift] + [Screen] Button Tap Dedicated Param Button [Shift] + [Rec] + [Screen] Button Will select all steps for all of the tracks.
Screen button 1 - 8 will toggle mute or unmute for tracks 1 - 8
respectively when in pattern mode page.
Will lock the selection of the note, instrument, FX1 or FX2
parameter when editing or navigating.
Arms or disarms the track for recording. Disarmed tracks will
not allow recording. Screen buttons represent tracks.
26 Polyend Tracker Mini Manual
Overview1
Tracker Mini Buttons 1.12 Quick Reference Commands
Assumes default assignment of function buttons [1] to [4]. D-Pad navigation referenced in rounded () parenthesis. Dynamic screen keys in italic.
Function Action Description
Pattern Live Rec Start [Rec] + [Play] Pattern Live Rec > Play [Rec] Start Live Recording. Requires an external keyboard to record
notes into the pattern.
When live recording, pressing [Rec] will continue to play but
exit recording mode.
Song Mode Song Press [Shift] + [1] Pressing [Song] switches to song page.
Song Mode Song Hold [Shift] + [1] long press Holding buttons will temporarily display song page from within
another page i.e. from Pattern page. Release [1] before [Shift].
Song Mode Select Row Press (Up) (Down) or [+] / [-] Navigate the song row slot / pattern. One row can be selected.
Song Mode Select Top Row [Shift] + [Insert] When stopped, resets playhead to the top row start.
Song Mode Play Song [Play] Plays the song from the start of the selected slot / pattern row.
Song Mode Stop Song [Play] Song Mode Loop Row [Shift] + [Play] Stops or pauses the song playback. Pressing play again will
restart in the song at the start of the current slot / pattern row.
Loops playback on the current song slow / pattern row.
Essentially plays the selected pattern.
Song Mode Tempo Hold [Tempo] + (Up) (Down) Adjust project tempo, 40 - 800 BPM in 1 BPM increments.
Song Mode Tempo Hold [Tempo] + [+] / [-] Adjust project tempo, 40 - 800 BPM in 10 BPM increments
when using outer +/- and 1 BPM increments with inner +/-.
Perform Perform Use Menu to select perform
Perform Play [Play] Plays current pattern on loop. Also stops playback.
Perform Play [Shift] + [Play] Plays the song on loop. Also toggles pattern / song playback.
Perform Edit [Rec] Edit mode selected. Navigation and slot values in red.
Perform Navigate Column (Left) or (Right) Selects one of the 12 effect slot columns.
Perform Select [Track x] Selects tracks to apply any triggered effect. Track labelled red.
Perform Trigger effect [+], [+], [-], [-] Triggers, while held, one of the effect value slots in perform,
green mode. In Rec mode this will allow editing of the values.
Perform In Rec Mode (Up), (Down) Change performance effect in the current slot.
Perform In Rec Mode [Shift] + (Left) or (Right) Swap effects between slots.
Perform In Rec Mode [+] / [-] + (Up) or (Down) Edit the effect value offset for the respective effect and row.
Perform Remix [Track x] + (Up) (Down) or [+] / [-] Perform Remix [Track x] + (Left) or (Right) Load a new pattern for the selected track(s). Plays
immediately. Live remix mode.
Arm a new pattern for the selected track(s) once the current
pattern completes. Live remix mode.
Perform Mute / Unmute [Shift] + [Track x] Mute or unmute the selected track.
Polyend Tracker Mini Manual
27
NOTES
28 Polyend Tracker Mini Manual
2
Architecture
Make no mistake, Tracker Mini is a unique yet
comprehensive device. There are so many
features that are less obvious to producers
more familiar with more traditional sequencers
and DAWs. The overall structure of Tracker
Mini can seem at first glance, confusing.
However spending a little time to understand
the overall architecture and its terminology will
set a good starting foundation. For this reason
there are no apologies for taking time to get
intimate with the architecture of the overall
device and bringing this summary upfront in
this guide. Getting a solid understanding and
awareness of the Tracker Mini’s structure will
help enormously in getting to grips later with
the rest of the device. The two basic elements
needed is Tracker Mini itself (of course) fully
charged and the correctly configured microSD
card which is integral to Tracker Mini’s
operation. While more in depth details for
specific topics are covered in the following
sections of this notebook, the overall foundation
and structure is laid out in this chapter. The
hierarchical structure and organisation of data
and functions such as projects, patterns and
steps are summarised collectively and how they
work together. It is therefore worth the
investment of time and focus in understanding
the architectural hierarchy. Developing a
fundamental workflow and efficient process will
help get the most out of Tracker Mini’s features.
Polyend Tracker Mini Manual
29
2
Architecture
2.1 Glossary of Terms
While you may think this should be hidden at the back of this book, understanding the terminology
associated with these topics and especially the Tracker Mini will help unlock it’s power and
performance. It makes sense to become familiar early with the essential terms to help embed into
your workflow
Beta: Pre-release software versions used for
testing purposes. Polyend often release beta
versions of Tracker Mini.
Effects: Refers to the master effects used across
the overall output audio.
Envelope: An envelope is used to modulate and
shape parameters and audio over time. Tracker
Mini has envelopes which can be assigned.
FX: A number of assignable effects are provided to
steps in the pattern. These are not traditional style
effects but more like mini-applications and
automation controls.
Instrument: In Tracker Mini, an instrument starts
with a sample as its source. Various parameter
configurations can be applied including wavetable
or granular synth applications to operate as the
sound within a step. MIDI instruments to set
channel and settings also can be configured.
Instrument List: Also called an instrument pool or
audio pool. This is the internal memory. Samples
and instruments are loaded here to be accessed
by patterns.
LFO: Low frequency oscillator which is not
specifically used for sound generation but to
modulate parameters for sound design and
movement. Tracker Mini has LFO’s which can be
assigned.
Looping: The process of replaying audio or a
pattern continuously in a defined cycle e.g. start to
end then start to end.
microSD card: A storage device that is used in
Tracker Mini for holding data, samples, project etc.
Tracker Mini is supplied with a 16GB microSD.
MIDI: MIDI stands for Musical Instrument Digital
Interface and is a standard protocol used for
communicating between equipment. MIDI is
normally applied using 5 Pin MIDI DIN connections
which in some cases (i.e. with Tracker Mini) are
interfaced via a MIDI 5 Pin to 3.5mm MIDI dongle.
Mod File. Legacy tracker files such as .mod and .it
were used in classic trackers. Not compatible with
current Polyend Tracker OS versions.
Mute: Muting offers variations that can be created
by silencing the play out of tracks and patterns for
sound design purposes and especially when
playing live sets.
Note: A musical note assigned to a samples pitch
and assigned to track steps to create a melody or
percussive beat.
OS: Operating system is the core software that
makes Tracker Mini work. It handles how it
operates and periodic updates from Polyend bring
new features into use.
Parameter: The individual value of a specific
function or control element. A parameter can be
adjusted to affect a sound or a functions operation.
Pattern: This is the backbone and core of a
Tracker Mini sequence and contains all steps in a
sequence. Patterns control how steps are played.
Perform: A mode in Tracker Mini that provides an
environment with 12 selectable effects which can
be triggered live and during improvisations.
Power Bank. A portable rechargeable battery
devices used to power or recharge portable
equipment.
Project: The overall structural container for
patterns, samples, instruments etc. A project
should always be loaded to work with Tracker Mini.
30 Polyend Tracker Mini Manual
Architecture2
RAM Memory: While Tracker Mini operates with
the microSD card, on board RAM memory is also
used for instruments and samples in the project.
Render: This is like internal sampling. To internally
capture patterns, tracks or songs into an
exportable audio sample. Sometimes render is
also called ‘bounce’ in the producer community.
Reset: The process of restarting Tracker Mini by
loading a random OS firmware.
Sample: The basic audio element recorded or
loaded into Tracker Mini and used to create an
instrument.
Sampling: The act (and art) of recording and
capturing audio to be edited and creatively
assembled into a new musical composition.
Synth. A synthesizer is an electronic instrument. In
Tracker Mini there are a set of dedicated synth
engines used as a sound source. Also some
additional synth instruments such as the wavetable
synth can be created from samples.
Solo: The ability to select an individual track to play
alone and effectively mutes other tracks.
Song: A combination of tracks and patterns
combined and structured into a full arrangement.
Step: In Tracker Mini a step is the building block for
creating melodies and beats. Each step contains a
note, instrument and 2 FX slots per track and is
displayed in the track rows.
Track: Tracker Mini contains 8 tracks each which
controls a voice. Tracks are used for structuring the
sequencing of steps. These can be configured with
steps to play a variety of instruments and develop
a complete melody and beat across the 8 tracks.
Tracker: Tracker is a digital audio workstation for
music production. Trackers use a linear top to
bottom sequencing environment where elements
are programmed into lines of Tracker code.
Update: The process of installing the newest
firmware. This brings new features and fixes bugs
associated with previous versions.
USB Host: A device that initiates, manages and
controls communications across the USB network.
For example a PC/Mac would act as a host for say
USB MIDI interfacing.
USB Device: A USB device responds to any
communication initiated by a host. A device can
communicate for example with USB MIDI but may
need to be managed from a host.
Polyend Tracker Mini Manual
31
2
Architecture
2.2 Tracker Mini Audio Structure
microSD Card
Firmware Instruments Mod TrackerLog
A correctly formatted microSD card must be installed
to operate Tracker Mini. Card default folders shown.
Games Manual Projects Samples
Tracker Mini
Project
Project
100 Projects are visible and accessible from within Tracker Mini.
More than 100 could be stored on the microSD Card.
Project
Loaded Project
Pattern
Maximum 255 Patterns per Project
….. 16 Tracks per Project …..
Instrument Audio Engine
48 Instrument and 3 Synth slots are available per Project
Track 1
Track 16
….. Max 128 Steps per Track …..
Step
1
Note Instrument FX1 FX2
Instrument Instrument Instrument Synth 1
Synth 2
Synth 3
Macros
Mix
Step
.…. .….
Delay
Send & Return Mix & Pan
Reverb
Send & Return
Filter
Overdrive
Step
128
Bit-crusher
Wavetable Sample
Granular
FX Applications
FX
MIDI Engine &
Parameters
A variety of effects are selectable from the list of 29 FX.
E.g. G
E.g. T
E.g. m
FX
FX
Track 1
Track 16
Song
Sampler
Pattern
Saturation
Master
Mic In
Line in
Pattern
Limiter
Pattern
Space
Delay Reverb
MIDI In
Pattern
Bass Boost
MIDI Out
EQ
Pattern
Out Right
Pattern
Out Left
Extended Audio In/Out using the USB 14 Stereo Audio Channels
32 Polyend Tracker Mini Manual
NOTES
Architecture2
2.3 Structure of microSD Card
The microSD card is an integral part of Tracker Mini and must be inserted
to operate correctly. An alert message is displayed if Tracker Mini is
powered up without an microSD card installed. It is important that the
correct format is applied to the microSD Card. This should be FAT32 with
Master Boot Record (MBR) Partitioning.
The default file structure will expand as different functions are used. For
example a snapshots folder is created when capturing screen images, also
export and recording folders created once these files are firstly generated.
Files and folders can be accessed with a PC or Mac. A USB adapter is
supplied with Tracker Mini.
microSD can be connected to a
PC / Mac with the USB adapter.
Root
Polyend Tracker Mini Manual
33
2
Architecture
Default microSD card structure
microSD card
/Root Directory
Sub Folders
Polyend Tracker Mini_1.0.0.ptf
/Firmware
New OS versions can be located here to update Tracker Mini Mini
/Games
/Instruments
Contains xxx.pti instrument files in the sub-folders
/Drum Kits
/Instrument Kits
/Progressions
/Synths
/Manual
/Quick Start
1.jpg, 2.jpg, 3.jpg, 4.jpg, 5.jpg, 6.jpg, 7.jpg, 8.jpg
/Mod
Legacy .mod or .it Tracker files.
May not exist on newer microSD Cards
/Projects
Contains project files located in sub-folders
/ProjectName
/Instruments
/Samples
/Patterns
Project.mt
/Samples
Sample packs located in sub-folders
/FactoryPacks
Tracker Mini comes with 50 factory genre-based packs installed onto the
microSD card.
/TrackerLog
Lo1.ptl
NOTES
34 Polyend Tracker Mini Manual
Architecture2
NOTES
2.4 Manual Help & Tips.
Tracker Mini is supplied with a quick start guide, also available on the
microSD card.
The official complete manual and Q&A are available on the Polyend
website. Please register your device to get full support and access to help.
Polyend Tracker Mini Manual
35
2
Architecture
2.5 Menu Page Map
As a quick guide to the page hierarchy in Tracker Mini the following
diagram illustrates the main pages accessed under the [Menu] option.
+
+
-
Master Volume
-
NOTES
Pattern
Song
Perform
Instrument
Parameters
Sample
Loader
Sample
Editor
Sample
Playback
File
Sample
Recorder
Master
Config
Games
Project
[File]
[Shift] + [3]
[Export]
[Config]
Project Settings, General, MIDI,
Metronome, Firmware, Manual, Credits
[Shift] + [4]
[Sample Loader]
[Shift] + [2]
[Sample Playback]
[3]
[Sample Editor]
[Select Effect]
[Sample Recorder]
[Pattern]
[More]
[1]
The pattern page is the place where most time will be spent in the Tracker Mini workflow.
36 Polyend Tracker Mini Manual
NOTES
Architecture2
+
+
-
-
Master Volume
[Instrument MIDI Mapping]
1/2 2/2
[Instrument Parameters] [Instrument Effects]
[2]
Audio
[Song]
[Shift] + [1]
[Perform]
1/3 2/3
[Master]
[Sample Track Mixer]
[4]
3/3
[Global Mixer]
[Reverb]
[Delay]
[Limiter]
[EQ]
Default quick page button 1 - 4 assignments are also shown under the page name.
Polyend Tracker Mini Manual
37
NOTES
38 Polyend Tracker Mini Manual
Projects
Projects are the highest order structural
element in Tracker Mini. A project contains all
the elements of a full track. Think of each
project as a fully arranged song for an album
or a song for live set. Tracker Mini auto saves
projects which are stored on the installed
microSD card. Although the card itself can
contain more, Tracker Mini will have up to 100
projects visible and accessible. A project
should be opened for playback and editing.
New projects can also be created from scratch.
Each project contains a maximum of 255
patterns across 16 tracks. While patterns are
the musical composition functions, some
elements, such as the 48 available instruments
are managed at project level, and hence
accessible to all patterns. Projects are
structural and organisational functions more so
than part of the creative environment but
nevertheless serve an important purpose in
the Tracker Mini workflow. Tracker Mini has an
Polyend Tracker Mini Manual
3
extended project memory for audio samples.
This holds almost 12 minutes mono, 6 mins
stereo of mic recorded audio as standard
although this may vary depending on the audio
quality and format. Samples are stored on the
microSD card but can be also are held in the
Tracker Mini on board sample pool where
samples effectively become instruments.
Projects have an instrument pool populated with
samples or instruments to be available when
creating steps. This is prerequisite to creating
sequences. This section covers the general
project management in Tracker Mini and it’s
microSD card plus some key specific project
level functions such as tempo.
39
3
Projects
3.1 Project Overview
A project is the highest order of Tracker Mini’s functions. It allows projects
to be managed, saved and loaded and also new projects to be created.
Think of a project as container for a complete song for an album or live set.
Access to project level features exists in various parts of Tracker Mini’s
functions and does not have a dedicated single point of access.
Projects - Multiple projects with 100 visible per project folder.
More projects can be available in the microSD Card projects or user folders.
Tracks - 16 per project
Tracks are used to organise parts of a pattern such as bass, drums, etc
Patterns - 255 patterns per project
Patterns are sequenced into tracks to create musical elements.
Steps - 128 steps per pattern
These are the discrete building blocks each with a note, instrument and effects
Song - 255 Slots (slots = rows for the 16 tracks)
A song is an arrangement of patterns to create a complete production
NOTES
40 Polyend Tracker Mini Manual
NOTES
Projects3
3.2 Opening & Saving a Project
Projects are auto saved but can also be manually saved and renamed.
Loading of a saved project is also possible, although on power up the
previously active project will be restored. The project management
functions are in the [Menu] ‘File’ function or accessed by default with [Shift]
+ [3]. Note that projects copied to the microSD card must be in the main
project folder. Sub folders are not viewed directly from the ‘file’ menu.
▌ CREATING A NEW PROJECT
1. 2. 3. Hold [Shift] + [3] to open the file browser menu or access with [Menu].
Press [New Project] screen button. An option to save the current project
may be presented.
A blank project named ‘New Project’ is created.
▌ OPENING AN EXISTING PROJECT
1. 2. 3. 4. 5. 6. 7. Hold [Shift] + [3] to open the file browser menu or access with [Menu].
Press [Open], screen button. The project list is displayed. The microSD
card list is in the left window and the recently loaded projects centre.
Use (Left) or (Right) to switch between windows and lists.
Press (Up) (Down) or [+] / [-] to navigate the list of projects to load. Also
press [Up] screen button or [Down] screen button to scroll the list. The
highlighted option will show with a bounding box.
With the desired project highlighted, Press [Open] screen button.
If the currently active project has been edited a prompt ‘Do you want to
save the change to ‘xxxx’’ will be presented. Press [Save] screen button
or Press [Don’t Save] screen button to save or exit.
If the current pattern is new, a ‘Save As’ command is activated.
If required, Press [1] to display pattern page.
▌ MANUALLY SAVING THE CURRENT / EXISTING PROJECT
1. Hold [Shift] + [3] to open the file browser menu or access with [Menu].
2. Press [Save] screen button.
3. The project will be saved and overwrite the previous version.
Polyend Tracker Mini Manual
41
3
Projects
NOTES
▌ SAVING THE CURRENT PROJECT - FIRST TIME
1. Hold [Shift] + [3] to open the file browser menu or access with [Menu].
2. 3. Press [Save] screen button from left or Press [Save As] screen button
from left. If using ‘Save’ for the first time the ‘Save As’ function is
triggered to request a name.
Navigate and select a folder location and then [Save] screen button.
4. The naming function will appear to allow a new name to be created.
The D-Pad buttons will allow navigation and select within the alpha-
numeric keyboard. Project names can be a max of 32 characters.
5. Alternatively, press [Auto Name] screen button. This will generate a
random name for the project and present it in the editor.
6. With the desired name created, Press [Save] screen button.
7. The project is saved and the keyboard editor function is closed.
1
2
3
4
5
6
7
8
9
0
Backspace
q
w
e
r
t
y
u
i
o
p - +
a
s
d
f
g
h
j
k
l
@
Caps Lock
z
x
c
v
b
n
m
Space
Enter Auto Name Save
Cancel
QWERTY Keyboard is represented by the visual grid. The ‘f’ and ‘j’
keys are highlighted and lit on the pads to serve as a reference. The
screen buttons offer the main commands in the context of the editor.
The following Tracker Mini buttons also operate in the naming editor
when the naming screen is presented:-
• (Up), (Down), (Left), (Right) will navigate the selection across
the keyboard. Will navigate left / right in the text of the name
when the name is highlighted .
• [Insert] will insert the currently highlighted character into the
name at the cursor position.
• [Shift] + [Insert] to delete characters and backspace in the name
from the text cursor position.
The option to create a new folder also exists in the file menu under the ‘Open’
function. This will also require a name to be created.
42 Polyend Tracker Mini Manual
NOTES
Projects3
3.3 Deleting a Project.
The option to delete a project can be performed in the project browser. The
currently active project cannot be deleted. Change to another project to
delete. Deleting a project will also remove it from the microSD card.
▌ DELETING A PROJECT
1. 2. 3. 4. 5. 6. 7. Hold [Shift] + [3] to open the file browser menu or access with [Menu].
Press [Open] screen button from left. The list of available (max 100)
projects will be displayed on the left of the screen.
Press (Up) (Down) or [+] / [-] to navigate the list of projects to load. Also
press [Up] screen button or [Down] screen button to scroll the list. The
highlighted option will show with a bounding box.
With the desired project highlighted, press [Delete] screen button.
A prompt ‘Do you want to delete project ‘xxxx’’ ?’ will be presented.
To confirm, press [Delete] screen button to confirm deletion.
Alternatively, press [Cancel] screen button from left to exit without
deleting the project.
Project will be deleted from the microSD card and no longer visible in
the project list on Tracker Mini *.
* Projects also manually deleted externally from the microSD card using a PC or
Mac will no longer be visible in Tracker Mini.
Polyend Tracker Mini Manual
43
3
Projects
3.4 Project Tempo
The overall tempo of the project is set in the ‘Song’ section of Tracker Mini
and has a defined range of 40 - 800 BPM. Tempo can also be modulated
by using the FX slots in a step with the ‘T’ tempo effect. Note that the MIDI
clock output is based on the project tempo.
NOTES
Song 0m:00s P1.008
Track 1
Track 2
Track 3
Track 4
Track 5
Track 6
Track 7
Track 8
Midi 9
Midi 10
Midi 11
Midi 12
Midi 13
Midi 14
Midi 15
Midi 16
Pattern
1
Play
Pattern
Play
Song Undo Add
Slot
Delete
Slot Pattern Tempo
130.0 BPM
800 BPM
BPM Range
Hold [Shift] + [1] to open the ‘Song’ page.
In song mode,
Hold [Tempo] + (Up) (Down) or [+] / [-]
To adjust in larger Increments use the upper
and lower [+] and [-] buttons
40 BPM
Tempo
130.0 BPM
Tap tempo can be applied in song mode by tapping the tempo
screen key a minimum of 4 times at the BPM desired. Count
will be displayed when tapping.
Note: Pressing [Tempo] + [Delete] in the song page will reset to the default 130
BPM. This is generic behaviour, where the [Delete] button will reset any selected
parameter to it’s default value.
44 Polyend Tracker Mini Manual
NOTES
Projects3
▌ ADJUSTMENT OF THE PROJECT TEMPO
1. 2. 3. Hold [Shift] + [1] to open song mode.
Hold [Tempo] + (Up) (Down) or [+] / [-] to change the tempo in small
iterations. Range is 40 - 800 BPM.
Use the upper or lower [+] and [-] buttons for larger increments.
▌ TAP TEMPO ADJUSTMENT
1. 2. 3. Hold [Shift] + [1] to open song mode.
Tap [Tempo] - screen button, a minimum of four taps. The tap count will
be displayed during tapping.
The tempo recorded is based on the speed of the taps played.
Note that the FX option ‘T’ tempo triggers a tempo change between 10% - 400%
which can therefore extend the project base tempo range.
Polyend Tracker Mini Manual
45
3
Projects
3.5 Metronome
Tracker Mini has a metronome which operates when live recording (not
normal playback). This is configurable and selectable on/off within the
‘Config’ menu under the ‘Metronome’ options.
NOTES
Press [Shift] + [4] or navigate in the [Menu] for the ‘Config’ page
Config 0m:00s P1.008
Project Settings General MIDI
USB
Metronome
Firmware
Fn buttons binding
Info
State Off
Pre roll Off
Time signature num 4
Time signature denum 4
Volume 50
Metronome Pre roll
Enter
Press (Left) or (Right) to navigate between the option windows
and use (Up) or (Down) to navigate to the desired option. Also
the screen buttons can be used to navigate.
Metronome Settings.
Option State On, Off
Default Off Pre Roll On, Off
Default Off
Time signature num 1 - 12
Default 4
Time signature denum 1 - 12
Default 4
Volume 1 - 100
Default 50 Parameters Description
Toggles the metronome on or off.
Sets a count in before the sequencer starts to
help timing of punch in recording.
Ideal for live recording.
Number of beats in a measure / bar. Upper
number in the normal time signature value.
Example 4/4 set to 4 beats per measure.
Beat value, division of note. Lower number in
the normal time signature value. Example 4/4
has a quarter note per beat.
Volume of the metronome’s ‘tick’ sound.
Metronome will also be sent to the USB Audio master output channel.
46 Polyend Tracker Mini Manual
NOTES
Projects3
▌ SETTING THE METRONOME
1. 2. 3. 4. 5. 6. 7. 8. Hold [Shift] + [4] to open the ‘Config’ Page. Also access in the [Menu].
Ensure the left window is highlighted red i.e. in focus. Navigate windows
by pressing (Left) or (Right). Menu windows will automatically be
selected when pressing the relevant screen keys below the window to
navigate [Up] or [Down].
Press (Up) or (Down) to highlight with the bounding box over the
‘Metronome’ option. Alternatively press the relevant screen keys below
the window to navigate [Up] or [Down].
Press the relevant screen keys below the window to navigate [Up] or
[Down] under the central options to highlight with the bounding box over
the required Metronome option.
To change the selected parameter / setting, Press [Enter] screen button.
The parameter pop-up window listing the available options will appear.
Press (Up) (Down) or [Up] [Down] screen buttons to highlight the
desired option.
Press [Apply] screen button to confirm selection or [Cancel] screen
button to exit without changing.
The metronome will operate at the chosen time signature and volume
when live recording is activated using [Rec] + [Play]. The pre roll will
provide a count in of 4 and show the ‘Recording in 4. 3. 2. 1.’ message
before starting to record.
Polyend Tracker Mini Manual
47
3
Projects
3.6 Project Pool & Instrument List
NOTES
A pre-requisite for creating patterns is to have a series of instruments
available to record or program into steps. Instruments are based on the
samples loaded into the project pool and parameters applied to create
instruments. Instruments can also be loaded from other projects but must
exist in the current project instrument list to be accessible to the pattern
steps. A maximum of 48 instruments are available per project depending on
the sample size and hence memory usage.
An instrument or sample from the microSD card libraries can be added into
the active project instrument list. The instrument list is used to configure
steps.
Basics of setting up a project instrument list using the sample loader
function, accessed by default with [Shift] + [2] is shown here and further
details on the sample management is detailed later.
Press [Shift] + [2] or navigate in the [Menu] for the ‘Sample Loader’ page
Press (Left) or (Right) to navigate between the option windows a
red bounding box will indicate the selected window. Press (Up) or
(Down) to navigate to the desired listed option.
Sample Loader 0m:00s P1.008
SD Card /Firmware /Games
/Instruments
/Manual
/Mod
/Projects
/Samples
/trackerLog
Instruments
1. Strange Sample Number 1
2. Deep Kick
3. Transient Kick
4. Snare One
5. Closed Hat 1
6.
7.
8.
9.
10.
11.
12.
13.
Enter Rename Delete
Add Next Preview
Import
Unused
Preview Vol
0.00 dB
Memory
17%
Window display shows microSD card
and instrument list. Max 48 instruments
can be stored in a Tracker Mini project.
Project memory available based on the
selected samples / instruments in the
instrument list.
The bar will show an additional red
element - if memory will increase and
green bar - if memory will decrease
when browsing a sample / instrument
indicating potential memory impact if
sample / instrument is added.
Samples can be imported directly to the project and edited for use. Sample
import mode can import stereo samples.
48 Polyend Tracker Mini Manual
NOTES
Projects3
▌ CREATING A PROJECT INSTRUMENT LIST
1. 2. 3. 4. 5. 6. Hold [Shift] + [2] to open the ‘Sample Loader’ Page. This is also
accessible within the [Menu].
Navigate to the central ‘Instruments’ window and highlight either an
empty slot or an existing instrument. If an existing instrument is
highlighted it will be replaced by the newly selected choice.
Navigate to the left ‘SD Card’ window and highlight either instruments or
samples. Use the (Up) or (Down) to navigate and press [Enter] screen
button to select and open the folder and any sub folders. Where
samples are selected, hold [Shift] + (Up) (Down) D-Pad navigator to
batch select multiple samples / instruments.
With a sample or instrument highlighted in the left window, press the
[Add] screen button. This will add or replace in the selected instrument
slot. Using [Add Next] screen button will add a sample and will
automatically jump the cursor to the next slot.
The memory bar chart will indicate the available project memory in
Tracker Mini. This will depend on the type and size of samples selected
and may limit the amount of instruments available in the instrument list.
Additional samples / instruments can be added. The instruments in the
list will be available to add to a step.
Notes:
• A prompt will be offered if replacing an existing instrument.
• When navigating, the /.. symbol indicates folders and subfolder
with a name. Selecting /.. alone will navigate up a level of the
microSD card folder structure.
• Instruments have a .pti filename.
• Samples can be previewed in stereo from the microSD card and
the preview volume can be adjusted. The sample loader preview
audio and metronome are also sent to the USB master output.
• The memory bar will show an additional red band (increases
memory usage) or green band (decreases memory usage)
indicating the potential memory impact when highlighting a sample
/ instrument to add. Should this be added to the instrument pool it
will affect the memory usage as indicated by the red/green bar.
Polyend Tracker Mini Manual
49
3
Projects
▌ DELETING AN INSTRUMENT FROM THE LIST
1. Hold [Shift] + [2] to open the ‘Sample Loader’ Page. This is also
accessible within the [Menu].
2. Navigate to the central ‘Instruments’ window and highlight an existing
instrument. If an existing instrument is highlighted it will be the one
deleted in this process. Use [Shift] + (Up) (Down) D-Pad navigator to
batch select multiple samples / instruments.
3. Press [Delete].
4. A prompt asking if you want to continue on to delete the highlighted
sample / instrument. Press [No] screen button to cancel without deleting
or confirm deletion by pressing [Yes] screen button.
5. The instrument is removed from the Tracker Mini list but is still present
on the microSD card.
6. The memory bar chart will indicate the available project memory in
Tracker Mini. This will depend on the type and size of samples selected
and may limit the amount of instruments available in the instrument list.
7. Additional samples / instruments can be deleted. The instruments in the
list will be available to use in the project.
▌ DELETING ALL UNUSED INSTRUMENTS FROM THE LIST
1. 2. 3. 4. 5. 6. Hold [Shift] + [2] to open the ‘Sample Loader’ Page. This is also
accessible within the [Menu].
Navigate to the central ‘Instruments’ window.
Press [Delete Unused] screen button.
A prompt asking if you want to continue on to delete the highlighted
sample / instrument. Press [No] screen button to cancel without deleting
or confirm deletion by pressing [Yes] screen button.
Any instruments that are in the list but not used in the project are
removed from the list. microSD card files remain intact.
The memory bar chart will indicate the available project memory in
Tracker Mini. This will depend on the type and size of samples selected
and may limit the amount of instruments available in the instrument list.
NOTES
50 Polyend Tracker Mini Manual
NOTES
Projects3
▌ IMPORTING A SAMPLE TO THE PROJECT INSTRUMENT LIST
1. 2. 3. 4. 5. 6. 7. Hold [Shift] + [2] to open the ‘Sample Loader’ Page. This is also
accessible within the [Menu].
Navigate to the left ‘SD Card’ window and navigate to and highlight a
sample to import. Use (Up) or (Down) to navigate and Press [Enter]
screen button to select folder.
Navigate to the central ‘Instruments’ window and highlight either an
empty slot or an existing instrument. If an existing instrument is
highlighted it will be replaced by the newly selected choice.
Press [Import] screen button. The sample is displayed for editing.
Pressing [Cancel] screen button at any time to leave the import menu
without importing.
The sample can have its start,[Start] screen button and end, [End]
screen button adjusted. Select start or end and use [+] and [-] to adjust.
The inner [+] and [-] buttons adjust with a higher resolution. This is a
great feature when samples are too long or only a portion is needed.
Hold [Preview] screen button to listen to the sample.
When editing is complete, select an import option to load the sample
into the instrument list:-
• Press [Import Low Quality] screen button. This will import a lower
quality sample. This will create a smaller file size and save memory.
The trade off is audio sound quality reduction.
• Press [Import Normal] screen button. This will import a sample at
the normal Tracker Mini quality specification. This will create a larger
file size and take up more memory. The trade off is optimum audio
sound quality.
Instruments can also be copied and pasted within the sample loader and
instrument list browser to duplicate and instrument. Use the [Copy] dedicated
button to copy and [Shift] + [Copy] to paste.
Polyend Tracker Mini Manual
51
3
Projects
3.7 Summary of Configuration Options
NOTES
A number of options can be set in the ‘Config’ menu. These defaults may
be good enough to get started but specific changes may suit certain
workflows and situations better. The details of these will be covered in
relevant sections and only an overview of global settings is provided here.
Press [Shift] + [4] or navigate in the [Menu] for the ‘Config’ page
Config
Config 0m:00s P1.008
Project Settings General
MIDI
USB
Metronome
Firmware
Fn buttons binding
Info
Performance presets Global
Pattern divider 4
Anti-aliasing On
Limiter Mode
Subtle
Sends Mode Post-Fader
Extra Headroom
On
snap to zero
On
Project Settings Limiter mode
Enter
Press (Left) or (Right) to navigate between the option windows a
red bounding box will indicate the selected window. Press (Up) or
(Down) to navigate to the desired listed option.
Also the [Up] and [Down] screen buttons will select the option and
automatically select the menu window.
52 Polyend Tracker Mini Manual
Config Options
Option Menu Project Settings Performance Presets Project Settings Pattern Divider Project Settings Anti-aliasing Project Settings Limiter Mode Project Settings Sends Mode Project Settings Extra Headroom Project Settings Snap to Zero General Display Brightness General Display Theme
General Display Font General Recording Options General Numbering Mode General Pattern Arrangement General Pattern Top Info General Line In Channel Polyend Tracker Mini Manual
Projects3
Book Section
Description Allows performance presets to be saved either as
a global configuration or local to each project.
Performance
Mode
Sets the highlight level for the selected step
offering better pattern visualisation. Pattern Format
Anti-aliasing set to ‘On’ gives a cleaner sound for
sample playback. Off is more lo-fi vintage feel.
Sets the characteristics of the limiter attack and
release between subtle and extreme. Master Effects
Sets the sends to pre-fader i.e. independent of
volume or post-fader. Master Effects
Avoid clipping by adding extra headroom in the
output audio.
Snap audio crossings to zero points, Used as
green markers in the sample playback page. Instruments
Adjusts the brightness level of the 5” display
between three settings: High, Medium, Low. System
The colour scheme of the screen. Original has the
dark background while monochrome is bright. Also
includes the 10th anniversary edition.
System
Text font option. Original has the classic consolas
look while ‘new’ is smaller, more standard. System
Sets the options for what is recorded i.e. notes,
quantization, micro-timing, velocity.
Sequencing
Steps
Sets all numbers to the decimal starting at 0 or 1
or hexadecimal format. Classic look and feel. System
Sets the pattern display to the traditional and
revolving vertical view or horizontal display. Patterns
Allows the top part of the pattern screen to display
only the track name, additional info or off. Patterns
Selects the audio input of the line in between
stereo, mono left or mono right. Audio
53
3
Projects
Menu MIDI MIDI MIDI MIDI MIDI MIDI MIDI MIDI MIDI MIDI MIDI Option Clock In Clock Out Transport In Transport Out Notes In Notes In Channel MIDI Out CC In CC In channel Middle C Description Sets the source of the master clock, Internal
(default) or external USB or MIDI In jack. Sets the Tracker Mini clock output. Off, USB, MIDI
Out jack, USB + MIDI Out jack. Sets the source of transport control commands,
Internal (default) or external USB or MIDI In jack. Sets the output of transport control commands, Off,
USB, MIDI Out jack or USB+MIDI jack options. Sets the input routing of external notes in. Set to Off,
USB, MIDI In jack or USB+MIDI jack options. Sets the MIDI channel for incoming notes from
external gear. Select All channels or Ch 1-16. Sets the MIDI output routing between, Off, USB,
MIDI Out jack or USB+MIDI jack options. Sets CC (control change) input routing to Off, USB,
MIDI In jack, USB+MIDI In jack. Sets MIDI channel for CC (control change) incoming
messages. Select All channels or Ch 1-16. Sets middle C as C-3, C-4, C-5, C-6. Calibrates
range in Tracker Mini with external gear. Clock Sync Correction Latency compensation for incoming sync. -6 to +6.
Use with MIDI Jack or USB clock in. USB Storage
A USB connected PC / Mac will see the Tracker Mini
microSD card as an external storage drive. Files can
be then be transferred directly to / from the installed
microSD when in this mode.
USB Audio Enables USB audio In, Out or both. Can also
disable the USB audio by setting to off. MIDI
MIDI
MIDI
MIDI
MIDI
MIDI
MIDI
MIDI
MIDI
MIDI
MIDI
System
Audio
Metronome State Turns the metronome on or off for live recording. Projects
Book Section
Metronome Pre Roll Provides a count in of 4 before starting to record. Projects
Metronome Time signature num Upper numerator of the time signature. Projects
54 Polyend Tracker Mini Manual
Projects3
Option Menu Description Book Section
Metronome Time signature
denum Lower denominator of the time signature. Project
Metronome Volume Volume level of metronome. Projects
Firmware Firmware Update Activates a firmware update based on the OS
located on the microSD card in the ‘firmware’ folder. System
Firmware Current version Displays current version of installed OS. Visual
indicator only. System
Firmware Build Firmware build version display.
Firmware Reset config Resets this configuration menu to the default
original settings. System
Fn buttons binding Fn1 Sets the page associated with function button [1]. System
Fn buttons binding Fn2 Sets the page associated with function button [2]. System
Fn buttons binding Fn3 Sets the page associated with function button [3]. System
Fn buttons binding Fn4 Sets the page associated with function button [4]. System
Fn buttons binding Fn1+Shift Sets the page associated with function button
combo [Shift] + [1]. System
Fn buttons binding Fn2+Shift Sets the page associated with function button
combo [Shift] + [2]. System
Fn buttons binding Fn3+Shift Sets the page associated with function button
combo [Shift] + [3]. System
Fn buttons binding Fn4+Shift Sets the page associated with function button
combo [Shift] + [4]. System
Info - - General information and license details.
Polyend Tracker Mini Manual
55
NOTES
56 Polyend Tracker Mini Manual
4
Pattern Format
Each project contains a maximum of 255
patterns across 16 tracks. Each pattern can
hold up to 128 steps per track. Patterns are at
the heart of Tracker Mini and are built in the
pattern sequencer. The sequencer is what
makes Tracker Mini different from normal
digital audio workstations. Steps are the
building blocks when creating patterns and by
assembling these into audio arrangements it is
possible to create beats and melodies. Each
step consists of a note, instrument and two FX
slots. These are triggered as each row is
activated when playback is initiated. This can
trigger audio information, effect actions or MIDI
messages. Patterns are bite size elements of
a full song and can be created as individual
modules built using steps. Patterns are then
combined and arranged together in song mode
for chaining into a full length track. This section
will focus on patterns using in audio tracks
(although MIDI steps can be created together
with audio). This section will provide overall
guidance on creating basic patterns as well as
their structural elements generally. This is a
foundation to patterns and a deeper dive into
steps and sequencing comes next. All the basic
building blocks and the process needed to get
started in creating, editing and using a basic
pattern are covered in this section. More
advanced and in-depth elements of the
components of a step are covered later as well
as more advanced sequencing functions.
Polyend Tracker Mini Manual
57
4
Pattern Format
4.1 What’s a Pattern?
Patterns are a combination of 16 tracks where each has a series of steps
mapped out. The steps form into a melody or beat. So for example track 1
could be the drums, track 2 for percussion, track 3 as bass etc. Patterns
can be created using steps manually ‘programmed’ into the Tracker Mini or
by recording in real time.
Project
Up to 255 Patterns per Project.
Pattern 3
Pattern 2
Pattern 1
Track 1 Track 2 Track 3 Track 4
Track 5 Track 6
Track 7
Track 8
etc
Step 1
Step 2
Step 3
Step 4
Step 5
A default of 32 steps pre track is available in new patterns.
This can be changed between 1 - 128 Maximum.
Play Direction
Step
Step 124
Step 125
C4 01 P 27
Note
Instrument FX1 FX2
Step 126
Track 2, Step 126
Step 127
Step 128
Patterns will be stored on the microSD card under the project folder.
Projects
MyProj
Patterns
Pattern_01.mtp
Pattern_02.mtp
Samples
Pattern_03.mtp
Instruments
project.mt
NOTES
58 Polyend Tracker Mini Manual
NOTES
Pattern Format 4
4.2 Process of Creating a Pattern
Formatting and creating a pattern is a simple process but there are some
good practices that will speed up workflow and help to move quickly to
making music. A pattern is the container for steps and establishes the step
timing and track format. The dynamic screen buttons are used heavily.
S
Pre-Requisite Select Pattern Mode Page
Tempo and project
Instruments list is populated.
Press [1]
Pattern editing is mainly
performed in pattern mode.
Length
Hold [Length] + (Up) or (Down).
(Left) & (Right) for larger increments.
Example, length = 32
Select Pattern Number
Hold [Pattern] + (Up) or (Down)
Example, pattern = 1
Shrink Duplicate
Expand
Press [Shrink]
Screen button
halves length by removing
every second step
Press [Expand]
Screen button
doubles length by
inserting steps
Press [Duplicate]
Screen button
doubles pattern length
including steps
Add Steps
Manual or live recording
to record steps into the
pattern.
Display Options
E
Optionally set screen view, track
number, vertical / horizontal etc.
Polyend Tracker Mini Manual
59
4
Pattern Format
4.3 Configuring a Pattern.
Pattern and step editing is performed in ‘Pattern’ mode. The first
requirement is to create the pattern itself where steps can later be added to
create the melody or beat. Commands for the pattern are available from the
dynamic screen buttons located at the bottom of the page. These will
change depending on the mode or selection made.
The 15 dynamic screen buttons labelled at the bottom of the page will control options for creating patterns.
Underscore colour represents mode i.e. Red means accessible in [Rec] mode only.
-- --- ---- ---- -- --- ---- ---- -- --- ---- ---- -- --- ---- ----
15
Pattern
1
Length
32
Step Jump
0 Fill Preview Undo Redo More
i - Random Instrument
Paste
More
Pattern
More
Render
Selection
Invert Duplicate
Pattern
Expand
Pattern
Shrink
Pattern
Copy
Pattern
14.
Pattern
Name
Track
Name
Function Menu Option Pattern Pattern Selection Length Pattern Length Step Jump Programming Aid Fill Programming Aid Preview Instrument Preview Undo Undo Last
Command
Redo Redo Last
Command
Render
Selection Bounce Audio Invert Invert Steps Duplicate
Pattern Expand
Pattern Shrink
Pattern Copy
Pattern Paste
Pattern Name Pattern
Track Name Extends Pattern Extends Pattern Contracts Pattern Copy Paste Name the Pattern Name the Track Description
Selects a pattern to edit. This will select a pattern number
between 1-255 in the project.
Adjust the number of step rows in the pattern. Default is
32 but a maximum of 128 rows are available in a pattern.
Assists in recording steps with the pads. Will
automatically jump the selection cursor in defined steps.
Assists in programming steps. Will automatically fill steps
based on defined selection criteria.
Will play the instrument for the step to allow previewing of
the sound.
If available, will reset the previous state prior to the last
action, effectively undoing the last (up to 20) commands.
If available, will restore the previous state after to the last
action, effectively redoing the last (up to 20) commands.
Renders the selection to a new audio sample. Useful to
use elsewhere or to reduce track consumption.
Inverts all steps in the selection vertically.
Extends the entire pattern and its associated steps,
extending the pattern to double the length.
Extends the pattern by adding blank steps in between
existing steps, extending the pattern to double the length.
Contracts the pattern length by deleting every 2nd step,
reducing the pattern to half the length.
Copies the entire pattern to the virtual clipboard.
Pastes the copied pattern from the virtual clipboard into
the location starting at the current position.
Opens the alpha-numeric keyboard to change the current
pattern name.
Opens the alpha-numeric keyboard to change the current
track name.
More Change Page Selects the next page of commands
NOTES
60 Polyend Tracker Mini Manual
NOTES
Pattern Format 4
▌ SELECTING THE PATTERN MODE PAGE
1. 2. 3. Press [1] to open the ‘Pattern’ page. Also accessible within the [Menu].
The options for the pattern page will show at the bottom of the page and
are represented by the 8 screen buttons.
To change the options page, press [More] screen button. This toggles
between the three pages of pattern options.
▌ SELECTING A PATTERN
1. 2. 3. 4. 5. Press [1] to open the ‘Pattern’ Page. Also accessible within the [Menu].
Ensure the pattern is not playing.
Ensure options page 1 is displayed. Press [More] to toggle between the
two pages of pattern options.
Hold [Pattern] screen button + (Up) or (Down). A pattern number
between 1-255 can be selected. Blank patterns selected have 32 steps
as default. The [+] and [-] buttons can also be used.
The currently active pattern number is displayed top left in the info bar.
▌ ADJUSTING THE PATTERN LENGTH
1. 2. 3. Press [1] to open the ‘Pattern’ page. Also accessible within the [Menu].
Ensure options page 1 is displayed. Press [More] to toggle between the
three pages of pattern options.
Hold [Length] screen button + (Up) or (Down). A pattern length between
1-128 steps can be selected. Default is 32. The arrow buttons (Left) or
(Right) will set length in predefined denominations i.e. 1, 2, 4, 8, 16 etc.
Tip: It is good practice to build patterns starting with a small length. For example
start with 8 or 16 steps and create the beat or melody. This can then be duplicated
/ extended along with its steps and then edited to create longer passages.
Polyend Tracker Mini Manual
61
4
Pattern Format
NOTES
▌ EXTENDING PATTERN LENGTH
1. 2. 3. 4. 5. Press [1] to open the ‘Pattern’ page. Also accessible within the [Menu].
Press [More] to toggle between the three pages of pattern options.
Press [Rec] to select recording mode and allow editing. Screen buttons
will be unavailable, shown dim, otherwise.
The current pattern can be extended in severals ways. The options
available via the 8 screen buttons are:-
• Press [Duplicate Pattern]. The pattern will be extended by
duplicating the full pattern along with its steps. Effectively doubles
the pattern length. Option is on pattern page 2.
• Press [Expand Pattern]. The pattern will be extended by inserting
additional step rows in-between existing steps. Effectively doubles
by stretching the pattern length. Option is on pattern page 2.
• Adjusting [Length] will also increase the pattern length. New empty
step rows added at the end. Option is on pattern page 1.
The [Undo] or [Redo] screen buttons can be used if required to restore
a previous state. These are on page 1 of the page options.
Duplicate Pattern
Expand Pattern
Step 1 C5 40---- P 25 Step 1 C5 40---- P 25 C5 40---- P 25
Step 1
Step 2
Step 2 Step 2
Step 3
C5 40---- P 25 Step 3 C5 40---- P 25
Step 3
Step … Step …
Step 4
Step 32 Step 32
C5 40---- P 25
C5 40---- P 25
Step 5
+
Step 33
C5 40---- P 25
Step 6
Step 34
Step 35
C5 40---- P 25
Step …
Step …
C5 40---- P 25
Step 63
Step 64
Step 64
Double the pattern length
Blank steps added after each step
62 Polyend Tracker Mini Manual
NOTES
Pattern Format 4
▌ REDUCING PATTERN LENGTH
1. Press [1] to open the ‘Pattern’ page. Also accessible within the [Menu].
2. Press [More] to toggle between the three pages of pattern options.
3. Press [Rec] to select recording mode and allow editing. Screen buttons
will be unavailable, shown dim, otherwise.
4. The current pattern can be reduced in severals ways. The options
available via the 8 screen buttons are:-
• Press [Shrink Pattern]. The pattern will be reduced by deleting each
second step in the pattern. This will delete any step whether empty
or filled. Effectively halves the pattern length. Option on page 2.
• Adjusting [Length] will also reduce the pattern length. Any steps will
be hidden but will be restored if the pattern length is extended.
Option found on page 1.
5. The [Undo] or [Redo] screen buttons can be used if required to restore
a previous state. These are on pattern page 1.
Original Pattern Affected Pattern
Shrunk Pattern
Step 1 C6 Step 2 C5 40---- P 25 40---- P 25 Step 1 C6 Step 2 C5 40---- P 25 40---- P 25
Step 1
C6 40---- P 25
Step 2
Step 3 Step 3 Step 3
C6 Step 4 Step 4 Step 4
E5 40---- P 25
40---- P 25
Step 5 C6 40---- P 25 Step 5
C6 40---- P 25
Step 6 B5 Step 7 E5 40---- P 25 40---- P 25 Step 6
B5 Step 7
E5 40---- P 25
40---- P 25
Step 8 Step 8
Every 2nd Step Deleted Resulting, Halved Pattern
Polyend Tracker Mini Manual
63
4
Pattern Format
4.4 Copying and Pasting a Pattern.
Patterns can be copied and pasted between different pattern slots. This will
copy the entire pattern and its steps as well as the length configuration.
▌ COPYING AND PASTING A PATTERN
1. 2. 3. 4. 5. 6. 7. 8. Press [1] to open the ‘Pattern’ page. Also accessible within the [Menu].
The options on pages 1 & 2 are required during this process. Press
[More] to toggle between the pages of pattern options.
Press [Rec] to select recording mode and allow editing. Screen buttons
will be unavailable, shown dim, otherwise.
On pattern page 1, select the pattern to copy, Hold [Pattern] screen
button + (Up) or (Down). Example, select pattern 1.
On pattern page 2, Press [Copy Pattern] screen button. The pattern is
copied to the clipboard.
On pattern page 1, select the pattern to paste into, Hold [Pattern]
screen button, + (Up) or (Down). Example, select pattern 2.
On pattern page 2, Press [Paste Pattern] screen button. The pattern is
pasted into the current pattern and will overwrite any existing data. It is
possible to continue to paste the pattern to other pattern slots.
The [Undo] or [Redo] screen buttons can be used if required to restore
a previous pattern state.
NOTES
64 Polyend Tracker Mini Manual
NOTES
Pattern Format 4
4.5 Inverting a Selection of Steps.
Patterns are created top to bottom and steps assigned in the step rows.
Steps once selected in a pattern can be inverted. This will reverse the order
in which the steps play. For example the first step in the selection will play
last and vice versa.
▌ INVERTING A STEP RANGE IN A PATTERN
1. 2. 3. Press [1] to open the ‘Pattern’ page. Also accessible within the [Menu].
Ensure options page 2 is displayed. Press [More] to toggle between the
two pages of pattern options.
Press [Rec] to select recording mode and allow editing. Screen buttons
will be unavailable, shown dim, otherwise.
4. 5. 6. Navigate to the first step. Press [Shift] + (Up) or (Down) to select the
sequence of steps and / or Press [Shift] + (Left) + (Right) to select steps
across tracks.
Press [Invert] screen button to reverse the order of the range of steps
selected. This reverses the vertical order of the steps. The steps remain
in their respective tracks.
The [Undo] or [Redo] screen buttons can be used if required to restore
a previous state.
Original Range
Inverted Range
Track 1 Track 2 Track 1
Track 2
Step 1 C6 40---- P 25 Step 1
C6 40---- P 25
Step 2 C6 40---- P 25
Step 2
E5 Step 3 C6 Step 4 E5 40---- P 25 40---- P 25
Step 3
C6 40---- P 25
40---- P 25
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

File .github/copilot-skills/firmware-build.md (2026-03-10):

---
applyTo:
  - "firmware/**/*.{cpp,h,ini,sh}"
  - "firmware/BUILD_INSTRUCTIONS.md"
  - "firmware/build_complete.sh"
---

# KB1 Firmware Build Expert

Expert knowledge for building, flashing, and releasing KB1 ESP32-S3 firmware.

## PRIMARY RULE: Always Build Complete Images

**⚠️ CRITICAL:** Never suggest or create app-only binaries for distribution.

```bash
# ✅ CORRECT - Complete image with bootloader
./build_complete.sh

# ❌ WRONG - App-only build (will brick devices!)
pio run --environment seeed_xiao_esp32s3
```

## ESP32-S3 Memory Layout

```
Address    Component           Size      Description
-------    ---------           ----      -----------
0x0        Bootloader          ~14KB     Second stage bootloader
0x8000     Partition Table     ~3KB      Flash partition map
0x10000    Application         ~978KB    Main firmware code
```

**Key differences from original ESP32:**
- Bootloader at **0x0** (not 0x1000!)
- Must specify `--chip esp32s3` in esptool commands

## Build Process

### Automated Build (Recommended)

```bash
cd firmware
./build_complete.sh
```

**Output:** `KB1-firmware-vX.X.X.bin` (~1MB complete image)

**What it does:**
1. Cleans previous build artifacts
2. Builds firmware with PlatformIO
3. Merges bootloader + partitions + app
4. Verifies output file integrity
5. Shows file size and MD5 checksum

### Manual Build (Advanced)

```bash
# Step 1: Build firmware components
python3 -m platformio run --environment seeed_xiao_esp32s3

# Step 2: Locate generated files
# .pio/build/seeed_xiao_esp32s3/bootloader.bin  (~14KB)
# .pio/build/seeed_xiao_esp32s3/partitions.bin  (~3KB)
# .pio/build/seeed_xiao_esp32s3/firmware.bin    (~978KB)

# Step 3: Merge into complete image
python3 ~/.platformio/packages/tool-esptoolpy/esptool.py \
  --chip esp32s3 merge_bin \
  -o KB1-firmware-v1.2.5.bin \
  --flash_mode dio \
  --flash_freq 80m \
  --flash_size 8MB \
  0x0 .pio/build/seeed_xiao_esp32s3/bootloader.bin \
  0x8000 .pio/build/seeed_xiao_esp32s3/partitions.bin \
  0x10000 .pio/build/seeed_xiao_esp32s3/firmware.bin

# Step 4: Verify
ls -lh KB1-firmware-v1.2.5.bin
md5 KB1-firmware-v1.2.5.bin
```

## Flashing Methods

### Method 1: ESPConnect (Recommended for Users)

**URL:** https://thelastoutpostworkshop.github.io/ESPConnect/

**Steps:**
1. Connect KB1 via USB-C
2. Open ESPConnect in Chrome/Edge
3. Click "Flash Tools" → "Download Flash Backup" (save it!)
4. Load firmware .bin file
5. **Check "Erase entire flash"**
6. Click "Flash Firmware"
7. Wait for completion (~30 seconds)

**Advantages:**
- No software installation required
- Works on any platform (Windows/macOS/Linux)
- Browser-based, user-friendly
- Built-in flash backup

### Method 2: PlatformIO CLI (Development)

```bash
# Development upload (app only - for rapid iteration)
pio run --target upload --environment seeed_xiao_esp32s3

# Production upload (complete image)
pio run --target upload --environment seeed_xiao_esp32s3
```

**Port detection:**
- macOS: `/dev/cu.usbmodem*`
- Linux: `/dev/ttyUSB0` or `/dev/ttyACM0`
- Windows: `COM3` or higher

### Method 3: esptool.py (Advanced)

```bash
esptool.py --chip esp32s3 \
  --port /dev/cu.usbmodem14201 \
  --baud 921600 \
  --before default_reset \
  --after hard_reset \
  write_flash 0x0 KB1-firmware-v1.2.5.bin
```

**Baud rates:**
- 921600 (fastest, may fail on some systems)
- 460800 (reliable fallback)
- 115200 (slowest, most compatible)

## Version Management

### Updating Firmware Version

**Example:** Bumping from v1.2.5 to v1.2.6

1. **Update Constants.h:**
```cpp
// firmware/src/objects/Constants.h
#define FIRMWARE_VERSION_MAJOR 1
#define FIRMWARE_VERSION_MINOR 2
#define FIRMWARE_VERSION_PATCH 6
```

2. **Update build script:**
```bash
# firmware/build_complete.sh
FIRMWARE_VERSION="v1.2.6"
```

3. **Update main.cpp:**
```cpp
// firmware/src/main.cpp
SERIAL_PRINTLN("KB1 FIRMWARE v1.2.6 - WITH CHORD MODE");
```

4. **Update README:**
```markdown
# firmware/README.md
**Latest Release:** v1.2.6 — [Release Notes](RELEASE_NOTES_v1.2.6.md)
```

5. **Update web app version:**
```json
// KB1-config/package.json
{
  "version": "1.2.6"
}
```

6. **Create release notes:**
```bash
touch firmware/RELEASE_NOTES_v1.2.6.md
```

7. **Build and test:**
```bash
cd firmware
./build_complete.sh
# Flash to device and test!
```

## Common Build Issues

### Issue: "esptool not found"

**Solution:**
```bash
# Install PlatformIO packages
pio pkg install --platform espressif32

# Or find esptool manually
find ~/.platformio -name "esptool.py"
```

### Issue: "SHA-256 mismatch" on boot

**Cause:** Flashed app-only binary without bootloader

**Solution:** Flash complete image at offset 0x0 with erase

### Issue: "Serial port not found"

**macOS:**
```bash
# List USB devices
ls /dev/cu.*

# Give terminal access to USB
# System Preferences → Security & Privacy → Files and Folders
```

**Linux:**
```bash
# Add user to dialout group
sudo usermod -a -G dialout $USER
# Log out and back in

# Check port permissions
ls -l /dev/ttyUSB0
```

### Issue: "Upload failed" or timeout

**Solutions:**
1. Hold BOOT button while connecting USB
2. Try lower baud rate (460800 or 115200)
3. Use different USB cable (data cable, not charge-only)
4. Try different USB port (avoid hubs)

### Issue: Build fails with "region `iram0_0_seg' overflowed"

**Cause:** Code size exceeded available RAM

**Solutions:**
1. Enable compiler optimizations (`-Os`)
2. Move constants to PROGMEM/Flash
3. Reduce debug output
4. Review large data structures

## PlatformIO Configuration

### platformio.ini Key Settings

```ini
[env:seeed_xiao_esp32s3]
platform = espressif32
board = seeed_xiao_esp32s3
framework = arduino

; Flash settings
board_build.flash_mode = dio
board_build.flash_freq = 80m
board_build.flash_size = 8MB

; Partition scheme
board_build.partitions = default.csv

; Upload settings
upload_speed = 921600
monitor_speed = 115200

; Build flags
build_flags = 
    -DCORE_DEBUG_LEVEL=0
    -DARDUINO_USB_CDC_ON_BOOT=1
```

## Release Checklist

Before creating a GitHub release:

- [ ] Version bumped in all required files (see Version Management)
- [ ] Clean build completed (`./build_complete.sh`)
- [ ] Output file size reasonable (~1MB)
- [ ] MD5 checksum documented
- [ ] Tested on actual hardware (not just compile)
- [ ] Serial debugging verified
- [ ] BLE connection tested
- [ ] Settings persist across reboots
- [ ] Complete image (not app-only)
- [ ] Release notes created
- [ ] GitHub release created with attached .bin file

## Flash Memory Usage

**Current usage (v1.2.5):**
- **Flash:** ~76% full (1MB / 1.3MB available)
- **RAM:** ~16% usage (51KB / 327KB available)

**Monitoring:**
```bash
# Check sizes after build
pio run --target size --environment seeed_xiao_esp32s3

# Or use build script (shows size automatically)
./build_complete.sh
```

**Optimization tips:**
- Use `PROGMEM` for large constant arrays
- Minimize String usage (prefer C strings)
- Enable compiler optimization (`-Os`)
- Remove debug Serial.print() calls

## Troubleshooting Boot Issues

### Device won't boot after flash

1. **Check power supply:**
   - USB cable must provide sufficient current
   - Try different USB port or power adapter

2. **Erase flash and reflash:**
```bash
esptool.py --chip esp32s3 --port /dev/cu.usbmodem14201 erase_flash
esptool.py --chip esp32s3 --port /dev/cu.usbmodem14201 write_flash 0x0 KB1-firmware-v1.2.5.bin
```

3. **Check serial output:**
```bash
pio device monitor
# Look for boot errors, panic messages, or stack traces
```

4. **Restore factory bootloader:**
   - Use ESPConnect to flash original backup
   - Or flash fresh Arduino bootloader from Seeed

## Best Practices

1. **Always test on real hardware** before releasing
2. **Use `build_complete.sh`** for distribution builds
3. **Document MD5 checksums** for releases
4. **Back up flash** before flashing (ESPConnect)
5. **Keep build logs** for debugging
6. **Test at lower baud rates** if upload fails
7. **Monitor flash usage** before adding features
8. **Use descriptive version tags** (v1.2.5, not latest)

---

**Remember:** The ESP32-S3 bootloader is at 0x0, not 0x1000. Always use complete images for distribution!

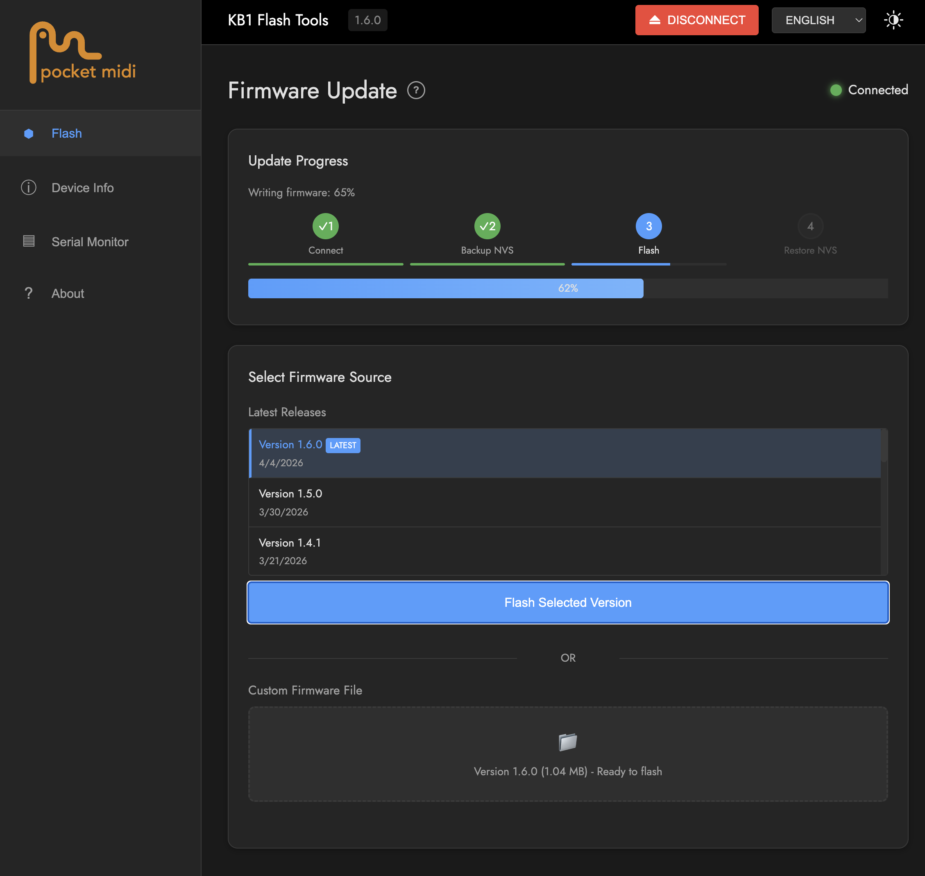
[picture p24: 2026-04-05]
assets/installation/progress.png

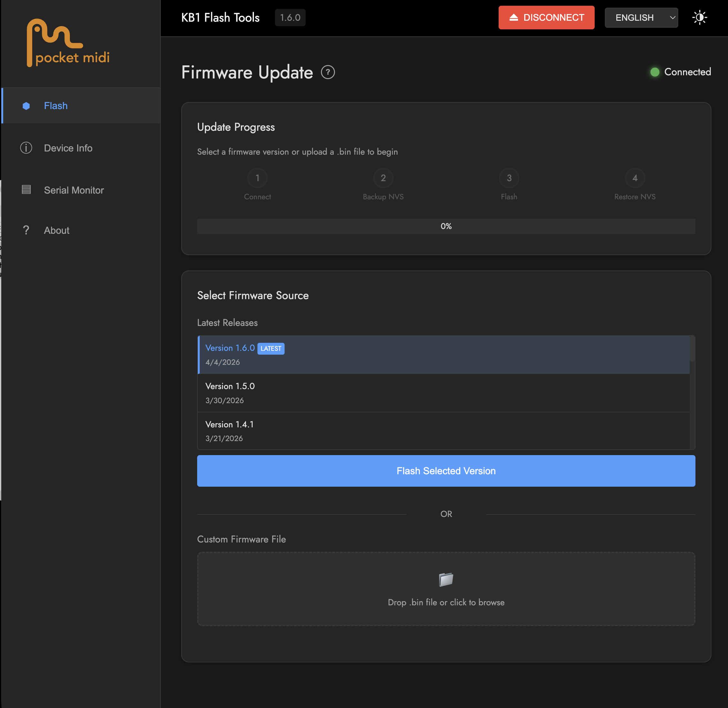
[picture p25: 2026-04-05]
assets/installation/connected.png

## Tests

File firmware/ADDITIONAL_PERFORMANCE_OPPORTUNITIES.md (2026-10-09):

# Additional Performance Optimization Opportunities

> **Historical proposal (April 2026), not a current implementation guide.** Statuses, source line numbers, timing estimates, and power claims below describe the investigation at that time and must be rechecked against current code and hardware. See the [firmware README](README.md) for maintained documentation.

**Date:** April 12, 2026  
**Context:** Beyond I2C bulk reads, what else can improve perceived snappiness?

---

## Summary of Findings

After analyzing the entire codebase, here are all performance optimization opportunities ranked by impact on **user-perceived snappiness**:

| Priority | Optimization | Impact | Difficulty | Status |
|---|---|---|---|---|
| 🔥 **HIGH** | I2C Bulk Reads | **12× faster I/O** | Medium | ✅ **Planned** |
| 🟡 **MEDIUM** | Scan Rate Tuning | 2× faster response | Easy | 🟢 Consider |
| 🟡 **MEDIUM** | Touch Debounce Tuning | 5× faster re-trigger | Easy | 🟢 Consider |
| 🟢 **LOW** | LED Update Optimization | Smoother LEDs | Easy | ⚪ Optional |
| 🟢 **LOW** | Task Priority Review | Marginal latency | Hard | ⚪ Skip |

---

## 🔥 Priority 1: I2C Bulk Reads (PLANNED)

**Status:** Implementation plan created  
**Impact:** 12× faster I/O, -8-12mA power, -5ms input latency  
**See:** `I2C_BULK_READ_IMPLEMENTATION_PLAN.md`

---

## 🟡 Priority 2: Input Scan Rate Tuning

### Current Implementation
**File:** `src/main.cpp:1542`
```cpp
vTaskDelay(10 / portTICK_PERIOD_MS);  // 10ms delay = 100Hz scan rate
```

### Analysis
- **Current scan rate:** 100Hz (every 10ms)
- **With bulk I2C reads:** I2C time drops from 5-6ms to 0.4ms
- **New headroom:** 9.6ms available per cycle instead of 4-5ms

### Optimization Options

#### Option A: Faster Scan Rate (More Responsive)
```cpp
vTaskDelay(5 / portTICK_PERIOD_MS);  // 5ms = 200Hz scan rate
```

**Benefits:**
- ✅ 2× faster input response (10ms → 5ms average latency)
- ✅ Better for rapid note playing (trill, fast runs)
- ✅ More "snappy" feel

**Tradeoffs:**
- ⚠️ Slightly higher CPU usage (~2-3% more)
- ⚠️ Minimal power increase (~1-2mA, negligible)

**Recommendation:** **Try it** — with bulk I2C reads, you have the headroom

---

#### Option B: Adaptive Scan Rate (Smart)
```cpp
// Fast scan when active, slow when idle
unsigned long scanDelay = activityDetected ? 5 : 20;
vTaskDelay(scanDelay / portTICK_PERIOD_MS);
```

**Benefits:**
- ✅ 200Hz when playing (super responsive)
- ✅ 50Hz when idle (power savings)
- ✅ Best of both worlds

**Recommendation:** **Advanced option** — implement after basic bulk I2C works

---

### Impact on User Experience

| Scenario | 10ms (Current) | 5ms (Faster) | Improvement |
|---|---|---|---|
| Single key press | 5ms avg latency | 2.5ms avg | **2× faster** |
| Rapid notes (8th notes @ 120 BPM) | May miss <10ms hits | Catches all | **More reliable** |
| Lever sweeps | Smooth | Smoother | **Marginal** |
| Chord strum | Good | Great | **Noticeable** |

**User perception:** "The keyboard feels more responsive and immediate"

---

## 🟡 Priority 3: Touch Sensor Debounce Optimization

### Current Implementation
**File:** `src/controls/TouchControl.h:29, 282`
```cpp
_touchDebounceTime(250),  // 250ms debounce
```

### Analysis
- **250ms is conservative** for EMI rejection
- **Pattern Selector use case:** User wants to rapidly cycle through patterns
- **Current behavior:** Must wait 250ms between touches (feels sluggish)

### Optimization

#### For Toggle Mode (Pattern Selector)
The code already uses **adaptive smoothing** for Toggle mode (line 60):
```cpp
float smoothingAlpha = (_settings.functionMode == TouchFunctionMode::TOGGLE) ? 0.3f : _smoothingAlpha;
```

**Suggestion:** Also reduce debounce for Toggle mode:

```cpp
// In TouchControl constructor:
_touchDebounceTime(250),  // Keep 250ms for Hold/Continuous
_toggleDebounceTime(50),  // NEW: 50ms for Toggle mode (faster re-trigger)
```

**In update():**
```cpp
unsigned long debounceTime = (_settings.functionMode == TouchFunctionMode::TOGGLE) 
    ? _toggleDebounceTime 
    : _touchDebounceTime;
```

**Impact:** 
- ✅ Pattern selection feels **5× more responsive** (250ms → 50ms)
- ✅ No false triggers (tested in v1.6.x with adaptive smoothing)
- ✅ Better UX for pattern browsing

**Recommendation:** **Safe to implement** — code already has adaptive smoothing for Toggle

---

## 🟢 Priority 4: LED Update Optimization

### Current Implementation
**LEDs use individual writes for on/off states**

**File:** `src/led/LEDController.cpp:126`
```cpp
led->mcp->digitalWrite(led->pin, led->currentBrightness > 0 ? LOW : HIGH);
```

### Optimization Opportunity
- Octave LEDs (up/down) are on same MCP (U2)
- Could batch LED updates using `writeGPIOAB()` for both LEDs at once

### Implementation
1. Track desired LED states
2. Before writing, combine into single 16-bit value
3. Use `mcp->writeGPIOAB()` once instead of 2× `digitalWrite()`

**Impact:**
- ✅ 2× fewer I2C transactions for LED updates
- ✅ Smoother LED transitions
- ⚠️ Marginal power savings (~1mA)

**Recommendation:** **Low priority** — LED updates are infrequent. Only do this if you're bored.

---

## 🟢 Priority 5: Task Priority Review

### Current Task Setup
**File:** `src/main.cpp:1046, 1075`

```cpp
xTaskCreatePinnedToCore(readInputs, "readInputs", 4096, nullptr, 2, nullptr, 1);  // Priority 2
xTaskCreatePinnedToCore(ledTask, "ledTask", 4096, nullptr, 1, nullptr, 1);        // Priority 1
```

### Analysis
- **Input task priority 2** is correct (highest priority for inputs)
- **LED task priority 1** is correct (lower than inputs)
- **Core 1 pinning** is correct (I2C hardware affinity)

**Recommendation:** **No changes needed** — priorities are already optimal

---

## Other Performance Notes (Already Optimized)

### ✅ Serial Output
- v1.3.0 optimized serial output (~85% reduction)
- Only active when terminal connected
- **No further optimization needed**

### ✅ MIDI Throttling
- Lever MIDI uses smart throttling (every 10th message in some cases)
- **Already optimized**

### ✅ I2C Clock Speed
- 400kHz is optimal (v1.3.0)
- **Don't change**

### ✅ Debounce Times
- Keyboard: 10ms (good for mechanical/capacitive switches)
- **Don't reduce** — will cause bounce issues

---

## Recommended Implementation Order

**Phase 1: Foundation (Do This First)**
1. ✅ I2C Bulk Reads → **12× speedup, -8-12mA power**
   - See `I2C_BULK_READ_IMPLEMENTATION_PLAN.md`

**Phase 2: Tuning (After Bulk Reads Work)**
2. 🟢 Reduce scan rate to 5ms → **2× faster input response**
   - Change `vTaskDelay(10 / portTICK_PERIOD_MS)` to `5`
   - Test for stability

3. 🟢 Reduce touch debounce for Toggle mode → **5× faster pattern selection**
   - Add `_toggleDebounceTime(50)` for Toggle mode
   - Keep 250ms for Hold/Continuous

**Phase 3: Polish (Optional)**
4. ⚪ LED bulk write optimization → **Marginal improvement**
   - Only if you want to squeeze out last bit of I2C efficiency

---

## Expected User Experience After All Optimizations

### Before (Current v1.6.x)
- Keyboard: "Good response, occasional lag on fast runs"
- Levers: "Smooth, no complaints"
- Touch: "Pattern selector feels slow to cycle through options"
- Overall: "Solid, but not lightning-fast"

### After (With All Optimizations)
- Keyboard: **"Instant response, like a real piano"**
- Levers: **"Buttery smooth, ultra-responsive"**
- Touch: **"Pattern selector cycles rapidly, no lag"**
- Overall: **"Lightning-fast, professional feel"**

**In other words:** These optimizations take it from "good" to **"exceptional"**

---

## Conservative Approach (If Unsure)

**Just do Phase 1 (Bulk I2C)** and ship it:
- Safest optimization (well-tested pattern)
- Biggest single impact (12× speedup)
- Largest power savings (-8-12mA)
- No UX tradeoffs

You can always add Phase 2 tuning later if users request "even faster" response.

---

## Summary Table: Bang for Buck

| Optimization | Implementation Time | User Impact | Risk Level |
|---|---|---|---|
| I2C Bulk Reads | 2.5 hours | **HUGE** (12× faster) | Low |
| Scan Rate → 5ms | 5 minutes | **Large** (2× faster) | Low |
| Touch Debounce | 15 minutes | **Medium** (5× re-trigger) | Low |
| LED Bulk Write | 1 hour | Small (smoother LEDs) | Low |

**Recommendation:** Do the first three. Skip LED optimization unless you're perfectionist.

---

## Questions to Consider

1. **Do users complain about lag?** → If yes, do all optimizations
2. **Is battery life critical?** → Definitely do bulk I2C (saves most power)
3. **Do you use Pattern Selector often?** → Reduce touch debounce for Toggle
4. **Are you a performance enthusiast?** → Do everything, benchmark, geek out

**Most users will be thrilled with just bulk I2C optimization alone.**

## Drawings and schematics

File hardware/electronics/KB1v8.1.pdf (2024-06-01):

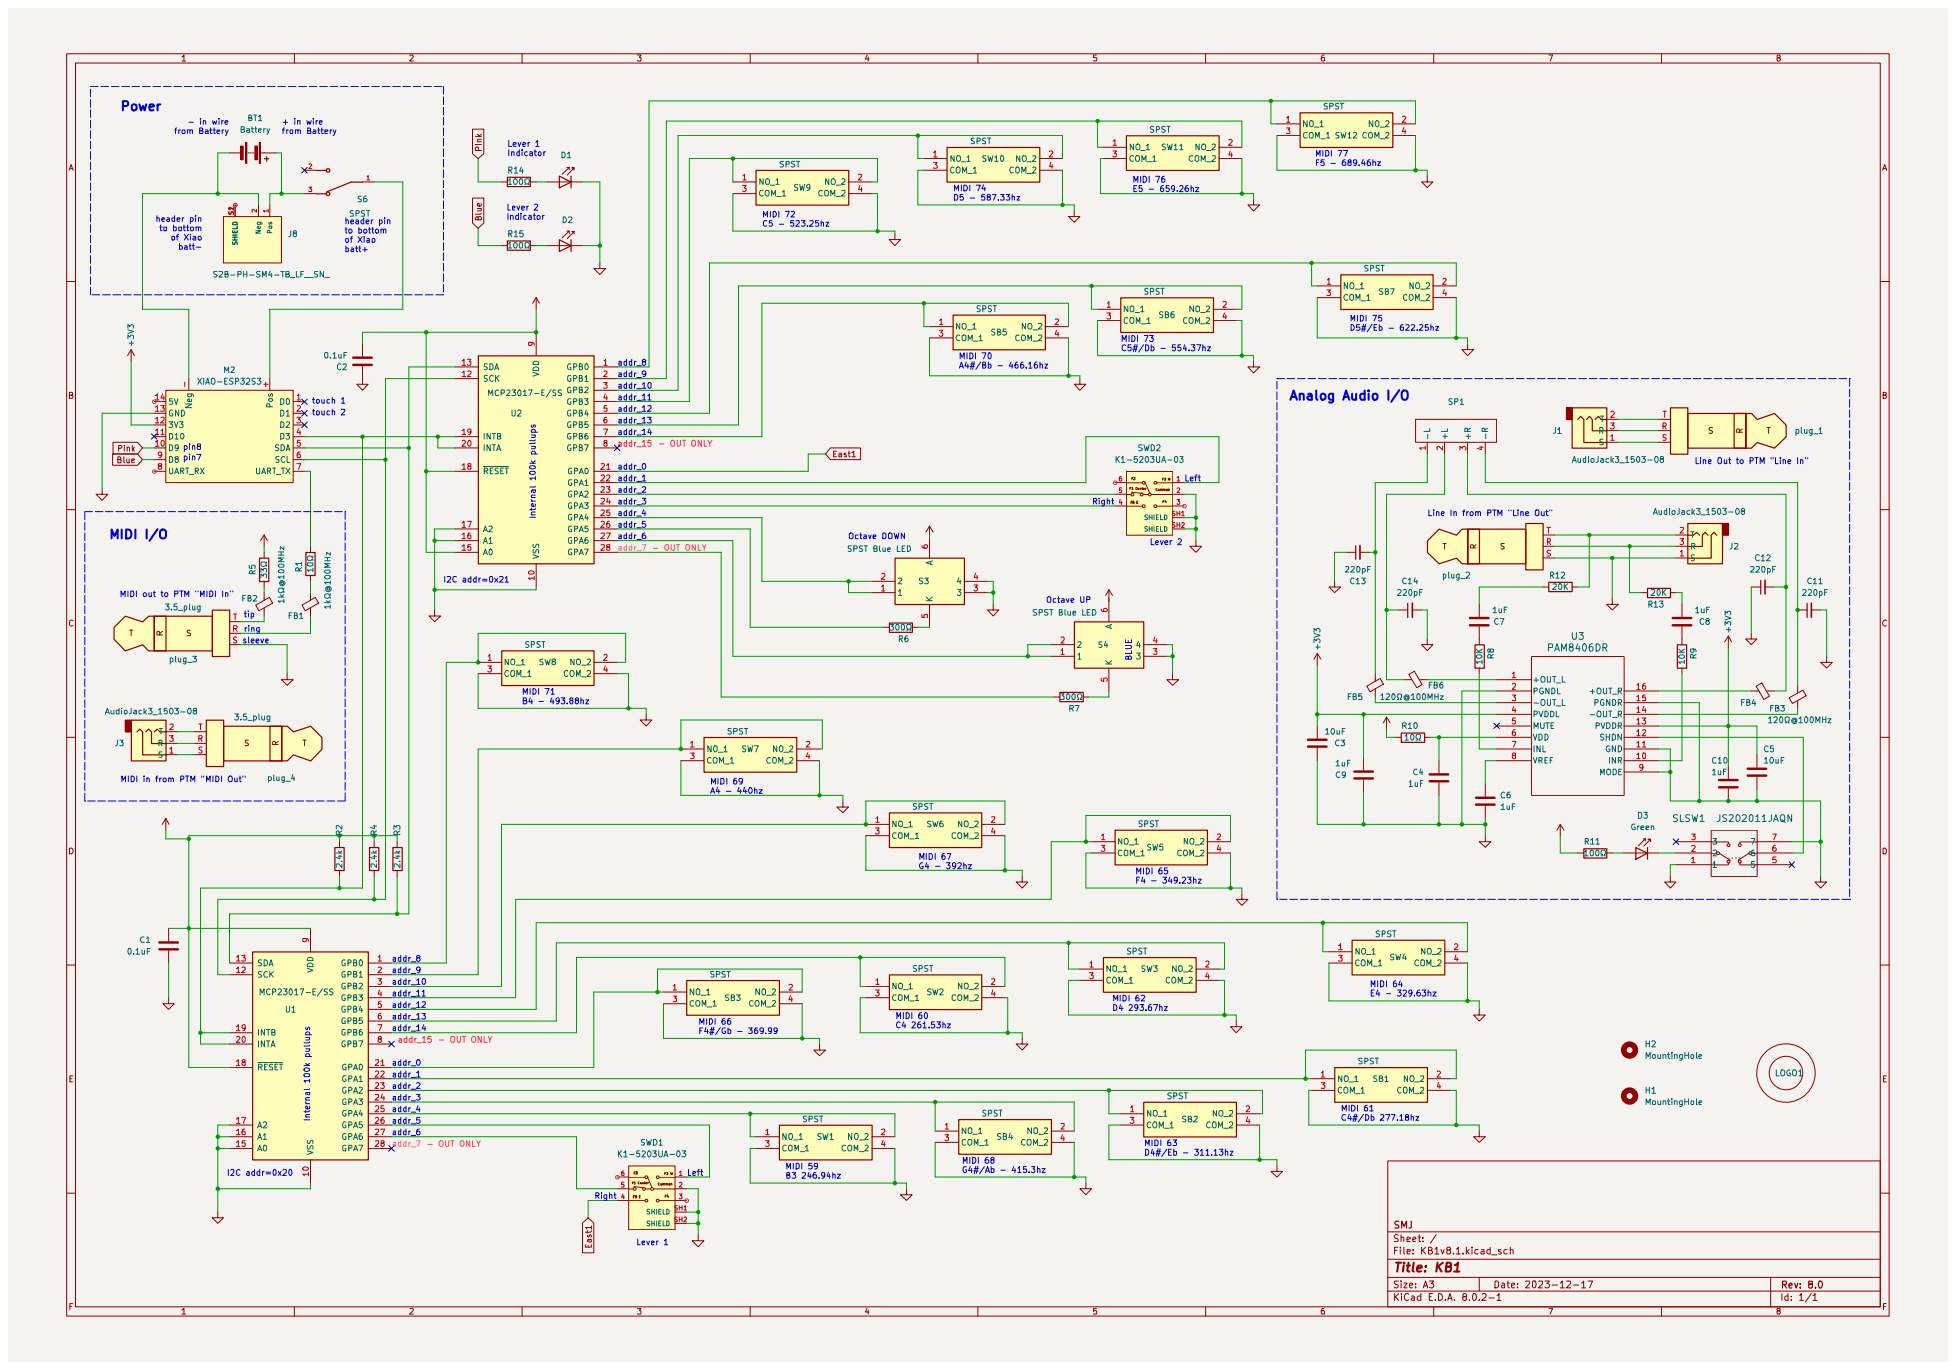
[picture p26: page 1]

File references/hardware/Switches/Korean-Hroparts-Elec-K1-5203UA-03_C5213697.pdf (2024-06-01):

# ROHS

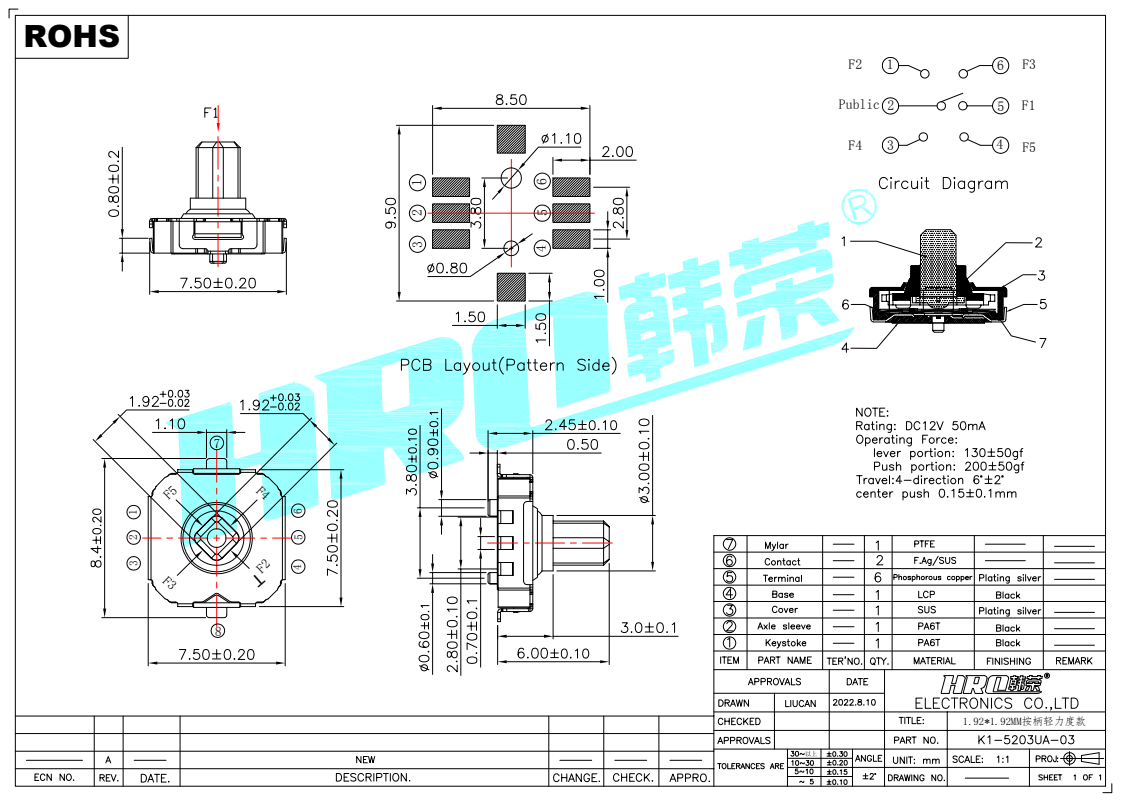
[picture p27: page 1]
1.92*1.92MM按柄轻力度款; Public

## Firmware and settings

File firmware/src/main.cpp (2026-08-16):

/*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
 */

#include <Arduino.h>
#include <Adafruit_MCP23X17.h>
#include <Preferences.h>
#include <MIDI.h>
#include <freertos/FreeRTOS.h>
#include <freertos/task.h>
#include <freertos/semphr.h>
#include <freertos/queue.h>
#include <BLEDevice.h>
#include <esp_bt_main.h>
#include <esp_sleep.h>
#include <esp_system.h>
#include <driver/gpio.h>
#include <driver/rtc_cntl.h>
#include <soc/uart_reg.h>
#include <soc/rtc_cntl_reg.h>
#include <soc/usb_serial_jtag_reg.h>
#include <soc/usb_serial_jtag_struct.h>
#include <bt/BluetoothController.h>
#include <objects/Constants.h>
#include <objects/Globals.h>
#include <objects/Settings.h>
#include <led/LEDController.h>
#include <music/ScaleManager.h>
#include <music/StrumPatterns.h>
#include <controls/KeyboardControl.h>
#include <controls/LeverControls.h>
#include <controls/TouchControl.h>
#include <controls/LeverPushControls.h>
#include "controls/OctaveControl.h"
#include <controls/BLEGestureControl.h>
#include <controls/SleepControl.h>

Adafruit_MCP23X17 mcp_U1;
Adafruit_MCP23X17 mcp_U2;

// Global flag for serial connection detection
#ifdef SERIAL_PRINT_ENABLED
bool serialConnected = false;
bool cpuStatsEnabled = false;  // Toggle CPU profiling output
#endif

LEDController ledController;

// Custom strum pattern storage (pattern 7 - modifiable via BLE)
CustomPattern customPattern = {
    .intervals = {0, 2, 4, 5, 7, 9, 11, 12, 0, 0, 0, 0, 0, 0, 0, 0},
    .length = 8
};

// Lever cooldown after BLE toggle (prevents MIDI output during lever release)
unsigned long leverCooldownUntil = 0;

// Callbacks for syncing lever values when settings change via BLE
void (*syncLever1Callback)() = nullptr;
void (*syncLeverPush1Callback)() = nullptr;
void (*syncLever2Callback)() = nullptr;
void (*syncLeverPush2Callback)() = nullptr;

// Callback for notifying BLE when chord settings change from firmware
void (*notifyChordSettingsCallback)() = nullptr;

// Callback for notifying BLE when scale settings change from firmware
void (*notifyScaleSettingsCallback)() = nullptr;

// Callback for resetting pattern controls when shape mode is disabled
void (*resetPatternControlsCallback)() = nullptr;

// I2C mutex for thread-safe access to MCP23017 chips
static SemaphoreHandle_t i2cMutex = NULL;

// LED command queue to serialize all access to ledController from one task
typedef struct {
    uint8_t type; // 0 = set immediate, 1 = set with ramp
    uint8_t color;
    int value;
    unsigned long dur;
} LedCommand;

static QueueHandle_t ledQueue = NULL;

// Enqueue LED set (immediate)
static inline void ledSet(LedColor color, int value) {
    if (!ledQueue) {
        ledController.set(color, value);
        return;
    }
    LedCommand cmd = {0, (uint8_t)color, value, 0};
    xQueueSendToBack(ledQueue, &cmd, 0);
}

// Enqueue LED set with ramp/duration
static inline void ledSetRamp(LedColor color, int value, unsigned long dur) {
    if (!ledQueue) {
        ledController.set(color, value, dur);
        return;
    }
    LedCommand cmd = {1, (uint8_t)color, value, dur};
    xQueueSendToBack(ledQueue, &cmd, 0);
}

// LED update task (runs on a separate core) — sole owner of ledController
void ledTask(void *pvParameters) {
    (void)pvParameters;
    LedCommand cmd;
    while (true) {
        // Process any queued commands first
        while (ledQueue && xQueueReceive(ledQueue, &cmd, 0) == pdTRUE) {
            if (cmd.type == 0) {
                ledController.set((LedColor)cmd.color, cmd.value);
            } else {
                ledController.set((LedColor)cmd.color, cmd.value, cmd.dur);
            }
        }
        // Always call update from this task (with I2C mutex protection)
        if (xSemaphoreTake(i2cMutex, portMAX_DELAY) == pdTRUE) {
            ledController.update();
            xSemaphoreGive(i2cMutex);
        }
        vTaskDelay(1 / portTICK_PERIOD_MS);
    }
}

// Pink LED PWM control variables
const int PINK_LED_PWM_PIN = 8; // Update if different
// Ramping handled by LEDController via set(color, target, duration)
const int PWM_MAX = 255;
const int PWM_MIN = 0;
const int PINK_PWM_MAX = PWM_MAX / 4; // Pink LED max brightness at 25%

// Blue LED PWM control variables
const int BLUE_LED_PWM_PIN = 7; // Update if different
// (state tracking moved to read loop)
bool blueLedWasPressed = false;

// Lever push state tracking for blue and pink LED effects
bool leverPushWasPressed = false;
bool leverPushIsPressed = false;
// Ramping durations (ms)
const unsigned long PINK_RAMP_UP_MS = 50;
const unsigned long PINK_RAMP_DOWN_MS = 150;
const unsigned long BLUE_RAMP_UP_MS = 50;
const unsigned long BLUE_RAMP_DOWN_MS = 150;

MIDI_CREATE_INSTANCE(HardwareSerial, Serial0, MIDI);

// Forward declaration for keyboard control (defined later in setup)
void clearKeyboardNoteTracking();

// MIDI reliability helpers: explicit TX buffer management
// These ensure critical MIDI messages are fully transmitted before continuing

inline void waitForMidiTxDrain() {
    // Wait for TX buffer to drain (all queued MIDI messages transmitted)
    // At 31250 baud: ~320 bytes/second, 512-byte buffer = ~1.6 seconds worst case
    unsigned long startMs = millis();
    while (Serial0.availableForWrite() < 480 && (millis() - startMs) < 2000) {
        delay(10);  // Check every 10ms
    }
}

inline void sendMidiPanic() {
    // Send All Notes Off + Reset All Controllers to all 16 channels
    // Used before sleep, on boot, and during critical state changes
    for (int ch = 1; ch <= 16; ch++) {
        MIDI.sendControlChange(123, 0, ch);  // All Notes Off
        MIDI.sendControlChange(121, 0, ch);  // Reset All Controllers
    }
    waitForMidiTxDrain();  // Ensure all panic messages are transmitted
    
    // CRITICAL: Clear internal note tracking to prevent guard in stopMidiNote()
    // from blocking valid note-offs after panic. Without this, _isNoteOn[] could
    // get out of sync with actual MIDI state, causing stuck notes.
    clearKeyboardNoteTracking();
}

//----------------------------------
// Octave Control Setup
//----------------------------------
OctaveControl<Adafruit_MCP23X17, LEDController> octaveControl(
    mcp_U2,
    ledController
);

//----------------------------------
// ScaleManager Setup
//----------------------------------
ScaleSettings scaleSettings = {
    .scaleType = ScaleType::CHROMATIC,
    .rootNote = 60,
    .keyMapping = 0, // 0 = Natural, 1 = Compact
};
ScaleManager scaleManager(scaleSettings);

//----------------------------------
// Chord Settings
//----------------------------------
ChordSettings chordSettings = {
    .playMode = PlayMode::SCALE,
    .chordType = ChordType::MAJOR,
    .strumEnabled = true,
    .velocitySpread = 10,
    .strumSpeed = 110,  // 110ms default
    .strumPattern = 4,  // Default to Contract (P4)
    .strumSwing = 15,   // 65% UI (15 firmware = subtle swing for ARP)
    .gateValue = 35,    // Raw 35 maps to ~64% displayed chord swing
    .voicing = 2,       // 2x octave range by default
    .arpUserMode = 0,   // CHORD mode (chord-based arp, not user-defined sequence)
    .arpLatchMode = 1   // LATCHED (stop on last key release)
};

//----------------------------------
// KeyboardControl Setup
//----------------------------------
KeyboardControl<decltype(MIDI), decltype(octaveControl)> keyboardControl(
    MIDI,
    octaveControl,
    scaleManager,
    chordSettings
);

// Implementation of forward-declared helper for sendMidiPanic()
void clearKeyboardNoteTracking() {
    keyboardControl.clearNoteTracking();
}

//----------------------------------
// Lever 1 Setup
//----------------------------------
LeverSettings lever1Settings = {
    .ccNumber = 208,
    .minCCValue = 0,
    .maxCCValue = 127,
    .stepSize = 1,
    .functionMode = LeverFunctionMode::PITCH_BEND,
    .valueMode = ValueMode::BIPOLAR,
    .onsetTime = 25,
    .offsetTime = 25,
    .onsetType = InterpolationType::LINEAR,
    .offsetType = InterpolationType::LINEAR,
};
LeverControls<decltype(MIDI)> lever1(
    &mcp_U1,
    &mcp_U2,
    SWD1_LEFT_PIN,
    SWD1_RIGHT_PIN,
    lever1Settings,
    MIDI,
    ledController,
    LedColor::PINK,
    keyboardControl,
    chordSettings,
    scaleManager
);

//----------------------------------
// LeverPush 1  Setup
//----------------------------------
LeverPushSettings leverPush1Settings = {
    .ccNumber = 209,
    .minCCValue = 0,
    .maxCCValue = 127,
    .functionMode = LeverPushFunctionMode::SUSTAIN,
    .onsetTime = 500,
    .offsetTime = 0,
    .onsetType = InterpolationType::LOGARITHMIC,
    .offsetType = InterpolationType::LOGARITHMIC,
};
LeverPushControls<decltype(MIDI)> leverPush1(
    &mcp_U1,
    SWD1_CENTER_PIN,
    leverPush1Settings,
    lever1,
    MIDI,
    ledController,
    LedColor::PINK,
    keyboardControl,
    chordSettings,
    scaleManager
);

//----------------------------------
// Lever 2 Setup
//----------------------------------
LeverSettings lever2Settings = {
    .ccNumber = 128,
    .minCCValue = 13,
    .maxCCValue = 127,
    .stepSize = 6,
    .functionMode = LeverFunctionMode::INCREMENTAL,
    .valueMode = ValueMode::UNIPOLAR,
    .onsetTime = 100,
    .offsetTime = 100,
    .onsetType = InterpolationType::LINEAR,
    .offsetType = InterpolationType::LINEAR,
};
LeverControls<decltype(MIDI)> lever2(
    &mcp_U2,
    &mcp_U2,
    SWD2_LEFT_PIN,
    SWD2_RIGHT_PIN,
    lever2Settings,
    MIDI,
    ledController,
    LedColor::BLUE,
    keyboardControl,
    chordSettings,
    scaleManager
);

//----------------------------------
// LeverPush 2 Setup
//----------------------------------
LeverPushSettings leverPush2Settings = {
    .ccNumber = 128,
    .minCCValue = 85,
    .maxCCValue = 85,
    .functionMode = LeverPushFunctionMode::RESET,
    .onsetTime = 100,
    .offsetTime = 100,
    .onsetType = InterpolationType::LINEAR,
    .offsetType = InterpolationType::LINEAR,
};
LeverPushControls<decltype(MIDI)> leverPush2(
        &mcp_U2,
        SWD2_CENTER_PIN,
        leverPush2Settings,
        lever2,
        MIDI,
        ledController,
        LedColor::BLUE,
        keyboardControl,
        chordSettings,
        scaleManager
);

//----------------------------------
// Touch Sensor Setup
//----------------------------------
TouchSettings touchSettings = {
    .ccNumber = 1,
    .minCCValue = 38,   // 30% (range: 0-127 maps to 0-100%)
    .maxCCValue = 114,  // 90%
    .functionMode = TouchFunctionMode::CONTINUOUS,
    .threshold = 36800,  // 20% (range: 30000-64000 maps to 0-100%)
    .offsetTime = 100,  // REV mode (release returns to max)
};
TouchControl<decltype(MIDI)> touch(
    T1,
    touchSettings,
    30000,
    64000,
    MIDI,
    chordSettings,
    ledController,
    scaleManager
);

SystemSettings systemSettings = {
    .lightSleepTimeout = 300,   // 5 minutes
    .deepSleepTimeout = 120,    // 2 minutes
    .bleTimeout = 600,          // 10 minutes
    .idleConfirmTimeout = 2,    // 2 seconds
};

Preferences preferences;
BluetoothController* bluetoothControllerPtr = nullptr;

// BLE Gesture Control - cross-lever gesture to toggle BLE
BLEGestureControl* bleGestureControl = nullptr;

// Battery state tracking
BatteryState batteryState = {
    .accumulatedDischargeMs = 0,
    .lastUpdateMs = 0,
    .accumulatedChargeMs = 0,
    .chargeSessionStartMs = 0,
    .lastSaveMs = 0,
    .calibrationTimestamp = 0,  // 0 = never calibrated
    .lastUsbState = false,
    .isFullyCharged = false,
    .isChargingMode = false,  // true only if valid sequence: boot on battery -> plug USB
    .estimatedPercentage = 254,  // 254 = uncalibrated (needs full charge)
    .activeTimeMs = 0,
    .lightSleepTimeMs = 0,
    .deepSleepTimeMs = 0,
    .bleLiveTimeMs = 0,    // v1.7.0 BLE adaptive power tracking
    .bleConfigTimeMs = 0,
    .bleIdleTimeMs = 0,
    .lastModeChangeMs = 0
};

// Track if USB was connected at boot (bypass mode - no charging)
bool usbConnectedAtBoot = false;
bool firstBatteryUpdate = true;  // Flag to detect USB at boot on first update

//----------------------------------
// Sleep / Deep Sleep Management
//----------------------------------
unsigned long lastActivityMillis = 0;
unsigned long lastPlayActivityMs = 0;  // 0 = no play input yet; used for charge LED suppression
unsigned long lightSleepIdleMs = 300000; // Default: 5 minutes
bool deepSleepTriggered = false;

// Require a short, confirmed quiet window before starting the deep-sleep countdown
unsigned long idleConfirmMs = 2000; // Default: 2s, updated from systemSettings
unsigned long idleStartMillis = 0;
bool idleConfirmed = false;
unsigned long idleConfirmTime = 0;

// Forward declare touch wake callback so it can be referenced by sleep routines
void IRAM_ATTR touchWakeCallback();

// Enter a light-sleep mode with a simple LED heartbeat sequence.
// The sequence runs while the MCU repeatedly enters short light-sleep intervals
// (3s) to conserve power. If touch wake is sensed, return to normal operation.
// If no input for the configured light-sleep window (5 minutes), fall back
// to the deep-sleep path.
// Light / deep-sleep implementations moved to controls/SleepControl.h

// Touch wake callback (called when touch interrupt fires)
void IRAM_ATTR touchWakeCallback() {
    // empty: waking is handled by hardware wake source
}

void readInputs(void *pvParameters);
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
void loop() {
    // Update battery monitoring (tracks USB connection and discharge)
    static unsigned long lastBatteryUpdate = 0;
    
    // Fast polling (1s) for first 60 seconds for responsive USB detection, then slow down to 30s
    unsigned long pollInterval = (millis() < 60000) ? 1000 : 30000;
    
    // Plug/unplug must be handled immediately, not on the next slow poll
    bool usbEdgeDetected = (isUsbPowered() != batteryState.lastUsbState);
    
    if (usbEdgeDetected || millis() - lastBatteryUpdate > pollInterval) {
        updateBatteryMonitoring();
        
        // Update BLE characteristic if enabled
        if (bluetoothControllerPtr) {
            bluetoothControllerPtr->updateBatteryStatus();
        }
        
        lastBatteryUpdate = millis();
    }
    
    // Update charging LED pattern when actively charging
    // Check both isChargingMode AND current USB state for immediate response
    static bool wasCharging = false;
    static bool chargingLEDsEnabled = false; // Guard flag
    static unsigned long chargingModeStartMs = 0;  // Track when charging started
    static unsigned long estimatedChargeDurationMs = BATTERY_FULL_CHARGE_MS;  // Estimated time to full charge
    static uint8_t lastBatteryPercentAtChargeStart = 254;  // Track to detect manual % changes
    static uint8_t usbDisconnectCount = 0;  // Debounce counter for USB disconnect
    const uint8_t USB_DISCONNECT_THRESHOLD = 3;  // Require 3 consecutive misses before stopping
    const unsigned long USB_CHECK_GRACE_PERIOD = 180000;  // 3 minutes - after this, ignore frame counter (computer may sleep)
    const unsigned long MIN_CHARGE_LED_DURATION = 1800000;  // 30 minutes minimum LED pulse time
    
    // Real-time USB check (cached 100ms internally, safe to call every loop)
    bool usbCurrentlyConnected = isUsbPowered();
    
    // Track when charging mode starts OR when user manually adjusts battery %
    bool chargingJustStarted = (batteryState.isChargingMode && chargingModeStartMs == 0);
    bool batteryPercentChanged = (batteryState.isChargingMode && 
                                   batteryState.estimatedPercentage != lastBatteryPercentAtChargeStart &&
                                   lastBatteryPercentAtChargeStart != 254);  // Don't trigger on first init
    
    if (chargingJustStarted || batteryPercentChanged) {
        chargingModeStartMs = millis();  // Reset timer when charging starts or % manually changed
        lastBatteryPercentAtChargeStart = batteryState.estimatedPercentage;
        
        // Calculate estimated charge time based on current battery %
        if (batteryState.estimatedPercentage < 254 && batteryState.estimatedPercentage < 100) {
            float remainingPercent = 100.0f - batteryState.estimatedPercentage;
            estimatedChargeDurationMs = (remainingPercent / 100.0f) * BATTERY_FULL_CHARGE_MS;
            
            // Round up to nearest 10 minutes (600000ms)
            estimatedChargeDurationMs = ((estimatedChargeDurationMs + 599999) / 600000) * 600000;
            
            // Apply 30-minute minimum
            if (estimatedChargeDurationMs < MIN_CHARGE_LED_DURATION) {
                estimatedChargeDurationMs = MIN_CHARGE_LED_DURATION;
            }
            
            SERIAL_PRINT("Charge time est: ");
            SERIAL_PRINT(estimatedChargeDurationMs / 60000);
            SERIAL_PRINT("min (from ");
            SERIAL_PRINT(batteryState.estimatedPercentage);
            SERIAL_PRINTLN("%)");
        } else {
            // Uncalibrated or already at 100% - use full 5-hour charge
            estimatedChargeDurationMs = BATTERY_FULL_CHARGE_MS;
        }
    } else if (!batteryState.isChargingMode) {
        chargingModeStartMs = 0;  // Reset when not charging
        lastBatteryPercentAtChargeStart = 254;  // Reset tracker
    }
    
    // Calculate how long we've been in charging mode
    unsigned long chargeElapsed = chargingModeStartMs > 0 ? (millis() - chargingModeStartMs) : 0;
    
    // Check if estimated charge duration has elapsed OR battery reached 100%
    bool estimatedChargeComplete = (chargeElapsed >= estimatedChargeDurationMs);
    bool batteryFull = (batteryState.estimatedPercentage >= 100);
    
    // Only check USB frame counter during grace period (first 3 minutes)
    // After that, assume computer might sleep - trust estimated charge timer instead
    bool shouldCheckUSB = (chargeElapsed < USB_CHECK_GRACE_PERIOD);
    bool usbActuallyDisconnected = false;
    
    if (shouldCheckUSB) {
        // Debounce USB disconnect detection to prevent false negatives during blocking operations
        // Sampled every 250ms so the threshold spans real time, not loop iterations
        static unsigned long lastUsbDebounceMs = 0;
        if (millis() - lastUsbDebounceMs >= 250) {
            lastUsbDebounceMs = millis();
            if (!usbCurrentlyConnected) {
                usbDisconnectCount++;
            } else {
                usbDisconnectCount = 0;  // Reset counter if USB detected
            }
        }
        usbActuallyDisconnected = (usbDisconnectCount >= USB_DISCONNECT_THRESHOLD);
    }
    // After grace period: ignore frame counter, LEDs stay on until estimated charge time completes
    
    // Suppress charging LEDs during active play - resume after 30s idle
    // Uses lastActivityMillis which is updated by all key/lever/touch events
    const unsigned long CHARGE_LED_PLAY_SUPPRESS_MS = 30000;  // 30s after last play input
    bool playActivitySuppressed = (lastPlayActivityMs > 0) &&
                                   (millis() - lastPlayActivityMs) < CHARGE_LED_PLAY_SUPPRESS_MS;

    if (batteryState.isChargingMode && !usbActuallyDisconnected && !estimatedChargeComplete && !playActivitySuppressed) {
        if (!chargingLEDsEnabled) {
            // Just started (or resumed after play suppression)
            chargingLEDsEnabled = true;
            usbDisconnectCount = 0;  // Reset disconnect counter when starting
            SERIAL_PRINT("Charging LEDs started - usbAtBoot=");
            SERIAL_PRINT(usbConnectedAtBoot);
            SERIAL_PRINT(" isChargingMode=");
            SERIAL_PRINT(batteryState.isChargingMode);
            SERIAL_PRINT(" usbConnected=");
            SERIAL_PRINT(!usbActuallyDisconnected);
            SERIAL_PRINT(" graceActive=");
            SERIAL_PRINTLN(shouldCheckUSB ? "yes" : "no");
        }
        updateChargingLEDPattern();
        wasCharging = true;
    } else {
        // Stop charging LEDs when: USB disconnects, charging mode exits, estimated time elapsed, or battery full
        if (wasCharging || chargingLEDsEnabled) {
            // Disable pattern FIRST to prevent any new ramp commands
            chargingLEDsEnabled = false;
            usbDisconnectCount = 0;  // Reset counter on intentional stop
            chargePatternState = CHARGE_PINK; // Reset state machine
            lastChargePatternUpdate = 0; // Reset timing
            
            // Force clear all LEDs immediately (override any pending ramps)
            ledSet(LedColor::PINK, 0);
            ledSet(LedColor::BLUE, 0);
            ledSet(LedColor::OCTAVE_DOWN, 0);
            ledSet(LedColor::OCTAVE_UP, 0);
            delay(10); // Brief delay to let queued commands process
            // Send again to ensure they're cleared
            ledSet(LedColor::PINK, 0);
            ledSet(LedColor::BLUE, 0);
            ledSet(LedColor::OCTAVE_DOWN, 0);
            ledSet(LedColor::OCTAVE_UP, 0);
            delay(10); // Another delay
            // Third clear for stubborn ramps
            ledSet(LedColor::PINK, 0);
            ledSet(LedColor::BLUE, 0);
            
            SERIAL_PRINT("Charging LEDs stopped - ");
            if (estimatedChargeComplete) {
                SERIAL_PRINT("est.time complete (");
                SERIAL_PRINT(estimatedChargeDurationMs / 60000);
                SERIAL_PRINT("min) ");
            }
            if (batteryFull) {
                SERIAL_PRINT("battery full ");
            }
            SERIAL_PRINT("isChargingMode=");
            SERIAL_PRINT(batteryState.isChargingMode);
            SERIAL_PRINT(" usbConnected=");
            SERIAL_PRINTLN(!usbActuallyDisconnected);
            wasCharging = false;
            SERIAL_PRINTLN("Charging LEDs stopped");
        }
    }
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

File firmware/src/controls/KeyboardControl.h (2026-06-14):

#ifndef KEYBOARD_CONTROL_H
#define KEYBOARD_CONTROL_H

#include <Arduino.h>
#include <Adafruit_MCP23X17.h>
#include <MIDI.h>
#include <objects/Globals.h>
#include <led/LEDController.h>
#include <music/ScaleManager.h>
#include <music/StrumPatterns.h>

template<typename MidiTransport, typename OctaveControlType>
class KeyboardControl {
public:
    KeyboardControl(MidiTransport& midi, OctaveControlType& octaveCtrl, ScaleManager& scaleManager, ChordSettings& chordSettings)
        : _midi(midi),
          _octaveControl(octaveCtrl),
          _scaleManager(scaleManager),
          _chordSettings(chordSettings),
          _currentVelocity(85),
          _minVelocity(15),
          _arpActive(false),
          _arpRootNote(0),
          _arpPattern(nullptr),
          _arpPatternLength(0),
          _arpCurrentIndex(0),
          _arpLastNoteTime(0),
          _arpCurrentNote(-1),
          _arpDirection(1),
          _arpLastPattern(-1),
          _arpShufflePos(0),
          _pitchBendOffset(0),
          _pitchBendOverlapUs(25000),
          _sustainActive(false),
          _sustainReleaseDelayMs(200),
          _arpUserLatchPanicArmed(false),
          _strumActive(false),
          _activeStrumKey(0),
          _strumInProgress(false),
          _strumCount(0),
          _strumCurrentIndex(0),
          _strumLastNoteTime(0),
          _userArpCount(0)
    {
        memset(_isNoteOn, false, sizeof(_isNoteOn));
        memset(_baseNote, 0, sizeof(_baseNote));
        memset(_userArpNotes, 0, sizeof(_userArpNotes));
        memset(_strumNotes, 0, sizeof(_strumNotes));
        memset(_strumVelocities, 0, sizeof(_strumVelocities));
        memset(_strumNoteOffTimes, 0, sizeof(_strumNoteOffTimes));
        memset(_activeChordNotes, 0, sizeof(_activeChordNotes));
        memset(_activeChordCount, 0, sizeof(_activeChordCount));
        memset(_pbPendingOffNote, 0, sizeof(_pbPendingOffNote));
        memset(_pbPendingOffDueUs, 0, sizeof(_pbPendingOffDueUs));
        memset(_pbPendingOffActive, false, sizeof(_pbPendingOffActive));
        memset(_sustainPendingOffNote, 0, sizeof(_sustainPendingOffNote));
        memset(_sustainPendingOffDueUs, 0, sizeof(_sustainPendingOffDueUs));
        memset(_sustainPendingOffActive, false, sizeof(_sustainPendingOffActive));

        // Initialize keys array
        _keys[0] = {59, 4, true, true, &mcp_U1, "SW1 (B)"};
        _keys[1] = {60, 14, true, true, &mcp_U1, "SW2 (C)"};
        _keys[2] = {61, 1, true, true, &mcp_U1, "SB1 (C#)"};
        _keys[3] = {62, 13, true, true, &mcp_U1, "SW3 (D)"};
        _keys[4] = {63, 2, true, true, &mcp_U1, "SB2 (D#)"};
        _keys[5] = {64, 12, true, true, &mcp_U1, "SW4 (E)"};
        _keys[6] = {65, 11, true, true, &mcp_U1, "SW5 (F)"};
        _keys[7] = {66, 0, true, true, &mcp_U1, "SB3 (F#)"};
        _keys[8] = {67, 10, true, true, &mcp_U1, "SW6 (G)"};
        _keys[9] = {68, 3, true, true, &mcp_U1, "SB4 (G#)"};
        _keys[10] = {69, 9, true, true, &mcp_U1, "SW7 (A)"};
        _keys[11] = {70, 14, true, true, &mcp_U2, "SB5 (A#)"};
        _keys[12] = {71, 8, true, true, &mcp_U1, "SW8 (B)"};
        _keys[13] = {72, 11, true, true, &mcp_U2, "SW9 (C)"};
        _keys[14] = {73, 13, true, true, &mcp_U2, "SB6 (C#)"};
        _keys[15] = {74, 10, true, true, &mcp_U2, "SW10 (D)"};
        _keys[16] = {75, 12, true, true, &mcp_U2, "SB7 (D#)"};
        _keys[17] = {76, 9, true, true, &mcp_U2, "SW11 (E)"};
        _keys[18] = {77, 8, true, true, &mcp_U2, "SW12 (F)"};
    }

    static constexpr unsigned long KEY_PRESS_DEBOUNCE_MS = 10;    // ms - keep fast for responsive press
    static constexpr unsigned long KEY_RELEASE_DEBOUNCE_MS = 30;   // ms - longer to survive BLE-induced I2C stalls
    static constexpr unsigned long ARP_USER_LATCH_PANIC_HOLD_MS = 900; // ms
    static constexpr int MAX_CHORD_NOTES = 16;  // Support 3x voicing (5 notes × 3 octaves = 15)
    static constexpr int MAX_PB_PENDING_OFFS = 24;
    static constexpr int MAX_SUSTAIN_PENDING_OFFS = 128;

    // Set the note overlap duration for pitch bend mode retriggers.
    // Called by LeverControls whenever the lever is in PITCH_BEND mode.
    void setPitchBendOverlapUs(unsigned long us) { _pitchBendOverlapUs = us; }

    // Returns true when the arpeggiator is actively running (including latch mode with keys released)
    bool isArpActive() const { return _arpActive; }

    // Sustain timing mode: while active, each key release gets its own delayed NoteOff.
    bool isSustainActive() const { return _sustainActive; }
    void setSustainActive(bool active, unsigned long releaseMs = 0) {
        if (active) {
            // Capture duration used for per-release scheduling.
            _sustainReleaseDelayMs = releaseMs;
            if (!_sustainActive) {
                // Lock pitch bend neutral when sustain engages.
                setPitchBendOffset(0);
                _sustainActive = true;
            }
            return;
        }
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

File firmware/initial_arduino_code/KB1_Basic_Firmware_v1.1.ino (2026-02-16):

/*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
 */

// Uncomment following line to enable Serial Printing /////
#define SERIAL_PRINT_ENABLED 1

#include <Adafruit_MCP23X17.h>
#include <HardwareSerial.h>
#include <MIDI.h>
#include <freertos/FreeRTOS.h>
#include <freertos/task.h>
#include <freertos/timers.h>

// Pin definitions for U1
#define SWD1_LEFT_PIN 5   // SWD1 Left button pin
#define SWD1_CENTER_PIN 6 // SWD1 Center button pin

// Pin definitions for U2
#define SWD1_RIGHT_PIN 0  // SWD1 Right button pin
#define SWD2_LEFT_PIN 1   // SWD2 Left button pin
#define SWD2_CENTER_PIN 2 // SWD2 Center button pin
#define SWD2_RIGHT_PIN 3  // SWD2 Right button pin

// Enable/disable serial printing /////
#ifdef SERIAL_PRINT_ENABLED
#define SERIAL_PRINT(msg) Serial.print(msg)
#define SERIAL_PRINTLN(msg) Serial.println(msg)
#else
#define SERIAL_PRINT(msg)
#define SERIAL_PRINTLN(msg)
#endif

struct key
{
    uint8_t midi;
    uint8_t pin;
    bool state;
    bool prevState;
    Adafruit_MCP23X17 *mcp;
    char name[12];
};

Adafruit_MCP23X17 mcp_U1; // MCP1, named U1
Adafruit_MCP23X17 mcp_U2; // MCP2, named U2

#define MAX_KEYS 19 // define keys
key keys[MAX_KEYS] = {
    {59, 4, true, true, &mcp_U1, "SW1 (B)"},
    {60, 14, true, true, &mcp_U1, "SW2 (C)"},
    {61, 1, true, true, &mcp_U1, "SB1 (C#)"},
    {62, 13, true, true, &mcp_U1, "SW3 (D)"},
    {63, 2, true, true, &mcp_U1, "SB2 (D#)"},
    {64, 12, true, true, &mcp_U1, "SW4 (E)"},
    {65, 11, true, true, &mcp_U1, "SW5 (F)"},
    {66, 0, true, true, &mcp_U1, "SB3 (F#)"},
    {67, 10, true, true, &mcp_U1, "SW6 (G)"},
    {68, 3, true, true, &mcp_U1, "SB4 (G#)"},
    {69, 9, true, true, &mcp_U1, "SW7 (A)"},
    {70, 14, true, true, &mcp_U2, "SB5 (A#)"},
    {71, 8, true, true, &mcp_U1, "SW8 (B)"},
    {72, 11, true, true, &mcp_U2, "SW9 (C)"},
    {73, 13, true, true, &mcp_U2, "SB6 (C#)"},
    {74, 10, true, true, &mcp_U2, "SW10 (D)"},
    {75, 12, true, true, &mcp_U2, "SB7 (D#)"},
    {76, 9, true, true, &mcp_U2, "SW11 (E)"},
    {77, 8, true, true, &mcp_U2, "SW12 (F)"}};

// Define MIDI object
MIDI_CREATE_INSTANCE(HardwareSerial, Serial0, MIDI);

// Forward declarations
void playMidiNote(byte note);
void stopMidiNote(byte note);
void shiftOctave(int shift);
void buttonReadTask(void *pvParameters);
void gotTouch1();

// Touch Shift Mode ///
bool shiftModeEnabled = false;
volatile bool shiftModeActive = false;
int threshold = 1500; // Adjust this value according to your setup
bool touch1detected = false;


// Previous state variables for OCT buttons
volatile bool prevS3State = true;
volatile bool prevS4State = true;

// Previous state variables for Lever 1
bool prevSWD1LeftState = false;
bool prevSWD1CenterState = false;
bool prevSWD1RightState = false;

// Previous state variables for Lever 2
volatile bool prevSWD2LeftState = true;
volatile bool prevSWD2CenterState = true;
volatile bool prevSWD2RightState = true;
bool isSwd2LeftPressed = false;
bool isSwd2RightPressed = false;
bool isSwd2CenterPressed = false;
const int swd2Interval = 200;      // Interval in milliseconds (0.2 seconds)
volatile int currentVelocity = 89; // state variable for velocity value
int minVelocity = 8;

// LED Blue // Velocity // Lever 2 ////////
const int bluePin = 7;
int blueBrightness = 0;
unsigned long previousTime = 0;         // variables for non-blocking timers
const unsigned long ledOffDelay = 3000; // xx seconds in milliseconds

void updateVelocity(int delta)
{
    int previousVelocity = currentVelocity; // Store previous velocity for comparison
    currentVelocity += delta;
    if (currentVelocity < minVelocity) // Ensure velocity is within bounds
        currentVelocity = minVelocity;
    else if (currentVelocity > 127)
        currentVelocity = 127;
    if (delta > 0 || (delta < 0 && blueBrightness < 255 - 25))
    {                                               // Update blue LED brightness based on velocity change
        if (delta > 0 && blueBrightness < 255 - 25) // Increase or decrease brightness xx%
        {
            blueBrightness += 25;
        }
        else if (delta < 0)
        {
            if (currentVelocity <= minVelocity || previousVelocity > minVelocity)
            {
                blueBrightness = 25; // Set initial brightness to xx%
            }
            else if (blueBrightness > 25)
            {
                blueBrightness -= 25;
            }
        }
        analogWrite(bluePin, blueBrightness);
        previousTime = millis(); // Update time when brightness changes
    }
    if (delta > 0 && currentVelocity > previousVelocity)
    { // Report current velocity when it increases or decreases
        SERIAL_PRINT("Current Velocity Increased to: ");
        SERIAL_PRINTLN(currentVelocity);
    }
    else if (delta < 0 && currentVelocity < previousVelocity)
    {
        SERIAL_PRINT("Current Velocity Decreased to: ");
        SERIAL_PRINTLN(currentVelocity);
    }
}
void resetVelocity()
{
    currentVelocity = 89; // Reset velocity to 89
    SERIAL_PRINTLN("Velocity Reset to 89");
    analogWrite(bluePin, 51); // Set LED to xx% brightness
    delay(250);               // Delay for 0.5 seconds
    analogWrite(bluePin, 0);  // Turn off LED
}
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

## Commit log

2024-06-01 Update and rename Firmware/KB1_Connection_Map_FW_v1.0.csv to Firmware/Useful_Info/KB1_Connection_Map_FW_v1.0.csv
    [KB1_Connection_Map_FW_v1.0.csv]
2024-06-01 Update and rename Polyend Tracker Mini MIDI CC's.csv to Polyend Tracker Mini MIDI CC's as of TrackerMini_1.1.csv
    [Polyend Tracker Mini MIDI CC's as of TrackerMini_1.1.csv]
2024-06-01 Update and rename KB1_Connection_Map_FW_v1.0.csv to KB19_Connection_Map_FW_v1.0.csv
    [KB19_Connection_Map_FW_v1.0.csv]
2024-06-01 Update and rename MIDI Notes Scales - To do.csv to MIDI Notes Scales - To do.csv
    [MIDI Notes Scales - To do.csv]
2024-06-01 Update and rename Polyend Tracker Mini MIDI CC's as of TrackerMini_1.1.csv to Polyend Tracker Mini MIDI CC's as of TrackerMini_1.1.csv
    [Polyend Tracker Mini MIDI CC's as of TrackerMini_1.1.csv]
2024-06-01 Update and rename KB19_Connection_Map_FW_v1.0.csv to KB19_Connection_Map_FW_v1.0.csv
    [KB19_Connection_Map_FW_v1.0.csv]
2024-06-01 Update and rename KB19_Connection_Map_FW_v1.0.csv to KB1_Connection_Map_FW_v1.0.csv
    [KB1_Connection_Map_FW_v1.0.csv]
2025-06-23 minor updates
    new images, velocity set to 80 instead of 127
2025-07-01 updates
    more hardware updates
    [LED Arrow Button.stl, LED Indicator 1.stl, Lever 01.stl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]
2025-07-01 modified: remove all existing folders
    [KB1 MIDI Note Map.csv, KB1_Connection_Map_FW_v1.0.csv, LED Arrow Button.stl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]
2025-07-01 modified: readding content in new structure
    [KB1 MIDI Note Map.csv, KB1_Connection_Map_FW_v1.0.csv, LED Arrow Button.stl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]
2025-07-01 modified: updated readme for old arduino code
2025-07-04 added: capacitive touch controller
    - various smaller refactors
2025-07-04 added: initial led controller
2025-07-05 added: octave and keyboard controller
    - updated led controller
2025-07-05 fix: introduced random note generation by accident
    [main.cpp]
2025-07-05 fix: prevstate for keys was not set properly.
    [KeyboardControl.h]
2025-07-05 fix: forgot pull-up for keys
    [KeyboardControl.h]
2025-07-05 modified: encapsulated bluetooth functionality
    - bluetooth can now be enabled / disabled by holding the octave buttons for 3 seconds.
2025-07-06 added: reset function for lever push
    [LeverControls.h, LeverPushControls.h, OctaveControl.h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]
2025-07-06 modified: pass cc 7 assignments to keyboardcontroller for velocity
2025-07-06 modified: added ledcontroller to the lever and leverpush controls
2025-07-06 fixed: not all BLE characteristics were exposed properly
    [BluetoothController.cpp]
2025-07-07 fixed: potential double octave change
    - also increase octave range by +/- 1
    [KeyboardControl.h, OctaveControl.h]
2025-07-07 modified: renamed preferences
    - names were too long
    [main.cpp]
2025-07-08 fix: scale are no working correctly
    [main.cpp]
2025-07-08 modified: velocity exposed in webapp and works in firmware as it should
2025-07-08 new CAD files
    revisions plus new A5 binder frame
    [A5 frame 1a.stl, A5 frame 1b.stl, A5 frame.stl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]
2025-07-11 modified: abuse cc 128 (invalid) as velocity data transport
2025-07-12 revised PCB files
    added PCBWAY files and links
2025-08-16 add leds
    led actions
2025-08-22 updated assembly guide
2025-12-04 Dec 4th updates
    L lever default - cc3(fine-tune) bipolar 0-64-127 linear 100ms
    L push default - cc24(volume release) 32-127 linear 100ms
    R lever default - velocity bipolar incremental steps of 8
    R push default - reset velocity to 81
    Touch default - cc1(cutoff) 64-127 continuous
    added 2 sec lockout to octave buttons after BLE activation/deactivation
    to keep from accidental octave change
    clamped all cc levels to 0-127
    smoothed out touch sensor jitters - exponential smoothing & hysteresis
    added 10ms debounce on keys
    [BluetoothController.cpp, KeyboardControl.h, LeverControls.h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]
2025-12-04 interface
    UI tweaks
    remember velocity
    clean up led actions
    add led for touch
2025-12-13 more tweaks
    added BLE sleep mode
    adjusted octave button sensitivity timing
2025-12-19 timing & updates
    octave buttons adjust
    latest versions
2025-12-20 Deep sleep + touch
    Deep sleep at 5 min. with touch wakeup
    touch sensor adjustments
2025-12-21 references update
    new reference and build files
    [KB1 Connection Map.csv, KB1_Assembly_jig 1.stl, KB1_Connection_Map_FW_v1.0.csv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]
2025-12-22 Light sleep
    added light sleep mode with LED pulse at 5.5 min.
    then deep sleep 7 min.
    wake with touch
2025-12-22 settings and led timing
    create SleepControl.h
    adjust touchpad led
2025-12-23 hardened ble characteristics
    Each characteristic now has an explicit pointer to its destination struct and a preference key. Writes are copied to that pointer directly (no UUID string matching at runtime), which eliminates ambiguity from malformed UUID strings or callback dispatch errors.
    [BluetoothController.cpp]
2025-12-24 LED core separation
    isolated leds to avoid cross-core I2C access
    [LEDController.cpp, main.cpp]
2026-02-11 Update Polyend Tracker MIDI CC map.csv
    [Polyend Tracker MIDI CC map.csv]
2026-02-13 Address code review feedback: use grace period getter and fix callback consistency
    [main.cpp]
2026-02-13 Fix keep-alive ping refresh and millis overflow handling
    [BluetoothController.cpp, main.cpp]
2026-02-14 Update velocity reset value and BLE timeout configuration
    [main.cpp]
2026-02-16 velocity levels
2026-02-17 system timers
2026-02-20 I2C mutex + scales
2026-02-21 bluefy fix
    Bluefiy connects and reads the preset list characteristic
    Each read attempts to load 8 preset slots
    Each empty slot generates an NVS error log
    The error logging fills up the Bluetooth task stack
    Eventually triggers "Stack canary watchpoint" crash
    Now it will silently check if keys exist first, avoiding the error spam and preventing the stack overflow. Upload and test with Bluefiy!
2026-03-01 chord bug fix - v1.1.3
    [Constants.h]
2026-04-04 v1.5.0 HOTFIX: Preserve battery calibration in USB bypass mode
    Critical fixes for battery tracking bugs introduced in v1.5.0:
    1. USB bypass mode no longer resets calibration to uncalibrated (254)
    - Removed estimatedPercentage = 254 line from boot USB detection
    - Users can now boot with USB without losing calibration data
    2. Time tracking fields now persist to NVS across reboots
    - Added batActiveMs, batLightMs, batDeepMs to save/load
    - Fixes incorrect battery percentage after reboot
    - Fields were used in calculations but never saved (v1.4.1+ bug)
    Impact: Users who lost calibration on v1.5.0 can upgrade and recalibrate.
    Calibration will now survive reboots and USB bypass mode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
    [main.cpp]
2026-04-05 docs: add Device Info and Serial Monitor blurbs to flash tool section
2026-04-10 v1.6.1: fix USB bypass detection at boot
    - Capture USB state before loadBatteryState() overwrites it
    - Increase boot delay 50ms -> 150ms for SOF frame stability
    - CDC retry loop now checks isUsbPowered() not just Serial
    (fixes bypass detection when no serial terminal is open)
    - Bump version string to 1.6.1
    - ci: opt into Node.js 24 for notify-flash-tool workflow
    [main.cpp]
2026-04-11 v1.6.2: fix battery set% command and keep-alive notifications
    [BluetoothController.cpp, Constants.h]
2026-04-12 Release v1.7.0 - Major performance improvements
    - I2C bulk read optimization (92% reduction in bus utilization)
    - 2× faster input scan rate (200Hz, down from 100Hz)
    - 5× faster touch sensor debounce for Toggle mode
    - -8-12mA power consumption reduction
    - Added GPIOCache for efficient bulk GPIO operations
2026-05-21 Release KB1 firmware v2.0.1 (fix octave buttons)
    Bump firmware to v2.0.1 and apply hotfix to restore octave button functionality. Restores octaveControl.begin() in setup() to re-enable MCP23017 octave button pins, updates FIRMWARE_VERSION constants and build script, and adds the v2.0.1 binary and release notes. Also updates KB1-config and kb1-flash submodule commits.
    [Constants.h, main.cpp]
2026-05-26 Document new features and update submodules
    Refine README copy and enumerate newly implemented firmware and web-app features: multi-octave chord voicing, voicing/strum/swing options, dedicated pitch-bend and sustain press modes, hardware MIDI 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
2026-06-14 Release v2.1.0: pitch-bend, MIDI fixes, charging
    Bump firmware to v2.1.0 and add KB1 pitch-bend feature plus several reliability and charging improvements. Adds complete kb1-pitch-bend SKILL documentation, firmware binary, and release notes; updates build script for new version. Firmware changes implement fake pitch-bend (CC 208) support in lever logic and KeyboardControl (retriggering, overlap queue, base-note tracking), clamp MIDI values, add MIDI panic/drain helpers, increase Serial0 TX buffer, and send panic on BLE disconnect and before sleep to prevent stuck notes. Battery charging behavior and LED timing improved (smart duration + sleep grace period) and documentation added for correct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
    [Constants.h, KeyboardControl.h, LeverPushControls.h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]
2026-07-11 Add low battery and brownout safeguards
    Release firmware v2.2.0 with graduated low-battery octave LED warnings and a brownout ISR that sends MIDI All Notes Off before reset to prevent stuck notes. This also fixes the v2.1.0 charging LED regression on previously fully calibrated devices, updates the firmware version/build and release notes, and removes the unused `kb1-flash` workspace entry.
    [Constants.h, main.cpp]
2026-08-06 add kicad
2026-08-08 Fix battery calibration and charge LEDs
    Release firmware v2.3.0 with improved charging behavior and battery reporting. The battery BLE status payload now includes accumulated charge time for live calibration progress in the config app, manual battery percentage updates are treated as calibrated and reset stale charge history, and charging LEDs are suppressed during active play using dedicated play-activity tracking. Also updates the firmware version, build script, release notes, and complete firmware image.
    [BluetoothController.cpp, Constants.h, main.cpp]
2026-10-09 Refresh docs and clarify ownership
    Streamline the root, firmware, hardware, and contributing docs around the current multi-repo workflow. This shifts detailed user guidance to the maintained Studio and Configurator guides, adds clearer release and validation expectations, and marks older firmware analysis/proposal documents as historical so they are not mistaken for current implementation guidance.

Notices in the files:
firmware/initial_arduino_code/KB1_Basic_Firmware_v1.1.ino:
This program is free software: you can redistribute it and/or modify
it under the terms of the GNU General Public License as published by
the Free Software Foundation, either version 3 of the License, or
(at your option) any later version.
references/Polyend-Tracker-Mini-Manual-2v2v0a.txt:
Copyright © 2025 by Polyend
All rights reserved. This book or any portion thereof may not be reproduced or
